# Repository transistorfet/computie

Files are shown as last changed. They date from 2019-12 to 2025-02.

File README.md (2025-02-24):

Computie68k
===========

###### *Started October 03, 2019*

Computie is a series of single board computers using the 68010 and 68030 CPUs, along with a simple unix-like
operating system written in C, with preemptive multitasking via a timer interrupt provided by the 68681
serial port controller that is common to all boards.

k30-SBC is the newest board, using a surface-mount 68030 CPU, 2MB of Static RAM, 512KB of Flash for the boot
software and monitor program, and a CompactFlash slot.

68k-SBC is a single board computer with a 68010 CPU, 1MB SRAM, 1MB Flash, and a 68681 Dual UART controller.

68k-SMT is a mostly identical design using SMT and PLCC components.  A CompactFlash card slot has been added
to this version, but it is also possible to connect a simple breadboarded version to 68k-SBC.

For more details on how I got up and running, check out [Bootstrapping a Homebuilt Computer Using An Arduino](https://transistorfet.github.io/posts/2021-09-bootstrapping_with_arduino.html)

For instructions on getting a board set up and software compiled, check out [INSTALL.md](https://github.com/transistorfet/computie/blob/main/INSTALL.md)

This repository uses git submodules, and can be cloned using:
```
git clone --recurse-submodules git@github.com:transistorfet/computie.git
```

ComputieVME - The Next Generation
---------------------------------

The next iteration of this project is ComputieVME, a VME-based MC68030 CPU card, which is part of
the [Retroverse](https://github.com/transistorfet/retroverse/) project, along with a number of other
VME-based components.  The new system also runs the
[Gloworm](https://github.com/transistorfet/gloworm/) operating system.  Development is ongoing and
details can be found in the github repo or at
[jabberwocky.ca](https://jabberwocky.ca/projects/retroverse/).  I also live streamed some of the
designing and building process, with recordings available at
[youtube.com/@transistorfet](https://www.youtube.com/@transistorfet)

The Operating System (Gloworm)
------------------------------

[Gloworm](https://github.com/transistorfet/gloworm/) (now in a separate repository) is largely based on reading
Operating Systems Design and Implementation 2ed by Andrew S. Tanenbaum, although I've gone with a monolithic design, at
least for the time being, for the simplicity of it.  It can do preemptive multitasking using the 68681 timer.  It also
has an implementation of the minix version 1 filesystem, which uses RAM (through a device driver) to store the data, or
a Compact Flash card connected as an IDE device.  The second serial port can be configured as a SLIP device, with a
basic implementation of UDP and TCP through a BSD sockets-style API, and an NTP command is provided for updating the
system time on boot (when booting from disk).

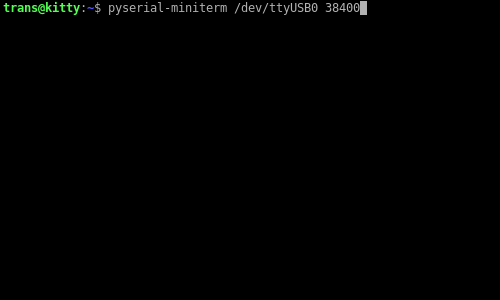
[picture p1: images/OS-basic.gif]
OS


The above video shows connecting over serial from a modern PC and resetting the hardware to run the monitor in ROM
which displays the welcome message.  The kernel is already loaded in RAM, so running the boot command will boot
the kernel which then starts the shell.  From the shell, some basic file operations and the ps command are shown.

The k30 Single Board Computer
-----------------------------

The k30 is the latest version, using a 68030.  It has 2MB SRAM, 512KB Flash, a 68681 Dual UART, and a CompactFlash.
It's as similar to 68k-SMT as possible while still upgrading the CPU.  It doesn't use a programmable logic device for
the glue logic as many similar projects use, instead opting for eleven 74 series logic chips.  It still manages to
use the full 32-bit data bus for RAM, but only one flash chip is used which has an 8-bit data bus in order to reduce
complexity.  Most of the software will be run from RAM, so this shouldn't be a problem.

[k30 Schematics](https://github.com/transistorfet/computie/raw/main/hardware/k30-SBC/k30-SBC.pdf)

DIP switches are used to select the time delay to use for the CompactFlash card (which is interfaced directly to the
CPU), to enable the bus error watchdog timer, and to enable/disable the cache and MMU features.

k30 Revision 2
--------------

This revision fixes the issues of the previous one.  The compact flash card can now be accessed, and the OS is able
to boot entirely from the compact flash card without issue.

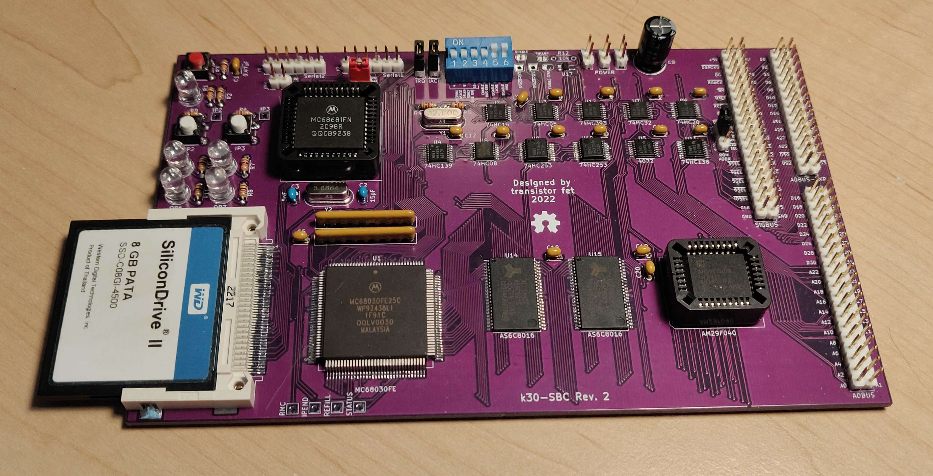
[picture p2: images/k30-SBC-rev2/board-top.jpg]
k30-SBC Rev. 2 Assembled Board


k30 Revision 1
--------------

I made a mistake and used the wrong size footprint for the two 74HC253s, which only come in a 16SSOP package and not
the TSSOP package used by the other logic chips.  The footprint used were 4.9 mm wide but should have been 6.2mm.
Luckily I managed to bend the pins under the body of the chips which was enough to get all the pins touching all the
pads.  It was very tricky to solder, and there was a bridge between DS3 and ground which was very difficult to get
unstuck, but it's working now.

I also made a mistake in the DSACK signals used to terminate a memory cycle, specifically for the compact flash card.
The logic was inverted, so the card was inaccessible, and my attempts at fixing it fried the clock, although it might
have just been the crystal.  I set the project aside for a while and then made a new revision.  For details on the
issues, see the [errata](https://github.com/transistorfet/computie/raw/main/hardware/k30-SBC/revisions/k30-SBC-rev1-errata.txt)

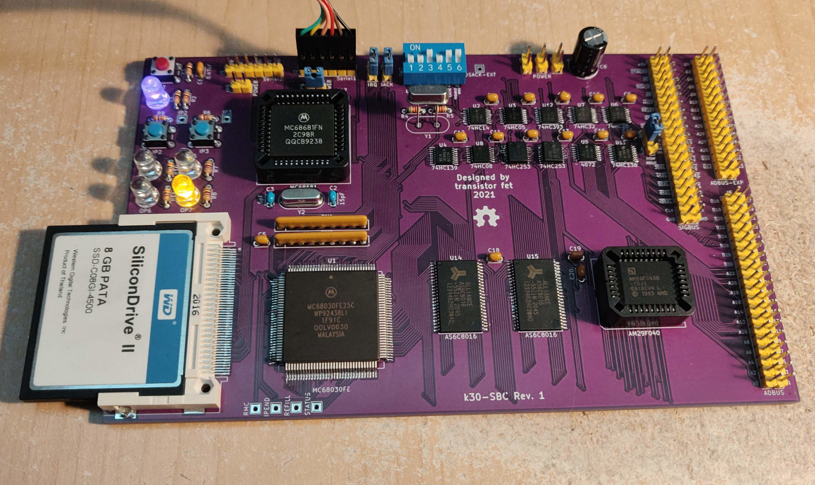
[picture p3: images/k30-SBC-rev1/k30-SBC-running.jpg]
k30-SBC Running

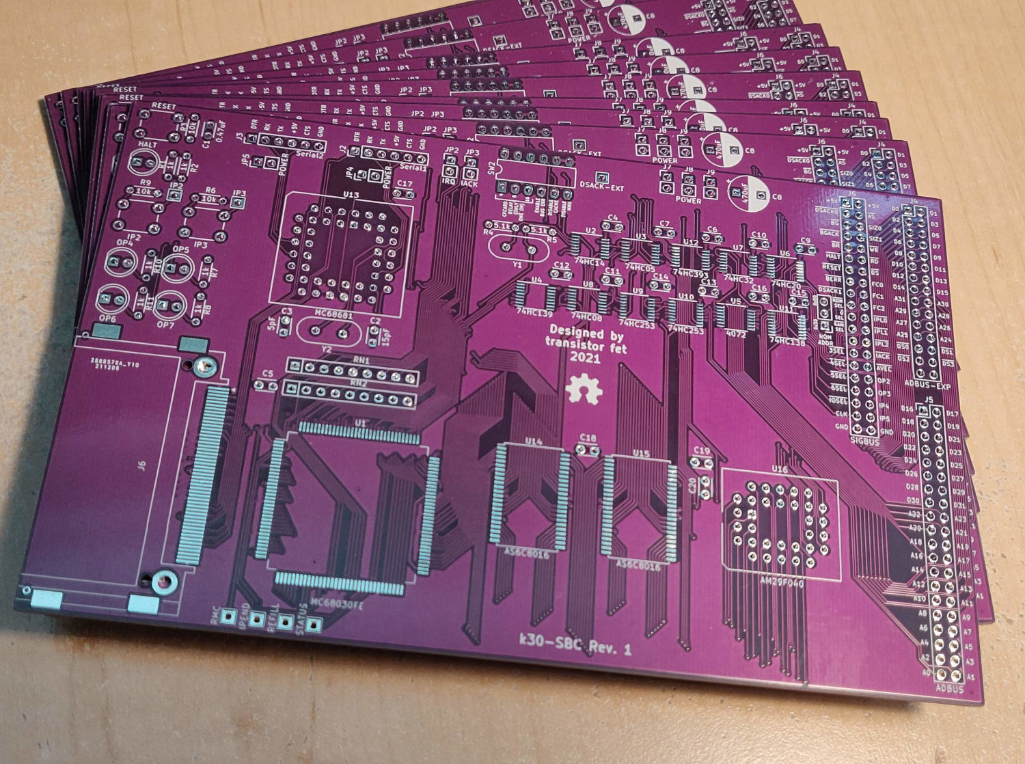
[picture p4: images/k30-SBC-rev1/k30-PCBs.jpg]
k30-SBC Rev. 1 PCB


The 68k Single Board Computer
-----------------------------

A simple single board computer using a Motorola 68010 CPU, which can connect to a host computer via USB/TTL-Serial.
It has a bus for connecting a supervisor arduino or expansion devices, but it can operate standalone using the onboard
UARTs.  It has 1MB of onboard Flash, 1MB of onboard SRAM, and a 68681 Dual UART chip with GPIO.  Some of the GPIO
pins are wired to 4 general purpose LEDs and 2 general purpose buttons.

[68k Board Schematics](https://github.com/transistorfet/computie/raw/main/hardware/68k-SBC/68kBoard.pdf)

The serial ports require external TTL-to-something conversion and are designed to be used with an FTDI USB-to-Serial
cable or adapter.  Two optional jumpers can be used to supply power to the board from one of the USB ports (only one
should be jumped at a time, and only if the onboard power supply is disconnected).  It typically takes about 365mA at
5V to power.

Two jumpers are provided to select what address the ROM will appear in (either 0x0000 or 0x2000), and whether to enable
onboard DTACK generation for address space 0x0000.  By moving the ROM to 0x2000 and disabling DTACK in 0x0000, a
connected arduino can boot the 68000 directly.

I decided to use discrete 74 Series chips for the glue logic to keep it simple and easy for others to build.  I tried
to minimize the amount of logic chips needed, so it doesn't have a watchdog timer to trigger a bus error when an
unmapped address is accessed.

It's currently clocked at 12MHz, although there seems to be an issue with the arduino's DTACK generation at that speed.
It previously was working at 10MHz on the rev0 board.

The SBC version uses all DIP packaged chips and through-hole parts.  The SMT version uses surface mount chips for the
logic and ram, and PLCC packaged chips for the rest.  A CompactFlash socket and a 74HC32 to accommodate it has been
added and the power supply has been removed, but it is otherwise the same design.

SMT Revision 1
--------------

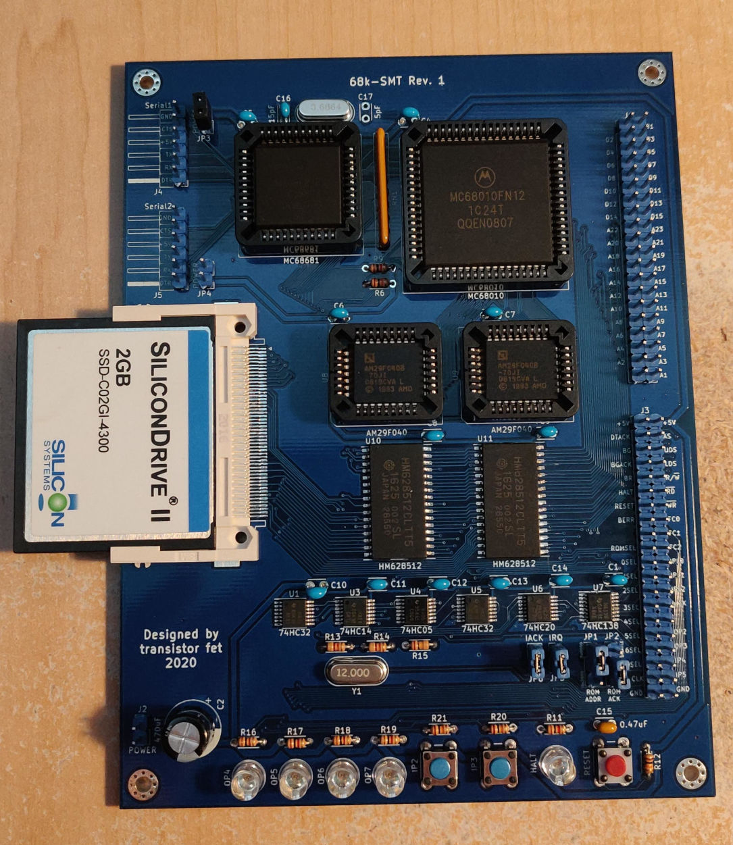
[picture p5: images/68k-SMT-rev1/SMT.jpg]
68k-SMT Rev. 1

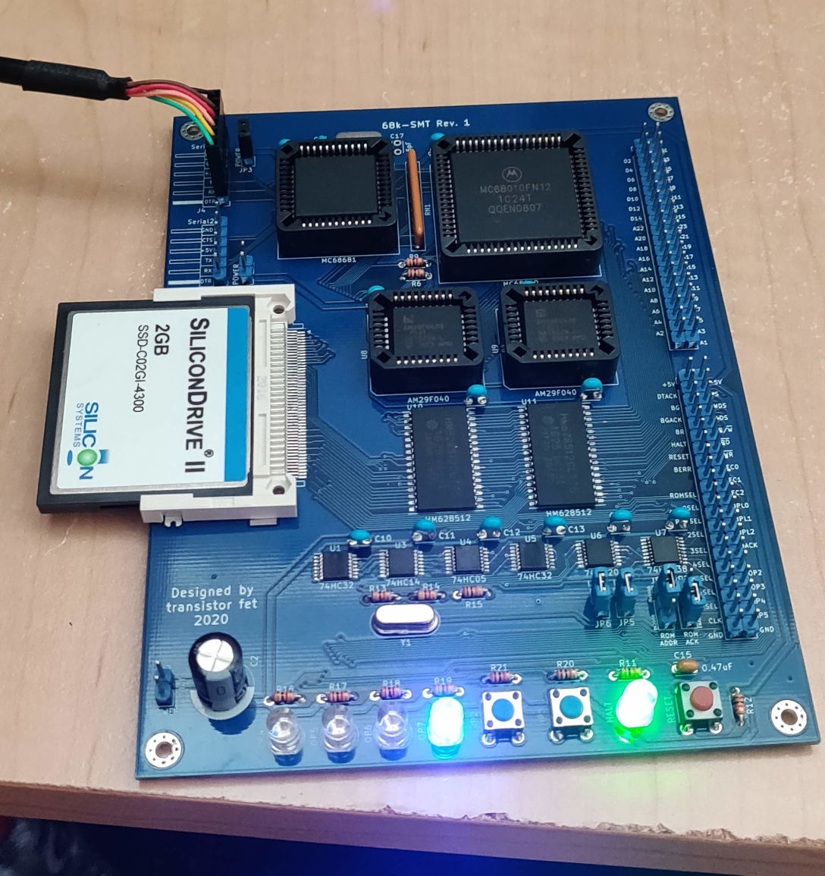
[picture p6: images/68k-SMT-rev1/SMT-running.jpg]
68k-SMT Running


SBC Revision 2
--------------

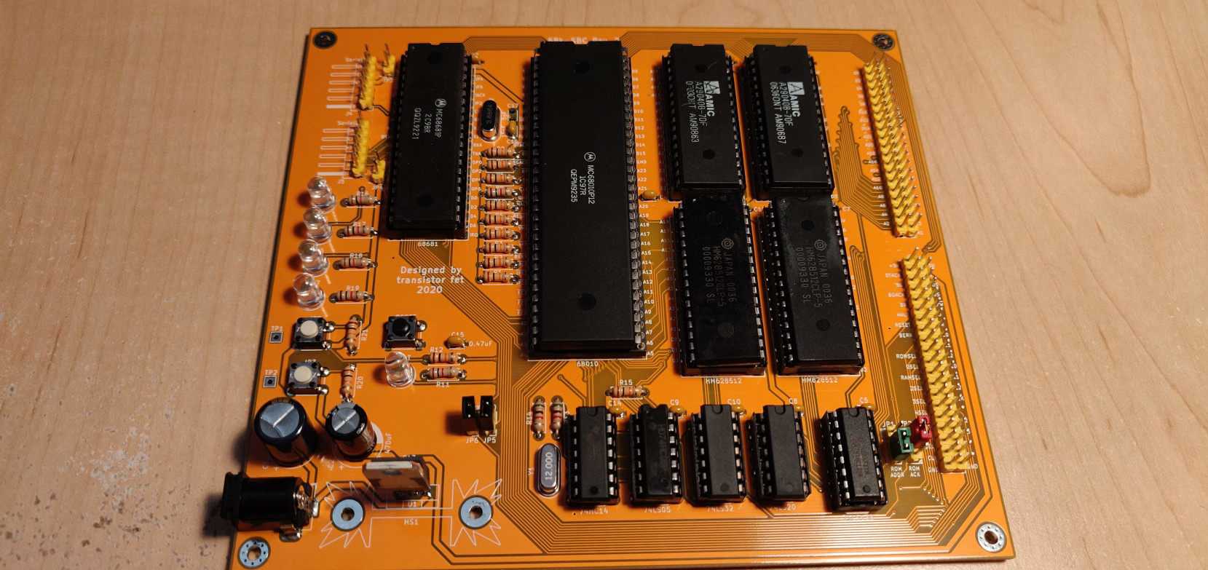
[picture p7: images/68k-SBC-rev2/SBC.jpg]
68k-SBC Rev. 2

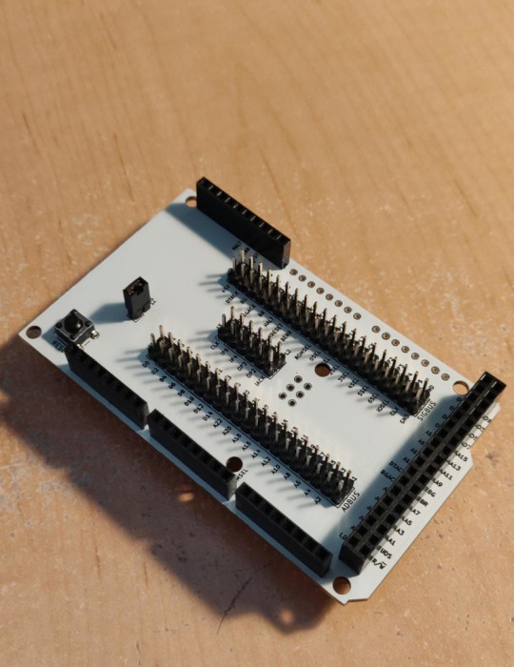
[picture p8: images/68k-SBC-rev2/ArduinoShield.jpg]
Supervisor Arduino Shield

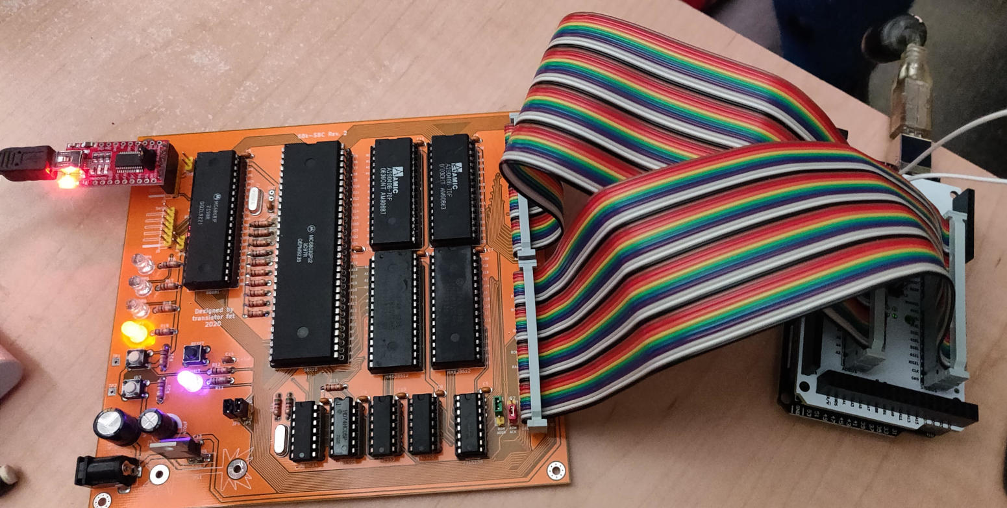
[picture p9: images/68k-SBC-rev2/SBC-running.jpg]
68k-SBC Running

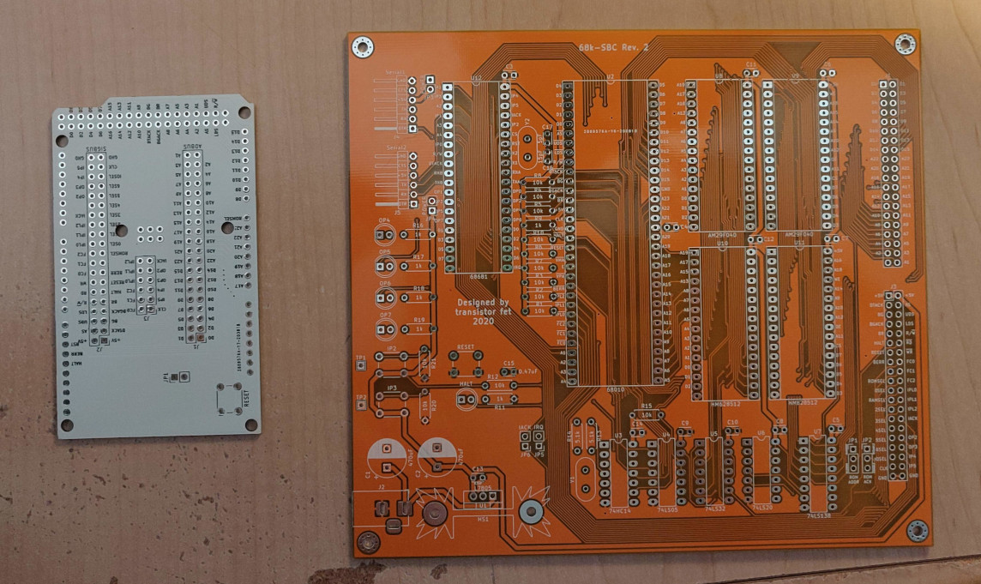
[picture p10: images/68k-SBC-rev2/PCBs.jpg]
68k-SBC PCBs


SBC Revision 0
--------------

This version has 64KB of EEPROM instead of Flash, and doesn't have onboard interrupt circuitry.  It started off with a
68000 CPU, but that was later upgraded to a 68010 to allow for relocatable interrupt tables when using off-board
interrupt circuitry.

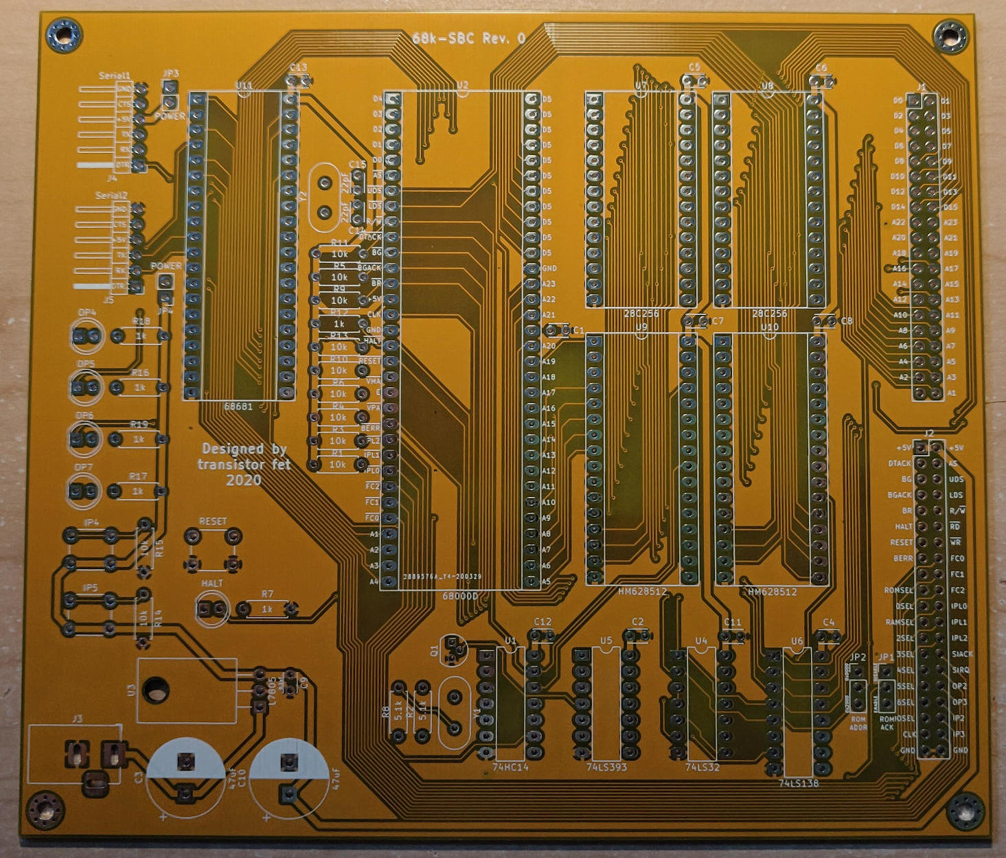
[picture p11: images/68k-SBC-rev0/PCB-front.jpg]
68k-SBC PCB Front

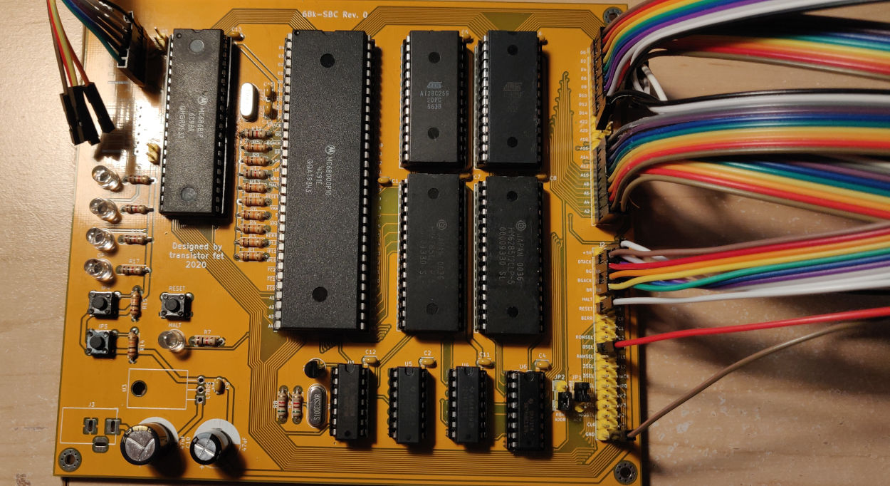
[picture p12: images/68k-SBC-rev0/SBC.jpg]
68k-SBC

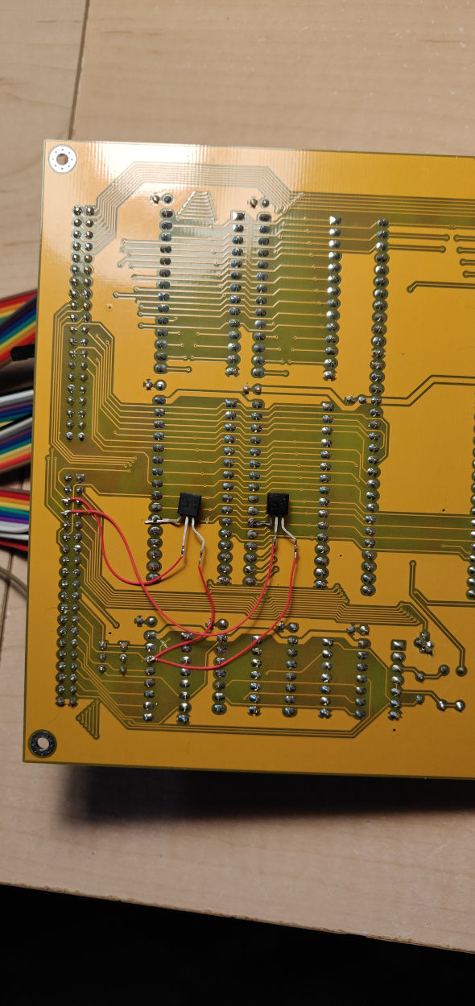
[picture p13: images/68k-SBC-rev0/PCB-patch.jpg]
68k-SBC patch for design mistake


I made a mistake and left out the logic for LDS/UDS in the chip select for the high and low memory chips.  When writing
a single byte to memory, it would also attempt to write to both the high and low chips, instead of only one.  Thanks to
a poster on EEVblog who suggested patching it with a P-channel MOSFET shown soldered to the back of the SRAM chips to
interpose the UDS/LDS signals into the chip selects, with the original traces cut.

Breadboard Version
------------------

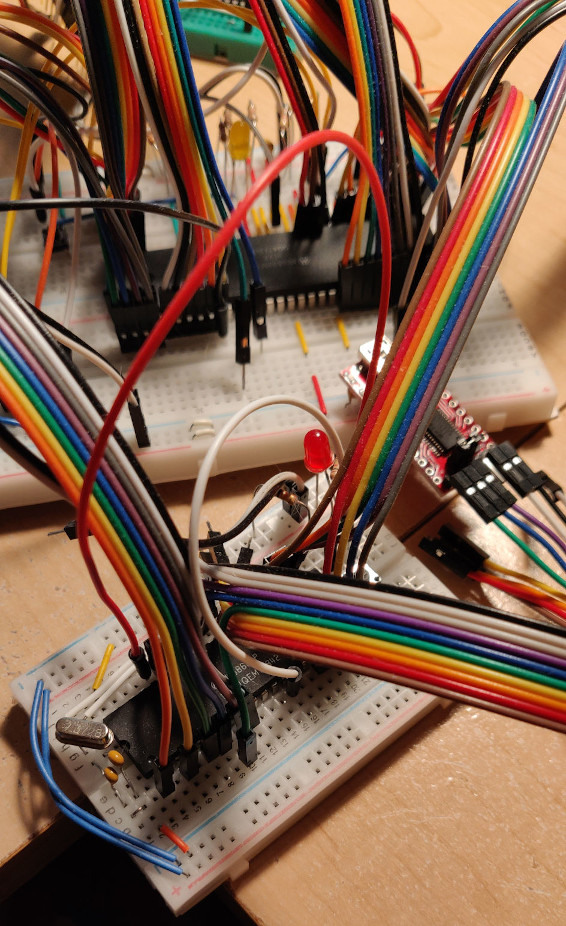
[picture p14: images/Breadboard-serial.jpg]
68k-SBC Breadboard


Operating System Booting From Monitor/Compact Flash on 68k-SMT
--------------------------------------------------------------

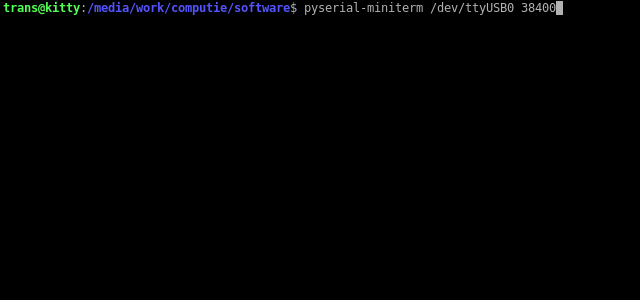
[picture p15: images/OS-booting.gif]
OS Booting


The above video shows connecting over serial from a modern computer after first powering the board on.  The monitor
runs first, giving the ">" prompt.  The bootloader has been burnt into flash at address 0x20000.  From the monitor, the
boot loader is run, which then loads the kernel from the attached compact flash card.  Each period (.) character
printed represents 1 kilobyte of data loaded from disk).  The boot loader then jumps to the loaded kernel, which
displays boot messages before running the init process from disk.  The init process first runs `sh /etc/rc`", which runs
the ntpdate command to update the system time.  It then runs an interactive shell.

Some commands are shown after boot, and then the httpd program is run (which has forking disabled for the time being).
From another computer, the curl command is run to issue a request to the board.  The httpd program responds with the
data "This is a secret message"

References
----------

- [S-100 68000 CPU Board](http://s100computers.com/My%20System%20Pages/68000%20Board/68K%20CPU%20Board.htm)
- [Tiny68K, 68000 SBC](https://www.retrobrewcomputers.org/doku.php?id=boards:sbc:tiny68k)
- [Motorola 68000 computer](https://hackaday.io/project/7242-motorola-68000-computer)
- [68k Single Board Computer](https://www.kswichit.com/68k/68k.html)
- [Kiwi - a 68k Homebrew Computer](https://www.ist-schlau.de/hardware.html)

- [ECB KISS-68030](https://www.retrobrewcomputers.org/doku.php?id=boards:ecb:kiss-68030:start)
- [Gryphon 68030](https://www.retrobrewcomputers.org/doku.php?id=boards:sbc:gryphon_68030:start)
- [T030](https://hackaday.io/project/9439-t030)
- [Building a 68030 computer in 5 stages](https://hackaday.io/project/164041-building-a-68030-computer-in-5-stages)
- [Blitz - 32bit 68030 homebrew with an ISA bus](https://blog.notartyoms-box.net/blitz/)

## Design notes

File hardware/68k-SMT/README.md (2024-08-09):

68k-SMT
=======

Status: Built & Tested

Latest: Rev.1

### About
This is an almost identical version as the 68k-SBC Rev.2 but using either PLCC chips or surface
mount chips, and with the addition of a CompactFlash card slot.  This was the first board I made
with surface mount chips, and I pushed myself a bit with the TSSOP logic chips, which were the
hardest to solder.  The CompactFlash socket was the easiest to solder because it has holes that
aligned the pins with the pad perfectly.  I also had issues with taking too much solder off the
memory chips causing micro-fractures in the solder that resulted in crashing/locking up.

The goal here was to learn surface mount soldering techniques so that I could attempt a 68030 based
design.  I had lots of $10 QFP package 68030s, but the PGA packages were about 4 times the price,
plus about $10 CAD including shipping and duties for a PGA socket (which is this [128-pin 13x13 PGA
socket](https://www.peconnectors.com/sockets-pga-cpu-and-memory/hws4514/)

[Revision 1 Notes & Errata](revisions/68k-SMT-rev1-errata.txt)

[Revision 1 Schematic](revisions/68k-SMT-rev1.pdf)

[Revision 1 Gerbers](revisions/68k-SMT-rev1.zip)


68k-SMT board hooked up to USB via an FTDI integrated cable, which is supplying power to everything, and with the right most of 4 clear LEDs glowing blue, and the power indicating LED on the left glowing green
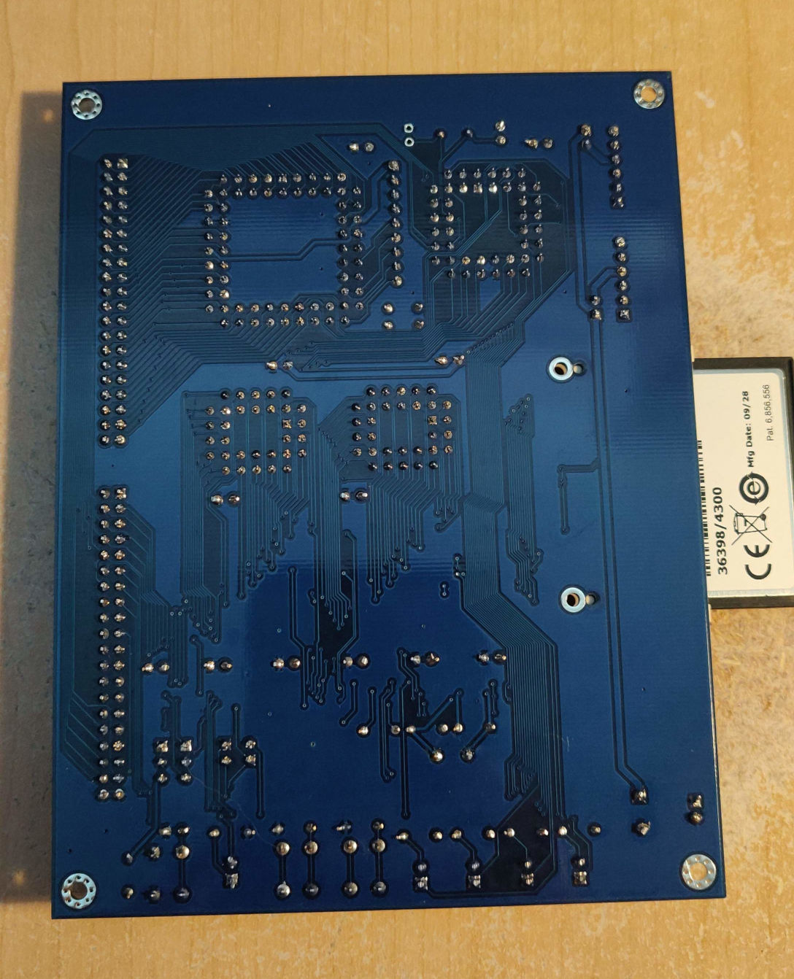
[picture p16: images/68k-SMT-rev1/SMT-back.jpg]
Backside of the 68k-SMT board showing the through-hole solder connections and blue solder mask, but there is no silk screen


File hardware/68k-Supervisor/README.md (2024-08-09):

68k-Supervisor
==============

Status: Built & Tested

Latest: Rev.2

### About
An arduino shield for the Arduino Mega 2560 with two 40-pin connectors that match the two 40-pin
expansion headers of the computie single board computers (68k-SBC, 68k-SMT, and k30-SBC with
rework).

### 68k-SBC and 68k-SMT

Use the [68kSupervisor](../../software/arduino/68kSupervisor) sketch to program the flash
in-circuit, debug the CPU, or host memory and serial I/O access via the memory bus.  Make sure to
set the 68k-* board jumpers correctly for DTACK and the RAM location if debugging or hosting with
the supervisor.

### k30-SBC

This PCB requires some changes before it can be used with the k30-SBC:
    - Address 0 on the ADBUS 40-pin connector (Pin 39) should be wired to Digital Input #9 (D9) of the
      Arudino
    - the WR pin on the SIGBUS 40-pin connector (Pin 14) should be wired to Digital Input #8 of the
      Arudino (D8).  It was a duplicate of R/W on the 68k-* boards, but it's now the DS (data strobe)
      signal from the 68030 on the k30-SBC
The [k30FlashWriter](../../software/arduino/k30FlashWriter) sketch should be used, which will only
allow running or suspending the CPU, and writing to the flash chip in-circuit to bootstrap the
board.  The debugging feature has been removed since it didn't work correctly at the 12MHz speed
that the 68030 is running at.  The k30 board only has one 512kB of flash in a single 8-bit wide
chip, instead of two flash chips in parallel to fit the 16-bit interface of the 68010 that the 68k-*
boards have, which is why this alternate flash writing sketch is needed.  The reworked shield can
still work with the 68kSupervisor sketch to communicate with the 68k-* boards.

[Revision 2 Schematic](revisions/68kBoardSupervisorShield-rev2.pdf)

[Revision 2 Gerbers](revisions/68kBoardSupervisorShield-rev2.zip)

An arduino shield for the Arduino Mega 2560 printed with white solder mask, and with two 40-pin headers down the middle which connect to the expansion interface on the computie single board computers

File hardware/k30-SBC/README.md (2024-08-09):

k30-SBC
=======

Status: Built & Tested

Latest: Rev.2

### About
A single board computer with DIP packaged chips.  The only programmable chip is the flash memory, which can
be written in-circuit using the Ardunio-based supervisor shield.

[Revision 2 Notes & Errata](revisions/k30-SBC-rev2-errata.txt)

[Revision 2 Schematic](revisions/k30-SBC-rev2.pdf)

[Revision 2 Gerbers](revisions/k30-SBC-rev2.zip)

k30-SBC board, which is 160mm x 100mm with a purple coloured solder mask and white pin headers, fully populated with all components, and with a CompactFlash card in the slot on the bottom left with a white and blue label that reads WD SiliconDrive II 8 GB PATA
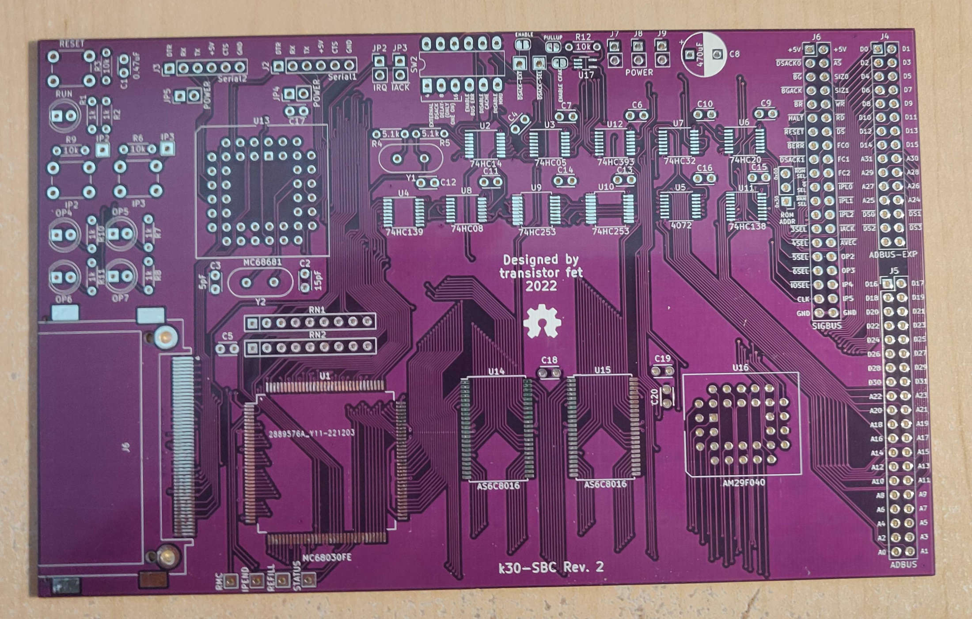
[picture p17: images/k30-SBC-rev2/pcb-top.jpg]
k30-SBC board unpopulated, showing the purple solder mask and white silk screen labels


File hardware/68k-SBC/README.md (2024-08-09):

68k-SBC
=======

Status: Built & Tested

Latest: Rev.2

### About
A single board computer with DIP packaged chips.  The only programmable chip is the flash memory, which can
be written in-circuit using the Ardunio-based supervisor shield.

[Revision 2 Notes & Errata](revisions/68kBoard-rev2-errata.txt)

[Revision 2 Schematic](revisions/68kBoard-rev2.pdf)

[Revision 2 Gerbers](revisions/68kBoard-rev2.zip)

68k-SBC board, with an orangey-yellow coloured solder mask, fully populated with all components
68k-SBC board hooked up to USB via an FTDI serial converter and with the Ardunio supervisor shield connected via two rainbow-coloured 40-pin ribbon cables connected to the PCB, and the Ardunio connected by a USB cable to a computer, which is supplying power to everything

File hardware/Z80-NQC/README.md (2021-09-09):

The Z80 Not Quite Computer
==========================

A simple platform for experimenting with Z80 CPUs.  The Z80Proto board has a Z80 CPU, with a 32KB SRAM chip and a 32KB EEPROM
chip, along with a bus of pins for connecting to other things.  It also has a simple clock circuit that can optionally be used.
It does not have any onboard I/O, or an onboard power supply (hence why it's not quite a computer).  The intention is to connect
the bus pins to an Arduino Mega, which acts as a supervisor, controlling the CPU through the BUSREQ and RESET lines, and
emulating I/O devices.  It was made partly to try out some 3rd party PCB manufacturers and partly because of signal issues when
breadboarding circuits with so many wires, which was causing memory read errors.

Z80Supervisor is an arduino program which can run or stop the CPU, and read and write to memory directly (when the CPU is
suspended).  It is also able to respond to memory bus requests from the CPU, as long as the CPU is running with a slow clock.
It can both act as a ROM, serving up a Z80 program, and act as an I/O device by forwarding bytes on to the arduino's serial
port.

Z80Monitor contains programs that run on the Z80, which can either be loaded into the EEPROM, or served by the supervisor.

Schematic
---------

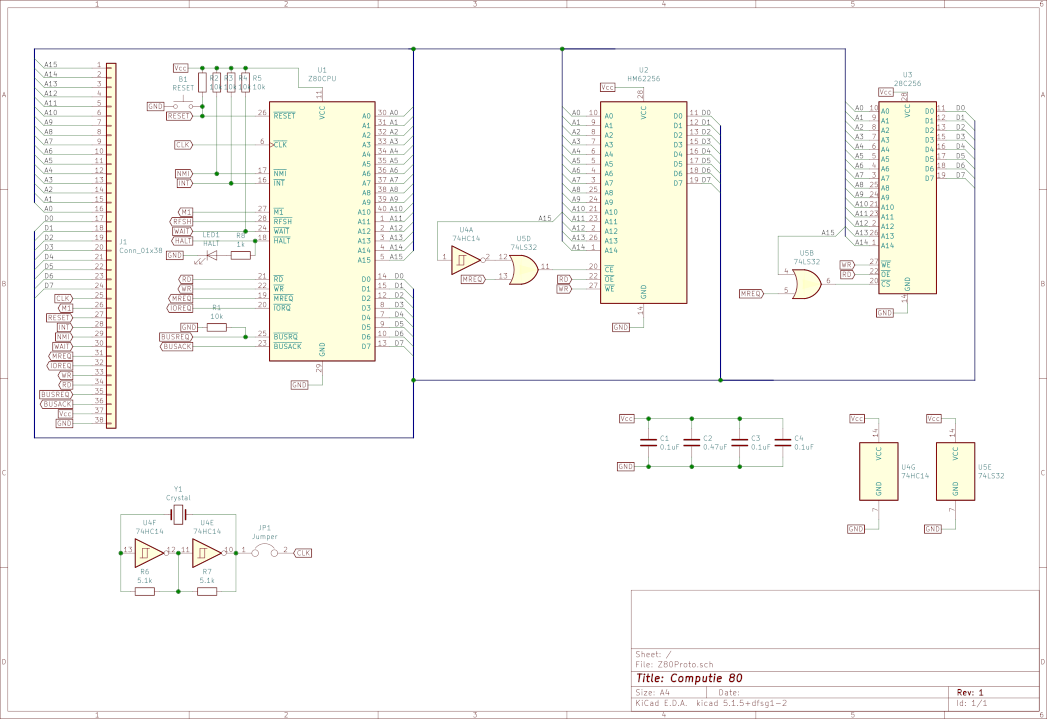
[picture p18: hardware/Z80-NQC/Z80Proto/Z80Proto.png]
Z80 NQC Proto Board


Board
-----

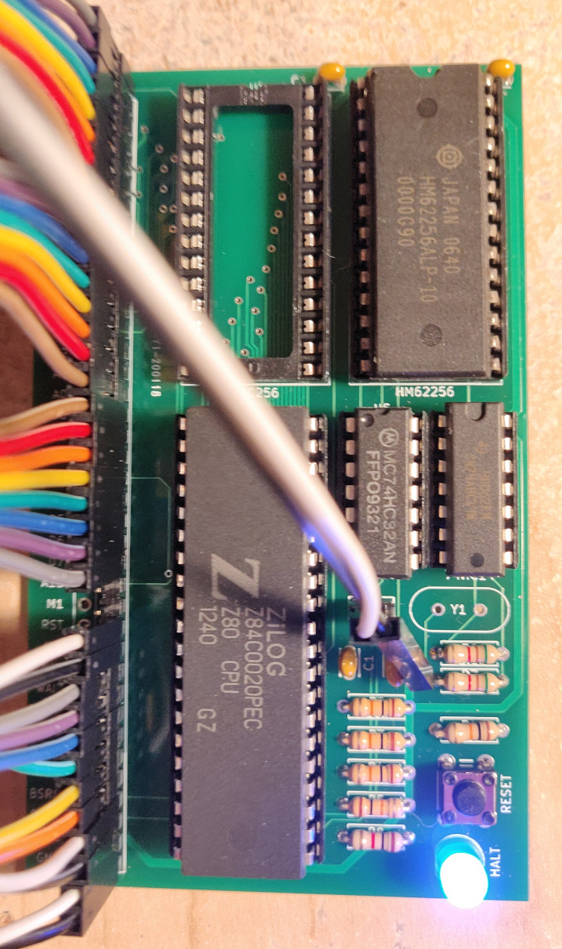
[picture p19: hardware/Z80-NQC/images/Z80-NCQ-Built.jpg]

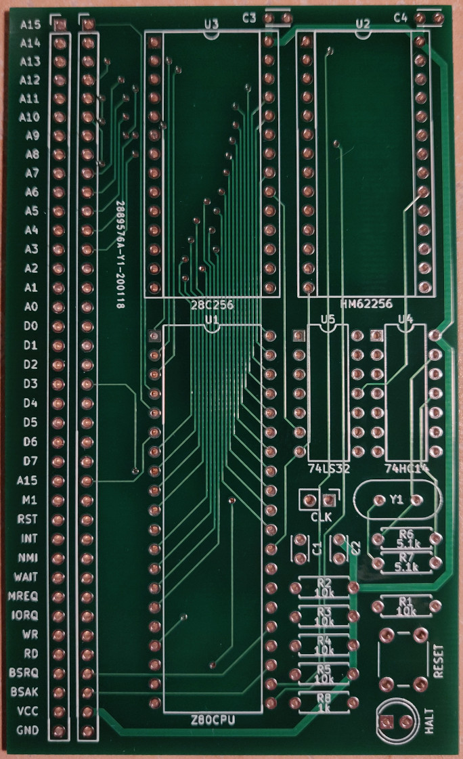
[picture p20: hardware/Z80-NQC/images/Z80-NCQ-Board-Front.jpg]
Z80 NQC Proto Board

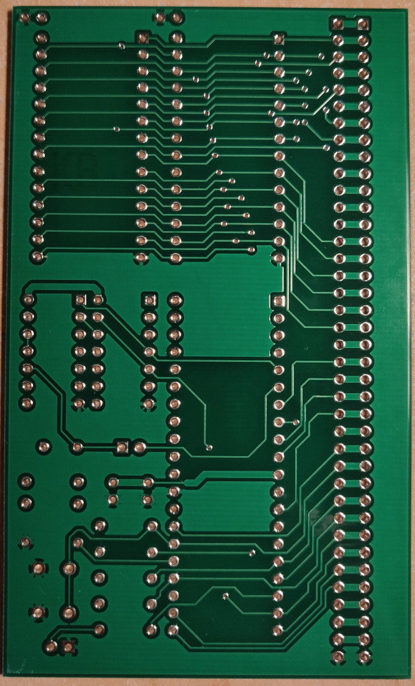
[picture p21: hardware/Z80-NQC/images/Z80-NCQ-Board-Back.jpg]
Z80 NQC Proto Board


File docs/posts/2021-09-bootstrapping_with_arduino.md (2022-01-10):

Bootstrapping a Homebuilt Computer Using An Arduino
===================================================

*Also available on [dev.to](https://dev.to/transistorfet/bootstrapping-a-homebuilt-computer-using-an-arduino-4hpf)*

###### *Written September 2021 by transistor_fet*

Over the last couple of years I've been working on a series of projects to build my own computer
from scratch.  It had been a dream of mine when I first started learning about computers and
electronics to build my own computer, and I tried designing some on paper with what I knew, but such
a complex project was out of reach at the time.  I've learned so much in the many years since then
and after seeing the awesome project [PDP-11/Hack](https://www.5volts.ch/pages/pdp11hack/), I
thought you know, why not try fiddling with CPUs again and see how far I get, just for the fun of
it.

As I thought about how to approach the problem of getting a program into a minimal system built on a
breadboard, I thought perhaps I could use an Arduino Mega, with it's multitude of I/O pins.
Initially I thought I could use it to program a Flash or EEPROM chip separately, but after thinking
about it a bit, I realized I could program a RAM chip in the same circuit as the CPU.  What follows
is my journey towards building my first single board computer through incremental experimentation.

The Chips
---------

PDP-11/Hack is based around an old PDP-11 processor module that was bought online on Ebay.  I hadn't
thought about buying used parts online before since I didn't expect them to work, but that got me
searching around for what was available.  While Ebay had many used chips, especially the less common
ones, AliExpress had the best deals, with lots of old 8-bit CPUs, memory chips, and peripheral
controllers, sometimes for less than a dollar a chip.  I figured I'd order some and see if I could
get them working.  To my surprise, a fair number of the chips I received worked as expected, even
the ones that were clearly relabelled.  For more information on relabelled and counterfeit chips,
check out this great video about ["Fake Chips"](https://www.youtube.com/watch?v=k72SFBOZ_lw) by
David Viens, discussing this problem with popular audio synth chips.  In my various purchases of
used chips, the audio chips were most likely to be counterfeit due to the large demand for them and
the higher prices they fetch.  Some of the CPU and memory chips that I received were also
counterfeit but they tended to still be functional.  The date codes would often be changed, with
each chip in the lot having the same date code, and in the case of the memory chips, sometimes a
compatible memory chip of the same size would be relabelled as a more popular part number, such as
the popular HM628512 static RAM chip.

I ordered some Z80s, 6502s, 65816s, 68000s, 68010s, 8088s, and 8086s, as well as some peripheral
chips for each CPU, some memory chips, and various speeds of crystals.

The First Fiddlings
-------------------

While waiting for my first orders of chips to arrive, I searched though the various old chips that I
had scavenged from disassembled equipment over the years.  I happened to have a [Mitsubishi
M5M5118P](https://datasheet.octopart.com/M5M5118P-Mitsubishi-datasheet-154393393.pdf) Static RAM
chip on-hand, which is organized as 2 kilobytes of 8-bits.  I wired each address and data pin, as
well as the W (write) and S1 (chip select 1) pins, to pins on the Arduino Mega.  For the S2 (chip
select 2) pin, I wired it to ground so that only S1 needed to be brought low to start a transfer.
For the address and data pins, I made sure to use the [arduino
pins](https://www.arduino.cc/en/Hacking/PinMapping2560) that correspond to specific hardware port
registers so that I could write directly to the ATMega's PORTx registers to set all 8 bits at once.

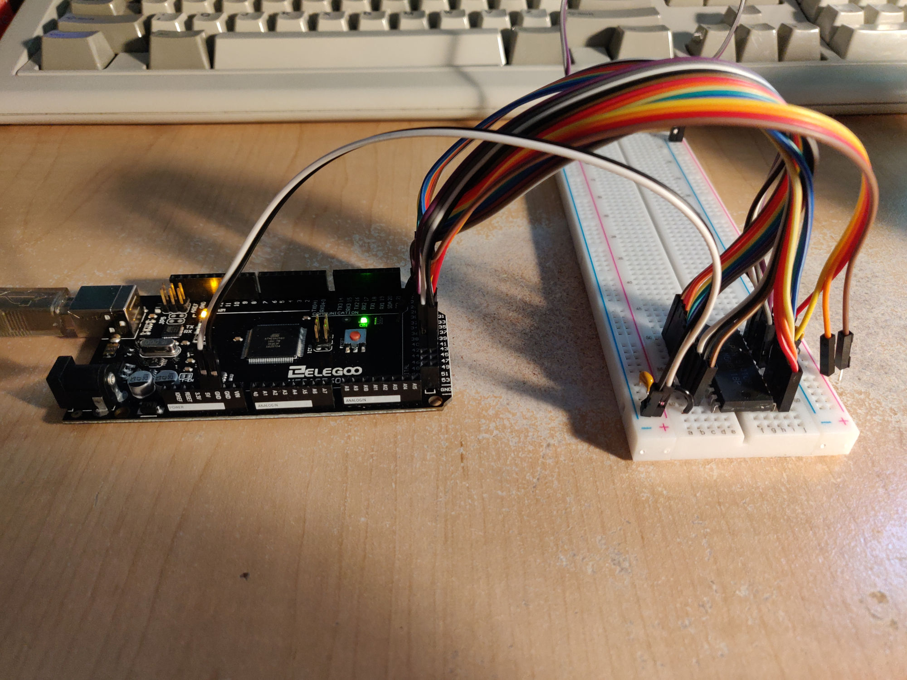
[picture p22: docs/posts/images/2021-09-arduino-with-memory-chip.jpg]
Arduino With RAM


The code first initializes the I/O pins.  Port A has the 8 data pins connected to it, with Port L
and C used for the upper and lower address pins respectively.  The chip select and write pins use
arduino `digitalWrite()` functions since we only need to set 2 bits per request, and it's a bit
easier to understand and edit than bit operations on the PORTG register.  (The `MEM_RD` pin is left
disconnected for the M5M5118P, but it is used by some chips, so I've left it in the code).
```cpp
#define MEM_CS      39      // PG2
#define MEM_RD      40      // PG1
#define MEM_WR      41      // PG0

// Address Bus
PORTL = 0x00;               // A8 - A15
DDRL = 0xFF;                // Configure as outputs
PORTC = 0x00;               // A0 - A7
DDRC = 0xFF;                // Configure as outputs

// Data Bus
PORTA = 0x00;               // D0 - D7
DDRA = 0x00;                // Configure the data bus as inputs by default

// Controls
pinMode(MEM_CS, OUTPUT);
pinMode(MEM_RD, OUTPUT);
pinMode(MEM_WR, OUTPUT);
digitalWrite(MEM_CS, 1);    // Each control signal is normally-high,
digitalWrite(MEM_RD, 1);    // active-low, so set them all to "high"
digitalWrite(MEM_WR, 1);    // to disable the chip
```

The data written to each memory address during the write test will be the lower byte of the address,
so the data returned should be a sequence of numbers from 0x00 to 0xFF
```cpp
PORTA = 0x00;
DDRA = 0xFF;                    // Set the PORTA pins to "output" mode
for (int i = 0; i < 2048; i++) {
    PORTL = (i >> 8);           // Set the upper address bits
    PORTC = 0x00FF & i;         // Set the lower address bits
    PORTA = (i & 0x00FF);       // Set the output data byte
    digitalWrite(MEM_WR, 0);    // Set the WR and CS pins to low to start a memory write
    digitalWrite(MEM_CS, 0);
    //delayMicroseconds(1);     // Optional delay for slower chips
    digitalWrite(MEM_WR, 1);    // Set the WR and CS pins high to end the memory write
    digitalWrite(MEM_CS, 1);
}
```

The data is then read back and printed to the arduino serial monitor.  When a byte is read that
doesn't match the lower byte of that address, it's recorded as an error and displayed at the end.
This will give us an indication if there was a glitch during reading or writing, or if the cell is
not working properly, although it's not a conclusive test because only one value is tested per cell.
```cpp
byte value;
int errors = 0;

PORTA = 0x00;
DDRA = 0x00;                    // Set the PORTA pins to "input" mode
for (int i = 0; i < 2048; i++) {
    PORTL = (i >> 8);           // Set the upper address bits
    PORTC = 0x00FF & i;         // Set the lower address bits
    digitalWrite(MEM_RD, 0);    // Start a memory read by setting CS and RD low
    digitalWrite(MEM_CS, 0);
    //delayMicroseconds(1);     // Optional delay for slower chips
    value = PINA;               // Read in the data and store in temporarily
    digitalWrite(MEM_RD, 1);    // Stop the memory read by setting CS and RD high
    digitalWrite(MEM_CS, 1);
    
    if (value != (i & 0x00FF))  // If the value isn't the expected value, record as an error
        errors += 1;
    Serial.print(value, HEX);   // Print the value read in hexadecimal
    Serial.print(" ");
    if (i % 64 == 63)           // Wrap the output line every 64 bytes for readability
        Serial.print("\n");
}

Serial.print("\n");
Serial.print("Errors: ");
Serial.print(errors, DEC);
Serial.print("\n");
```

The complete [MemTest](https://github.com/transistorfet/computie/blob/main/software/arduino/MemTest/MemTest.ino) code

I tried running this code on a few different memory chips and most chips had no errors.  When a chip
was broken, it would often contain either entirely random or all zero data and no cells would write.
After a while I started noticing glitches where a couple of cells would produce errors, but it would
often be different cells or different numbers of errors every time I tried to read.  After much
fiddling I found these were caused by poor electrical connections in the breadboard wiring.  This
was a frequent issue throughout this project, but it tended to be intermittent.  I would sometimes
go weeks without a problem, and then have constant glitches for days until I remembered to try
jiggling or rearranging the wires.

I had also gotten some EEPROM chips from AliExpress, which I ran the MemTest code on as well.  They
were quite cheap, so I figured it was worth a try, even though I expected the memory cells to be
worn out.  I was initially surprised that the EEPROMs did often save the data written to them, with
no or almost no errors when read back, with the exception of one batch of chips that were clearly
counterfeit and non-functional.  Sadly though, I found out with 68k-SBC Rev.0, which used the
EEPROMs, that the data would often disappear after a few hours or days.  Luckily I didn't need them
while testing Rev.0, so I didn't bother buying new EEPROMs from digikey, and I switched to Flash
chips for the next revision.

On To Z80s
----------

The Z80 CPUs I had ordered arrived first, so I started with them.  The Z80 has separate pins for the
address and data lines, which simplifies the wiring, and it also has a static core, so running it at
a very low frequency is possible.  I whipped up a simple oscillator using a 555 timer set to
somewhere around 80 Hz (yes singular Hz).

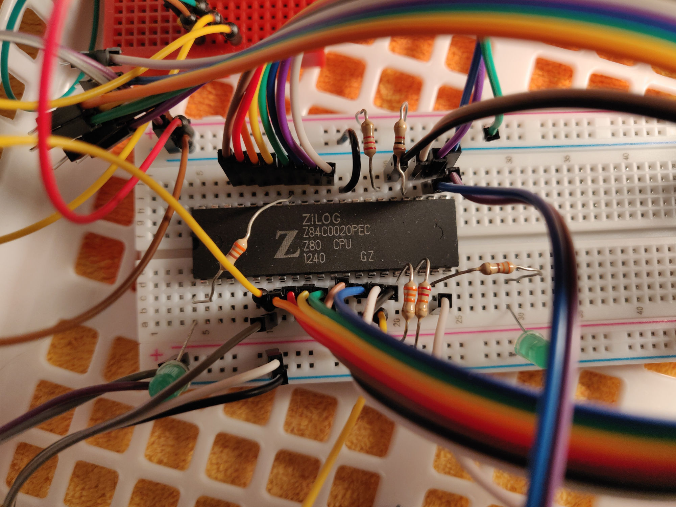
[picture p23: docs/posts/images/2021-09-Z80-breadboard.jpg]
Z80 Breadboard

(This chip turned out to be relabelled.  The black paint on top comes off with acetone or alcohol,
the ejection holes show that it was sanded down, and the date codes of all 10 chips were identical,
despite being desoldered.  They are labelled as being 20MHz, but I never ran them above 1MHz.  They
are definitely a Z80 of some kind, and they worked alright for my experiments, but if you're looking
for a reliable part, beware what you buy)

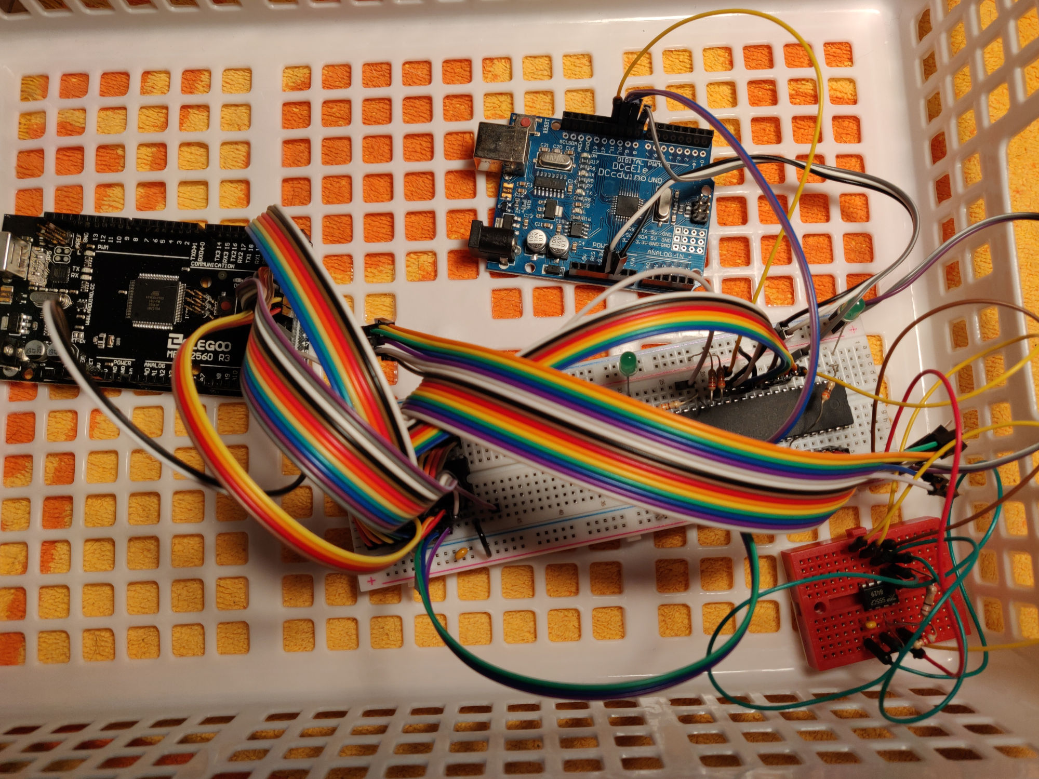
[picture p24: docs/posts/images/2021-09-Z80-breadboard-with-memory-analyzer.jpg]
Z80 Breadboard

The red breadboard has the 555 oscillator on it, and the the other chip with lots of wires going to
it is a memory chip.  The Arduino Uno clone in the picture is being used as a logic analyzer, while
I was waiting for the generic analyzer I had ordered to arrive.

I had originally thought I would program the RAM chips in-circuit with the CPU.  I could use the
CPU's bus arbitration signals to disconnect it from the shared bus while the arduino was writing to
the RAM, and then configure the arduino pins as inputs to effectively disconnect them from the bus
while CPU had control.  While that did work, I realized that perhaps I could directly intercept the
bus requests if the CPU was slow enough, and directly feed bytes of data to the CPU without the
extra step of writing the data to RAM first.  The arduino could assert the WAIT signal to the CPU to
delay the request until it was ready to complete, thus taking as long as it needed to process the
request.  I wouldn't necessarily need a RAM chip at all, and it would make it faster to test an
updated Z80 program.

In order to intercept the transfer, I set up a pin change interrupt in the arduino for the MREQ
input from the CPU, which goes low whenever a byte is read or written by the CPU.  The interrupt
handler would then assert the WAIT signal and check the MREQ, RD and WR signals to figure out what
to do.  In the arduino, there was a large array used as the "virtual" memory.  It could be
pre-initialized with a Z80 program, and any read or write requests would read or write the
corresponding location in the array.  Since the WAIT signal was asserted throughout this, the
arduino could take as much time as it liked, so it was possible to print out debug information to
the arduino's serial monitor.  It would print the address being accessed and the data value either
fetched or written by the bus request.  From this I could see that the CPU was actually executing
the program step by step, and trace which program address was fetched next to confirm the jump and
call instructions were executing as expected.

```cpp
#define Z80_HADDR_PORT  PORTC
#define Z80_HADDR_PIN   PINC
#define Z80_HADDR_DDR   DDRC

#define Z80_LADDR_PORT  PORTL
#define Z80_LADDR_PIN   PINL
#define Z80_LADDR_DDR   DDRL

#define Z80_LDATA_PORT  PORTA
#define Z80_LDATA_PIN   PINA
#define Z80_LDATA_DDR   DDRA

#define Z80_IS_MREQ()   (!(PINB & 0x01))
#define Z80_IS_RD()     (!(PINB & 0x02))
#define Z80_IS_WR()     (!(PINB & 0x04))

#define Z80_SET_WAIT()  ((PINB | 0x08))
#define Z80_CLR_WAIT()  ((PINB & 0xF7))

word mem_size = 4096;
byte mem[4096] = {
// The Makefile that compiles the Z80 program will format the binary as
// C-compatible text which is #included here, so that whenever this arduino
// code is uploaded, it will have the latest Z80 binary image
#include "../Z80Monitor/output.txt"
};

// This interrupt will only be enabled when the CPU is running
// and the arduino is listening for requests ("device" mode)
ISR (PCINT0_vect)
{
    PCICR = 0x00;       // Disable pin change interrupts

    if (Z80_IS_MREQ() && Z80_HADDR_PIN < 0x20) {
        Z80_CLR_WAIT();                     // Assert the wait signal

        // CPU Read Operation
        if (Z80_IS_RD()) {
            register word addr = (Z80_HADDR_PIN << 8) | Z80_LADDR_PIN;
            Z80_LDATA_DDR = 0xFF;           // Configure data bus pins as output

            #if BUS_DEBUG                   // Print debug information
            Serial.write('R');
            Serial.print(addr, HEX);
            if (addr < mem_size) {
                Serial.write('|');
                Serial.print(mem[addr], HEX);
            }
            Serial.write('\n');
            #endif

            if (addr < mem_size)
                Z80_LDATA_PORT = mem[addr]; // Output the requested byte
            else
                Z80_LDATA_PORT = 0x00;      // Output 0 for all other addresses

            Z80_SET_WAIT();                 // Clear the wait signal
            while (Z80_IS_MREQ()) { }       // Wait until the CPU ends the MREQ
            Z80_LDATA_PORT = 0x00;
            Z80_LDATA_DDR = 0x00;           // Configure data bus pins as inputs
        }
        // CPU Write Operation
        else if (Z80_IS_WR()) {
            register word addr = (Z80_HADDR_PIN << 8) | Z80_LADDR_PIN;

            #if BUS_DEBUG                   // Print debug information
            Serial.write('W');
            Serial.print(addr, HEX);
            Serial.write('|');
            Serial.print(Z80_LDATA_PIN, HEX);
            Serial.write('\n');
            #endif

            if (addr < mem_size)
                mem[addr] = Z80_LDATA_PIN;  // Save the byte from the data bus

            Z80_SET_WAIT();                 // Clear the wait signal
            while (Z80_IS_MREQ()) { }       // Wait until the CPU ends the MREQ
        }
    }

    PCIFR = 0x00;       // Clear pin change interrupt flag
    PCICR = 0x01;       // Enable pin change interrupts
}
```

Check out the
[Z80 Supervisor](https://github.com/transistorfet/computie/blob/main/hardware/Z80-NQC/Z80Supervisor/Z80Supervisor.ino)
code for more details

Next I added a check for the IOREQ signal, which would respond to specific IO port addresses.  When
writing to IO port 0xFF, it would either set or reset the arduino LED based on whether 0x00 was
written or not.  To test it, I made a simple Z80 program that used the `out` instruction to output 1
to the LED port, which confirmed that the IOREQ code was working and the Z80 was running.  Then I
added a check for port 0xF1, which would send the byte written by the CPU to the arduino's serial
monitor.  The following Z80 program could then be run to print a message to the serial monitor!

The first Z80 program, welcome.asm, which was compiled using SDCC's assembler
```nasm
    org 0000h         ; After a reset, the Z80 starts executing at 0x0000
    jp  start

start:
    ld   sp, 0200h    ; Set the stack pointer to an area above the program
    call _main
    halt

_main:
    ld  a, 01h
    out (00FFh), a    ; Output 1 to our arduino LED control port to turn it on

    ld  de, msg       ; Load the address of the message to print

loop:
    ld  a, (de)       ; Load the byte at message address
    cp  0             ; If it's a null character, jump to loop_end
    jp  Z, loop_end
    out (00F1h), a    ; Output the character to arduino serial
    inc de
    jp  loop

loop_end:

    ret               ; End of _main

msg:    defm    "Welcome To Bread80!\n\n\0"
```

[Z80 Monitor](https://github.com/transistorfet/computie/blob/main/hardware/Z80-NQC/Z80Monitor/)
for more Z80 code and build files

I was able to get some C code compiled and running using SDCC, but I was starting to get more
glitches, and timing issues.  The low speed of the CPU was also becoming a hindrance, but the
arduino was not able to assert the wait signal in time at higher CPU speeds.  The arduino is not
that much faster than the CPU, and the interrupt contains a lot of overhead before the wait signal
is asserted.  I considered using a flip flop to lock in the wait signal whenever a memory request
was initiated, which would be reset by the arduino when it had completed its checks, but that would
involve a bunch more wiring, which was already a bit flakey, and I was aiming for minimal external
hardware.

There were a lot of wires at this point and poor connections were becoming a problem again.  I tried
using a section of the breadboard as a patch panel to distribute the data and address signals, but
some of the breadboard pins got damaged after I inserted some of the wires at the wrong angle.  I
lost a lot of time trying to figure out why the program was not executing as expected, before I
realized it was caused by the damage to the breadboard.  The fact that all the wires were still
joined together in bundles of 8 or 12 also caused issues since they couldn't move relative to each
other, and the tension caused by this would pull out some of the wires, causing poor connections.

Add Simplicity
--------------

With the concept of intercepting the bus request proven, I set about making a much simpler
breadboard setup without memory chips.  By this point, I had homed in on the 68000 as the CPU to
push forward with.  It would have more processing power and addressable memory than most of the
8-bit CPUs, which would come in handy when I eventually tried writing an OS, and it required
significantly less external circuitry than the 8086/8088, since the address and data buses are not
multiplexed like they are on the 8086/8088.  The 68000 also has an asynchronous bus, which uses the
DTACK signal to indicate the end of the request, rather than a WAIT signal to delay the end of the
request.  This means I could avoid the need for a flip flop to lock in the wait state.

I started by wiring up a 68000 directly to the arduino pins, along with the necessary pull-up
resistors for the control signals.  A simple 74HC14-based crystal oscillator provides the clock
signal (on the mini green breadboard).  The 68000 needs a clock that is at least 4 MHz, or else the
dynamic registers used in the CPU will lose their values and cause the CPU to misbehave, but running
at such a fast speed wont be a problem here, because of the asynchronous bus.  I ended up running it
at 8 MHz without issue.  The actual execution speed was limited by the arduino's response time,
which was often more than 1 microsecond per instruction.  No other memory or interfacing chips are
needed for a minimal system, besides the arduino.

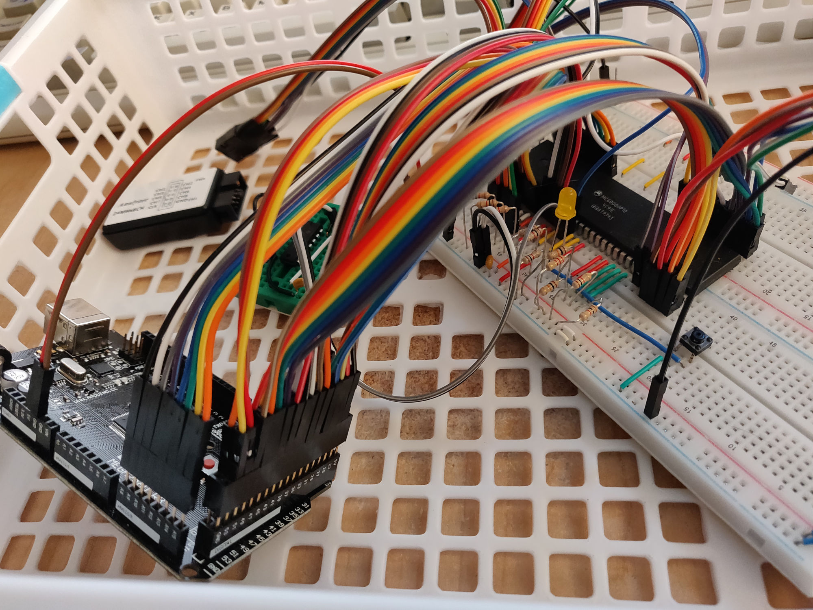
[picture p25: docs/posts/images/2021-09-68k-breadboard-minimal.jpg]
MC68000 Breadboard

Note the extra wire bundles and the generic logic analyzer in the upper left corner.  This turned
out to be very handy indeed.  I used Logic 1.2.18 from Saleae to capture various control and data
pins to debug various issues I came across.  I also purchased a new oscilloscope, which helped a
lot for a few tricky problems, especially with the later PCBs.

The 68000 starts a bit differently than the Z80.  I didn't realize this at first and had some
trouble trying to get it to run as expected until I read the manual closer.  At the start of memory
is an interrupt vector table from 0x000000 to 0x000400, with 256 entries of 4 bytes each.  Each 4
bytes specifies a 32-bit address which should be loaded into the program counter when the
corresponding interrupt occurs.  The exception to this is the first entry in the table which is the
address to be loaded into the stack register upon reset.  The second entry contains the program
counter on reset.  The 6 entries after contain the location of the error handlers for common program
errors such as "Illegal Instruction" and "Bus Error".  While testing on the breadboard and arduino
(with its limited memory), I only reserved space for the first 8 entries in the vector table, and
put the program in the remaining space, since those other interrupts would not occur during a simple
program.  This worked fine for testing.

This interrupt vector table is always located at address 0x000000 on the 68000, but on the 68010, it
can be changed after reset using the special `IVR` register.  I later switched to the 68010 when
developing the OS in order to use this feature.  

The first 68k program, welcome.s, compiled with GCC 9/10 for m68k.  Note the assembly syntax here is
quite different.  Register names are preceded with a `%` character and data is moved from the
left-hand location to the right-hand location, so `move.b #0x01, %d1` loads the D1 register with the
value 0x01.  The comments should also start with `|` but I changed them to `;` for the code
formatter here.
```asm
    .org    0x0000          ; After reset, the 68k expects the interrupt vector table here

    .word   0x0000          ; stack pointer value loaded on reset
    .word   0x1000
    .word   0x0000          ; PC value loaded on reset
    .word   0x0020

    .org    0x0020          ; Reserve space for the first 8 interrupt vectors
_start:

    move.b  #0x01, %d1
    lea     0x20ff, %a1     ; Load the address of the LED register
    move.b  %d1, (%a1)      ; Write 0x01 to turn the LED on

    lea     message, %a1    ; Load the message address
    lea     0x20f1, %a2     ; Load the address of serial output register

loop:
    move.b  (%a1)+, %d2     ; Load the next character and increment the pointer
    move.b  %d2, (%a2)      ; Write the character to serial

    cmpi.b  #0x00, %d2      ; Loop until the null character is found
    bne     loop

    stop    #0x2700         ; Halt the CPU

message: .ascii "Welcome to Bread68k!\n\n\0"
```
The 68000 uses memory-mapped IO so the arduino program recognizes the addresses 0x2000 - 0x20FF as
IO registers.  The 0x20FF register is used for the LED, and the 0x20F1 register for serial bytes.

[68k Supervisor](https://github.com/transistorfet/computie/blob/main/software/arduino/68kSupervisor/68kSupervisor.ino)
is the arduino code.  It's a bit messy since it has involved a lot of trial and error while
debugging problems, and changes as I've experimented with different chips.  The code is now only
really used to load an initial program into the onboard Flash chips of the newer 68k-SBC and 68k-SMT
boards.

When the Supervisor first runs, it will start in "device" mode (as if it were a device connected to
the CPU's bus), and allow the CPU to run freely.  While the CPU is running, any input to the serial
monitor will be made available if the CPU reads the memory-mapped IO address for serial bytes.  To
escape out of the input-capture mode, a single backtick "&#x60;" character followed by enter can be
typed, which will cause the arduino to request the CPU bus through the bus arbitration signals, and
enter "controller" mode.  In controller mode, the CPU will be suspended, and in the serial monitor a
prompt will be displayed which responds to some simple commands, such as `run` to start the cpu and
`reset` to reset it.  The memory chip tests can be run from the command prompt as well.  I've mostly
hand-changed the address and size values used by the memory tests as needed rather than allowing
them to be specified in the command.

Adding Serial via MC68681
-------------------------

The ultimate goal was a standalone computer on a custom PCB, so I needed an IO device that wasn't
the arduino.  The obvious choice was the MC68681 chip, which is designed to interface easily to the
68000, and which is still widely available.  It has 2 serial ports, 6 general purpose input pins,
and 8 general purpose output pins.  Some of these GPIO pins are needed for the serial port CTS and
DTR flow control signals (which turned out to be crucially important for sending large amounts of
data over the serial ports), but some could be used for debugging as well.  Before getting a circuit
board printed, I wanted to make sure all the parts of the complete design would work as expected.  

I assembled a circuit on a separate breadboard, and wired it to the data and address buses.  I also
added an inverter to address line A14 which would go low whenever an address in the 0x4000 range was
accessed, which I could use as the chip select signal for the MC68681.  The serial port pins were
wired to an FTDI module (the small red circuit board in the images) with ground pin connected to the
system ground, and the power pin unconnected.  The CPU and MC68681 were powered by the Arduino Mega,
which was powered through its USB port.

<div align="center">
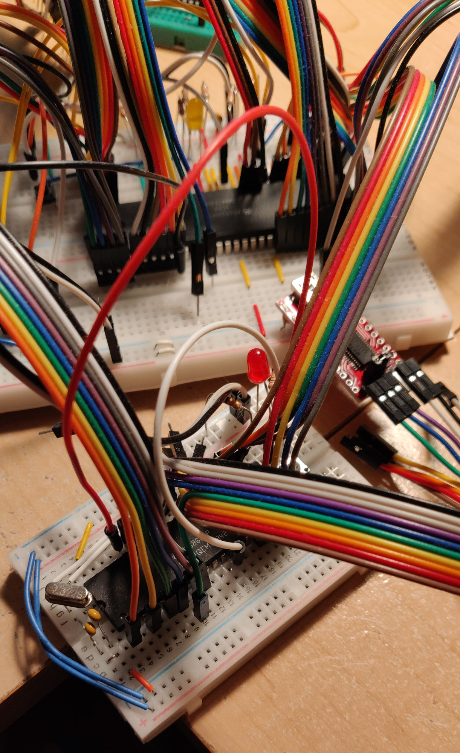
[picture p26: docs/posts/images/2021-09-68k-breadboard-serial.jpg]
MC68681 Serial

</div>
The MC68681 on a half-sized breadboard, with an FTDI Serial-to-USB adapter (the red circuit board)
wired to the serial pins.  The red LED and a push button are wired to GPIO pins for debugging.

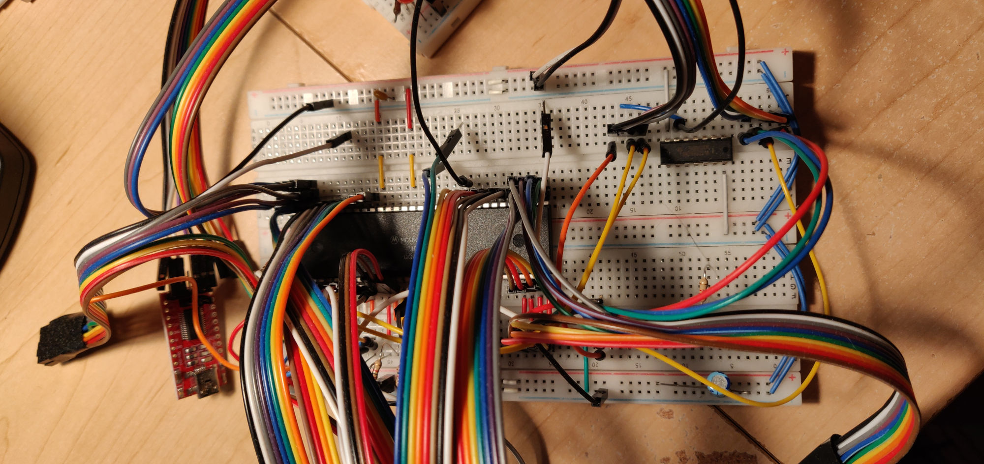
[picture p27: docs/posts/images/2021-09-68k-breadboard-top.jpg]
MC68000 with Serial

The main breadboard at this point, with the serial board just out of frame.  The logic chip on the
right is a 74HC14 hex inverter used for decoding the address for the MC68681.

By this point, I had a simple C program that would run on the breadboarded 68k, and use the MC68681
to output text via the FTDI module to a serial terminal program, which was running on my desktop.
The code for the monitor at this point in time can be seen
[here](https://github.com/transistorfet/computie/tree/37a3d22eb2dc59042ab9b4293cf30fd41935a81a/68k-SBC/68kMonitor/src).
I was already starting to implementing some of the standard C library functions for formatting
numbers and strings, so that I could easily print out debug information to the serial terminal

The First PCB
-------------

While experimenting with the 68k on a breadboard, I started working on the PCB design in KiCad for a
system that could run without the arduino, 68k-SBC Rev.0.  (Note: I started with revision numbers
from 0 but later decided I should start from 1 instead, so I skipped Rev.1, and the second version
after this board is named Rev.2).  The board has the MC68681 with headers for FTDI modules, since I
didn't plan on using actual RS-232 connectors with it.  It has 2 x 512KB static RAM chips for the
upper and lower byte, mapped to address 0x100000, as well as 2 x 32KB EEPROMs, mapped to address
0x000000.  There are also 2 x 40 pin headers for all the address, data, and control signals, so that
I could hook up the arduino to it.  To make this easier with so many wires, I also designed an
arduino shield with matching 2 x 40 pin headers wired to the appropriate arduino pins so that I
could use ribbon cables to connect them instead of individual wires.  That said, I didn't actually
use the ribbon cables until Rev.2 so that I could access the unwired control pins for further
testing and expansion.

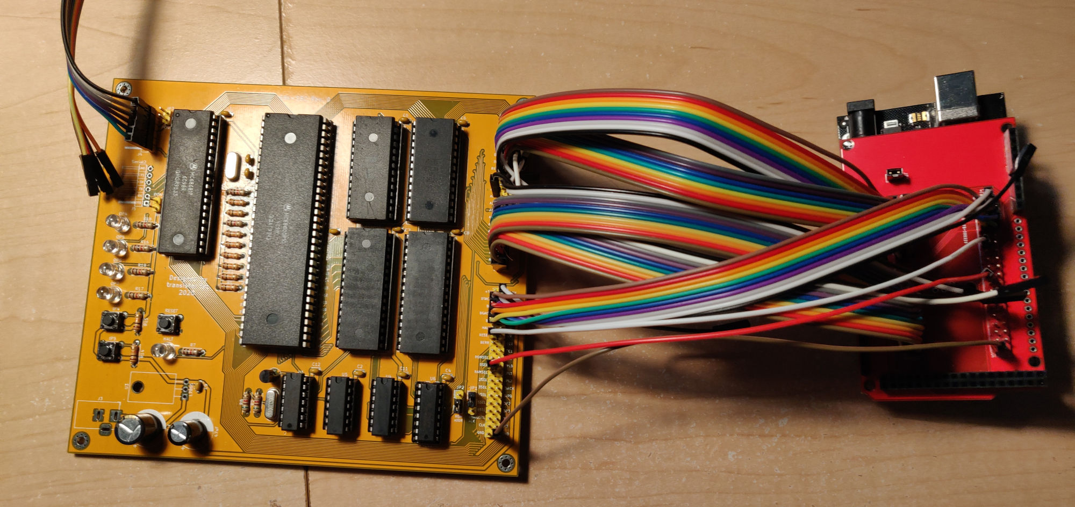
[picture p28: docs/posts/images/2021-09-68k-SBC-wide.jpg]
68k-SBC Board


This board also has two jumpers in the lower right corner.  One will enable or disable the onboard
DTACK generation.  With it disabled, the ardunio can provide the DTACK instead, giving it a chance
to print each memory request, even if the CPU is reading data from a memory chip.  The other jumper
will move the address of the EEPROM from 0x000000 to 0x200000.  This allows the arudino to respond
to addresses in the 0x000000 range, which is where the boot vector table is, allowing it to boot the
CPU without the EEPROMs.  The EEPROMs can also be programmed while in the 0x200000 address range.

There were various issues with this board and it wasn't long before I moved on to the next revision,
but I'll save that for another post.

End of the Beginning
--------------------

It's been such a fun and rewarding experience playing around with old CPUs again.  Using an arduino
to bootstrap the process made it a lot easier to experiment and test things out quickly.  From the
time I started playing around with memory chips in October of 2019, and working a full time job, I
had a working single board standalone computer by the end of March 2020.  From there, I started
writing a proper operating system and made a few upgraded versions of the same system.  While I've
been spending time on other projects lately, I plan to eventually push further with MC68030s and
perhaps more.  I hope this inspires others to give it a try and get started in their own experiments
with these wonderful classic CPUs.

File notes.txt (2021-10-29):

Compiling:

make clean && make all && make commands

Open a terminal:

pyserial-miniterm /dev/ttyUSB0 38400

Load the kernel across serial:

python3 tools/load.py kernel.load

Send a command:

python3 tools/load.py -l src/commands/daemontest.send
(the -l optionally limits the speed, but flow control works, so it shouldn't be necessary anymore)

Enable SLIP on linux:

sudo slattach -s 38400 -p slip /dev/ttyUSB1
sudo ifconfig sl0 192.168.1.2 pointopoint 192.168.1.200 up
// (this is automatically added on my machine) >> sudo route add -host 192.168.1.200 sl0
sudo arp -Ds 192.168.1.200 enp3s0 pub
sudo iptables -A FORWARD -i sl0 -j ACCEPT
sudo iptables -A FORWARD -o sl0 -j ACCEPT
sudo sh -c "echo 1 > /proc/sys/net/ipv4/ip_forward"

From the Monitor:

To Boot from flash/ata0:
boot 20000

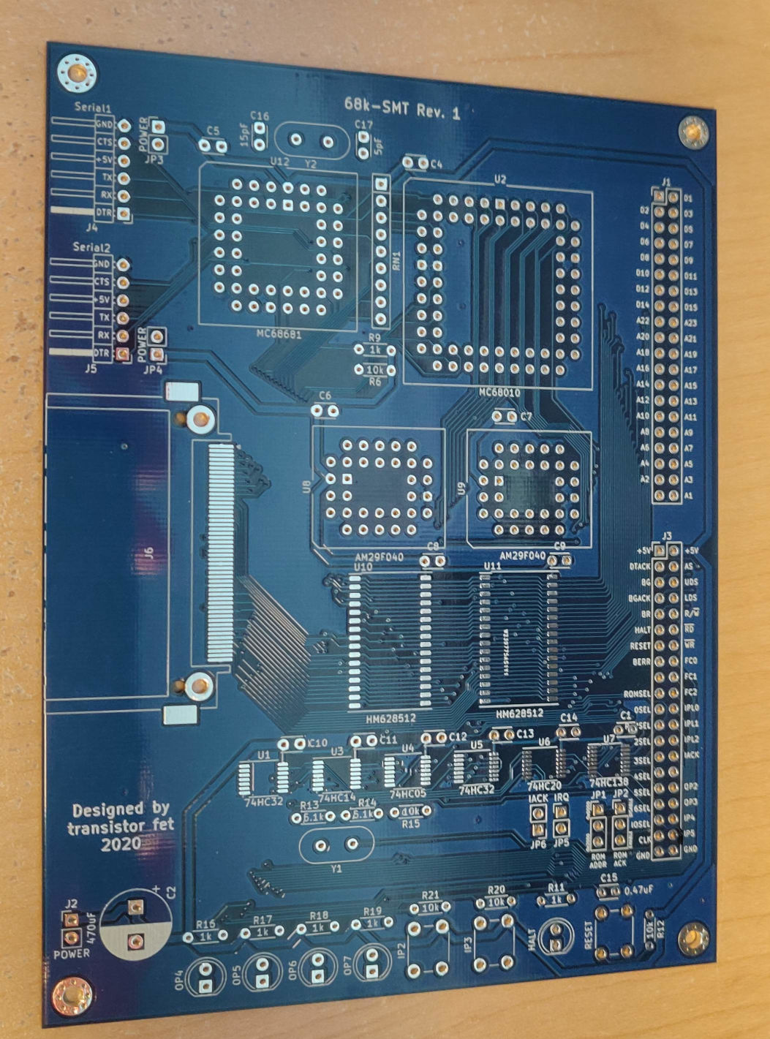
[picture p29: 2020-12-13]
images/68k-SMT-rev1/PCB-top.jpg

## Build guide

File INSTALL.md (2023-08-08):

Building and Bootstrapping A Computie Board
===========================================

If you ever build one of these boards, please drop me a line and maybe send me some pictures (links
on [jabberwocky.ca](https://jabberwocky.ca/).  I'd love to hear about how it goes, or what you've
manage to do with it.

Building the Boards
-------------------

The gerber files for each revision are in the hardware directory for each board under `revisions/`,
along with an Errata file that might be useful to read.  Only 68k-SBC Rev.2, 68k-SMT Rev.1, and
k30-SBC Rev.2 should be built.  The earlier revisions have known issues that make the boards
unusable.

Initializing A 68k-* Board
--------------------------

For the boards with removable flash chips, they can be programmed externally using a generic chip
programmer, but I usually use an Arduino Mega with the 68k Supervisor shield, and ribbon cables to
connect it to the board.  Using the 68k Supervisor sketch in `software/arduino/68kSupervisor`, and
compiling the monitor.bin target, the monitor can be written to the flash chips in-circuit.

It's also possible to use the supervisor to host the monitor directly, with the arduino intercepting
bus cycles, but that requires the clock speed to be 10MHz or lower, or else it won't have time to
stop the cycle and booting will fail.  The jumpers on the board also need to be set, so that the
flash memory is mapped into the region at `0x200000` instead of `0x000000`, and the DTACK needs to
be disabled so that the arduino can provided in when it eventually catches up.  Using the arduino
hosting is much slower than the flash, but can help diagnose problems.

To compile the monitor:
```sh
cd software/
make monitor.bin
```

This will create both a monitor.bin, and output.txt, which is a C-compatible copy of the binary that
is included by the Supervisor sketch.  Whatever code is in output.txt will be hosted at address 0,
or will be written to flash.

From the arduino serial monitor, to erase the flash, write the monitor image, and verify the
resulting memory, run the following commands:
```sh
erase
send
verify
```

Initializing A k30-SBC
----------------------

The k30 requires a modified Arduino shield with the A0, DS, and DSACK1 signals added to additional
Arduino I/O pins.  Only the lower 8-bits of the data bus are used, so the extended header on the
board can be left unconnected.  I will eventually make a new version of the shield PCB.  It also
requires the k30FlashWriter sketch instead, which can write the flash chip in memory, but does not
have the ability to debug or host anymore.  That feature doesn't work at 12MHz and the 68030
technically should have a >12.5MHz clock, according to the specs, so I removed it.

The process is otherwise the same as for the 68k-* boards

Connecting to the Monitor
-------------------------

To connect to the monitor, attach a TTL-level serial converter to the first serial port header and
connect with any serial terminal program.  I use a 5V FTDI-in-cable serial-to-USB adapter, which is
similar to [this one](https://www.sparkfun.com/products/9718), and I use `miniterm` on my desktop,
which is provided by the `python3-serial` package.

```sh
pyserial-miniterm /dev/ttyUSB0 38400
```

If it works, you should see it print the welcome message, and the prompt, after pressing the reset
button.  The prompt will appear every time you press enter in the terminal.
```
Welcome to the 68k Monitor!

>
```

Loading Over Serial
-------------------

Once the board has been initialized and can boot the monitor from flash, it's possible to send
programs over the serial port.  The binaries can be compiled using the `.load` extension as the
target, which will generate a text file that contains the load command, the length of data, and the
data encoded as hexadecimal in ASCII.  It can be sent over serial with the python script in
`tools/`, while the terminal is open.  This allows you to see the command start.  The data itself
will not be echoed back to the terminal so it will appear to hang until the file has been
transferred.

On the desktop:
```sh
make monitor.load
python3 tools/load.py monitor.load
```

There is an option to `load.py` to limit the speed of transfer using `-l`, which is necessary if the
CTS/DTR signals are not working properly.

Once the file is complete, the load script will usually include a boot command that will
automatically jump to the location where the file was loaded.  You can check if the monitor is
running in RAM at `0x100000` (the default load location) or Flash memory at `0x000000` by using the
`info` command to see where the PC is pointing to.

Updating the Monitor
--------------------

It's possible to update the monitor in memory, by loading a new copy of the monitor over serial into
RAM and running it.  If the monitor is running in RAM, it's (semi)-safe to erase the flash, and
write the copy of the monitor in RAM into Flash.  This can render the board unbootable, but the
Supervisor or external flash writer can be used to fix that.

To erase the monitor in Flash and write a new copy, in the monitor running in RAM run the following:
```sh
eraserom
writerom
verifyrom
```

Running the Kernel
------------------

To compile the kernel, run:
```sh
make kernel.load
```

It can be sent over serial like the monitor.  You might want to modify the kernel configuration in
`gloworm/src/kernel/main.c` if you're using a board without the CompactFlash card, or you don't want
to use networking.

Building A FlashCard Root Image
-------------------------------

The image can be built using a loopback device and following make commands:
```sh
make create-image
make mount-image
make build-system
make umount-image
```
Which will produce a 20MB disk image in `minix-build.img` using the `build/` directory as the
mountpoint, and the minix1 filesystem.  It does not include a partition table, so that needs to be
created on the flash drive by other means.  It can be written to the partition-specific block device
file using `dd` on a unix-like desktop.

In order to boot off the CompactFlash directly, the `boot.load` script can be loaded over serial and
written to an alternate location such as `0x020000`.  It must be a location that is outside of the
Flash chip's sector in which monitor is written, or else the system will be unbootable.  The
boot.bin image doesn't contain a vector table like the monitor.bin image does.

After sending the `boot.load` file over serial, without running it, in the monitor, run the
following:
```sh
eraserom 20000
writerom 20000
verifyrom 20000
```

You can then boot from the monitor at any time by running:
```sh
boot 20000
```

The bootloader will print a period character for every 1K of the kernel image loaded from the disk
into RAM, and then it will run the kernel after.  If it works, you should see the heartbeat LED
flashing to indicate the kernel is running and multiprocessing is enabled and switching.

Configuring Networking
----------------------

If the second serial port is connected to a desktop, it will act like a SLIP connection, which can
be bridged to the desktop's network, where `/dev/ttyUSB1` is the serial device connected to the
second serial port of the board, and `192.168.1.x` is the local network, and enp3s0 is the
internet-connected network interface on the linux desktop:

```sh
sudo slattach -s 38400 -p slip /dev/ttyUSB1
sudo ifconfig sl0 192.168.1.2 pointopoint 192.168.1.200 up
# (this is automatically added on my machine, but might be required) sudo route add -host 192.168.1.200 sl0
sudo arp -Ds 192.168.1.200 enp3s0 pub
sudo iptables -A FORWARD -i sl0 -j ACCEPT
sudo iptables -A FORWARD -o sl0 -j ACCEPT
sudo sh -c "echo 1 > /proc/sys/net/ipv4/ip_forward"
```

The device will have IP `192.168.1.200` which also needs to be configured in the kernel's
`gloworm/src/kernel/main.c` function at the bottom.

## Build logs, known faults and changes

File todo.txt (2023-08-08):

Post:
	* I need to elaborate on how I did things, what broke, how I fixed it...  It's a bit too much a list of what I did rather than something helpful

Monitor:

	* failure vectors don't point to the correct addresses, from the looks of it

	* can you have an debugger in the monitor software?  There are trap and breakpoint instructions in the processor for debugging, so if you define an interrupt handler
	  for those, you could have it enter a debugger, that possibly allows single stepping?  I'm not sure how to implement that

k30-SBC:
	* you could use the extra 2-4 decoder for onboard I/O within IOSEL (ie. MC68681 would remain the same, ATA I/O would be moved to 0x700100, and two more devices could be added
	* is 16 clocks enough for the BERR?  It should be 480us which should be enough
	* look into the CIIN signals and stuff

68k Single Board Computer:

	* can you add a video/lcd expansion via the expansion connector?  Maybe you could get ends to directly connect it?  Would it be via parallel interface?
	  would you need a PIT 68230 to interface?  How complex are the interfaces of those graphic ones?
	* can you connect an esp01 as a wifi device?  I suppose you could connect it to the other serial port, even though it would be slow

68k Arduino Shield:
	(nothing atm)

68k SMT:
	(nothing atm)

* should you move the Z80 project into it's own repo?

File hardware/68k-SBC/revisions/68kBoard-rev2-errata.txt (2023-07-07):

Revision 2 Errata and Notes
===========================

- it would have been handy if there were some power pins to hook the oscilloscope to

- there is some kind of issue with booting, where it requests addresses, 0, 4, 0, and 4, rather than 0, 2, 4, 6.  After
  investigating, it appears to be an issue with the arduino only.  Once the flash memory was programmed and booted, it
  worked perfectly.  As for the arduino, it appears to be an issue with dtack (which I recall being the reason I previously
  saw these symptoms, but it was a different cause).  It seemed to be the inserted NOPs between the dtack assertion and
  unassertion were causing it to be too slow, but removing them, while resulting in a proper initial startup, still doesn't
  boot correctly.  For the moment, I suspect it's the increased speed from 10MHz to 12MHz of the CPU which is making it too
  fast for the arduino. 

- 2023-07: This applies to most versions of Computie: If a ribbon cable is attached to the control
  signals header, it will cause the CPU to not work correctly due to issues with DSACK0/1.  A
  larger pull up resistor on those signals should fix the problem (1K was tested)

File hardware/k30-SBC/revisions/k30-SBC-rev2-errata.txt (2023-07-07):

Revision 2 Errata and Notes
===========================

- I forgot to add the part name silkscreen for the 74LVC1G32 that was added to rev. 2

- 2023-07: This applies to most versions of Computie: If a ribbon cable is attached to the control
  signals header, it will cause the CPU to not work correctly due to issues with DSACK0/1.  A
  larger pull up resistor on those signals should fix the problem (1K was tested)

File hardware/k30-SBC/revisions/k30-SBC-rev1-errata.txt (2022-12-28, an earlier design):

Revision 1 Errata and Notes
===========================

- the footprint for the 74HC253s is too small.  I used the 16SSOP - 4.9mm wide, but the chips are
  actually 6.2mm wide.  I've tried to bend the pins under to solder them instead

- the HALT light should really be labelled RUN, since it's really ~HALT (ie. running)

- the ATA DSACK output needs to be inverted.  The input into the NAND gate should be active-low,
  but the output from the counter is going straight into the NAND input.  I'm going to try
  patching it

- (I think) the reset pin of the CompactFlash socket should be connected to the reset button, to
  ensure the card is reset.  Soft resetting seems unreliable

- there was an issues with the 74HC08 chip's AND gate that combines the address decode lines to
  produce the RAMSEL signal, and the fact that those two traces go underneath the chip is causing
  a lot of problems for debugging.  Never route traces to pins underneath a surface mount chip!
  It turned out the traces were broken just before they entered the pads from underneath the chip.
  I was not able to patch it and instead bypassed the AND gate with a bodge wire from the trace
  from HC138 pin 14 (SEL1) to RAMSEL, which means only 1MB of RAM is accessible

- the extra DTACK input into the NAND gate should be pulled high to disable it, or else it could
  trigger DTACK erroneously

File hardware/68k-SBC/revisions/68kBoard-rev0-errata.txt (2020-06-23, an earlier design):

Revision 0 Errata and Notes
===========================

- the silk screen for the MOSFET is backwards (likely the symbol on the schematic has the wrong pinout)
 
- The pullup resistor for DTACK (R11) at 10k Ohms was too high, resulting in an idle voltage on DTACK that is too low.  This caused the
  CPU to read from incorrect addresses and stop after 6 cycles.  The breadboard version had a 1k Ohm pullup, but the design called for
  10k for all pullups.  It seems like ~5k is recommended for TTL circuits, but to play it safer, I installed a 2.2k, which worked, but
  later switched to a 1k.  I tried a 4.7k resistor after debugging an issue with the serial chip, and that didn't work so well, as it
  turned out.  Perhaps a better MOSFET would interfer less.

- I should have labeled all chips with their pinouts to aid in debugging.  I also should have added labels to the arduino shield

- the UDS and LDS lines were not included in the memory logic, which is fine for reads, but causes problems when writing one
  byte at a time (causing the other byte in the memory word to be replaced).  This is a very critical problem.  Fixing it would
  require another 4 OR gates to compare the LDS/UDS lines with the chip selects or write lines for each of the 4 memory chips.
  After posting in EEVBlog forums, a temporary fix would be to use a P-channel mosfet for each memory chip, or a 74LVC1G32 or
  74LVC2G32 to fix the issue.  These could be permanent solutions as well, which would require less reworking of the PCB design
  but at the expense of requiring more parts to build

- it would have been better if the arduino could address all memory, so that it could directly write to rom and ram while the
  cpu is suspended

- if using shrouded headers for the expansions, then the silk screen would be covered by the shroud.  There's not much space where the
  jumpers are though, to move them over.  This problem of not enough space also applies to the cpu itself

- the arduino shield needs access to the expansion pins not wired to arduino ports, so that they can be debugged or wired up through
  jumpers.  It would also be handy to have a way of connecting and disconnecting the 0SEL pin to the arduino to test the rom, which
  I've been doing manually with individual wires on the signals header

- the power capacitor spacing is a lot more than needed, especially for the 5V side cap

- It might be convenient to have a write protect jumper for the eeprom to disable the write pin, because I think the program sometimes
  writes to the arduino memory and corrupts it which requires a reset of the arduino (needs more investigation)

- the address silk screen labels for the CPU are wrong.  They all say D5

Observations:

- with external interrupt logic, it doesn't seem to really need to the "NOT AS (ADDRESS SELECT)" signal to be included with the
  three FCx signals to produce an acknowledge signal.  Adding it in will shorten the pulse by a bit, but the timing diagram for the
  duart chip shows the irq and irqack signals going low almost at the same time, so it probably shouldn't make a difference

- when running off the memory (no arduino), it's possible to remove the counter chip and wire power directly to the mosfet that pulls
  dtack low, and have it run correctly.  This seems weird in that the serial chip is also working with an always low dtack, but it might
  be that the duart chip has a response time lower than the cpu, same as the memory.  The arduino definitely can't work in these
  conditions but it should be possible to rework the logic a bit to use the same address conditions to activate the mosfet, so that dtack
  is only pulled low when the memory is addressed.  This would allow us to get rid of yet another chip.

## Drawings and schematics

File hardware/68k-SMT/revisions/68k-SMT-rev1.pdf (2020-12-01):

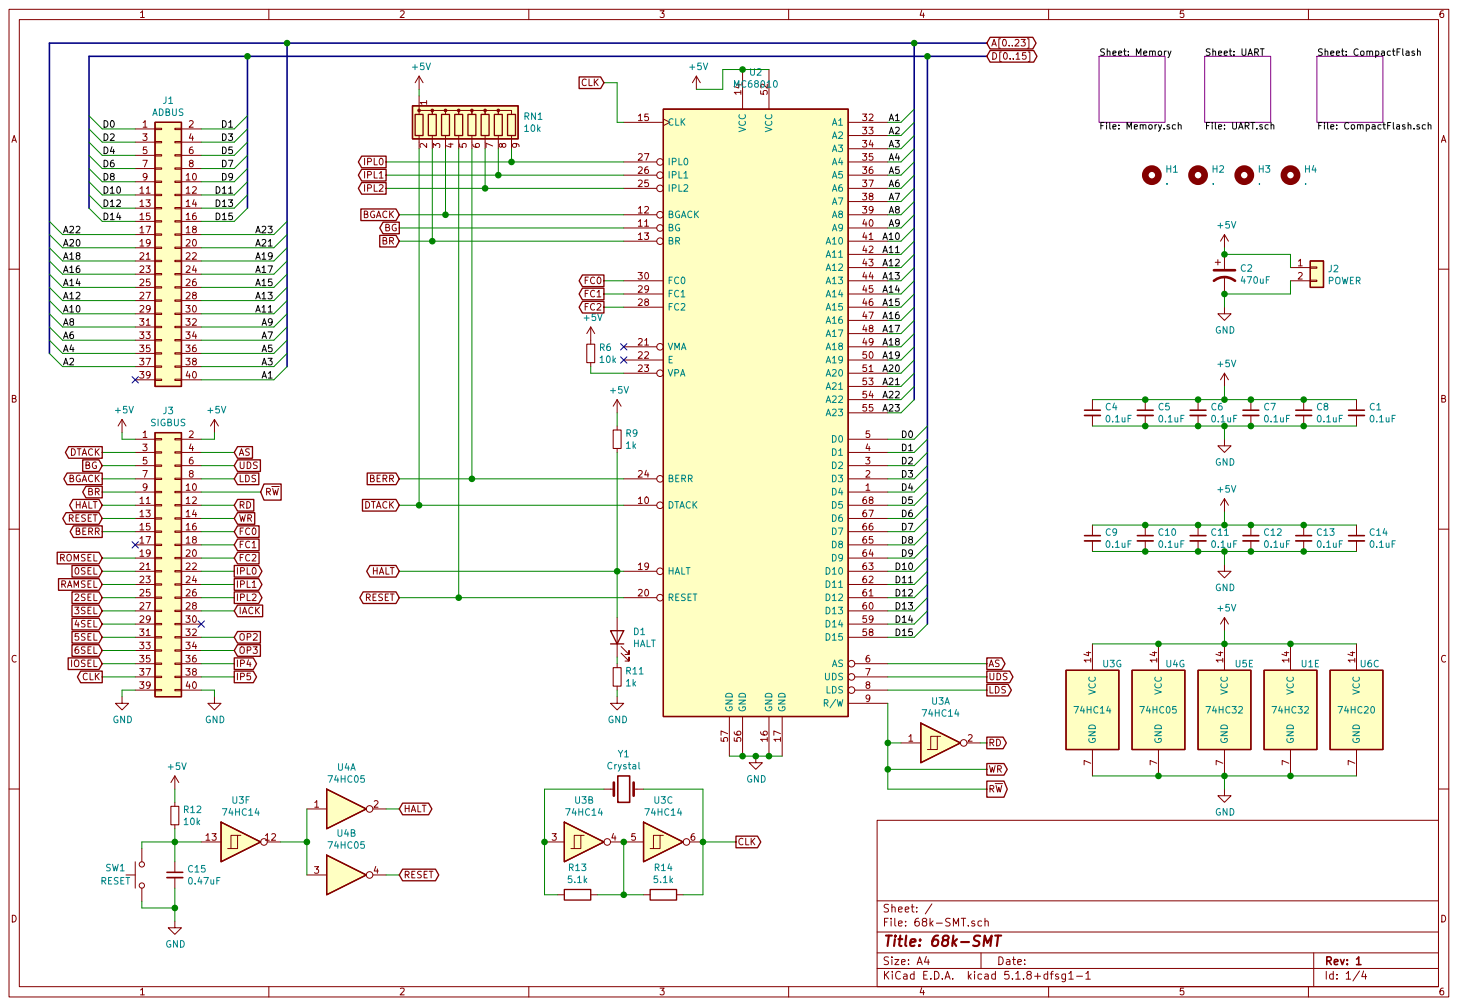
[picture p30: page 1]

File: UART.sch Sheet: Memory

File: CompactFlash.sch Sheet: UART

File: 68k-SMT.sch Sheet: /
Id: 1/4 Title: 68k-SMT

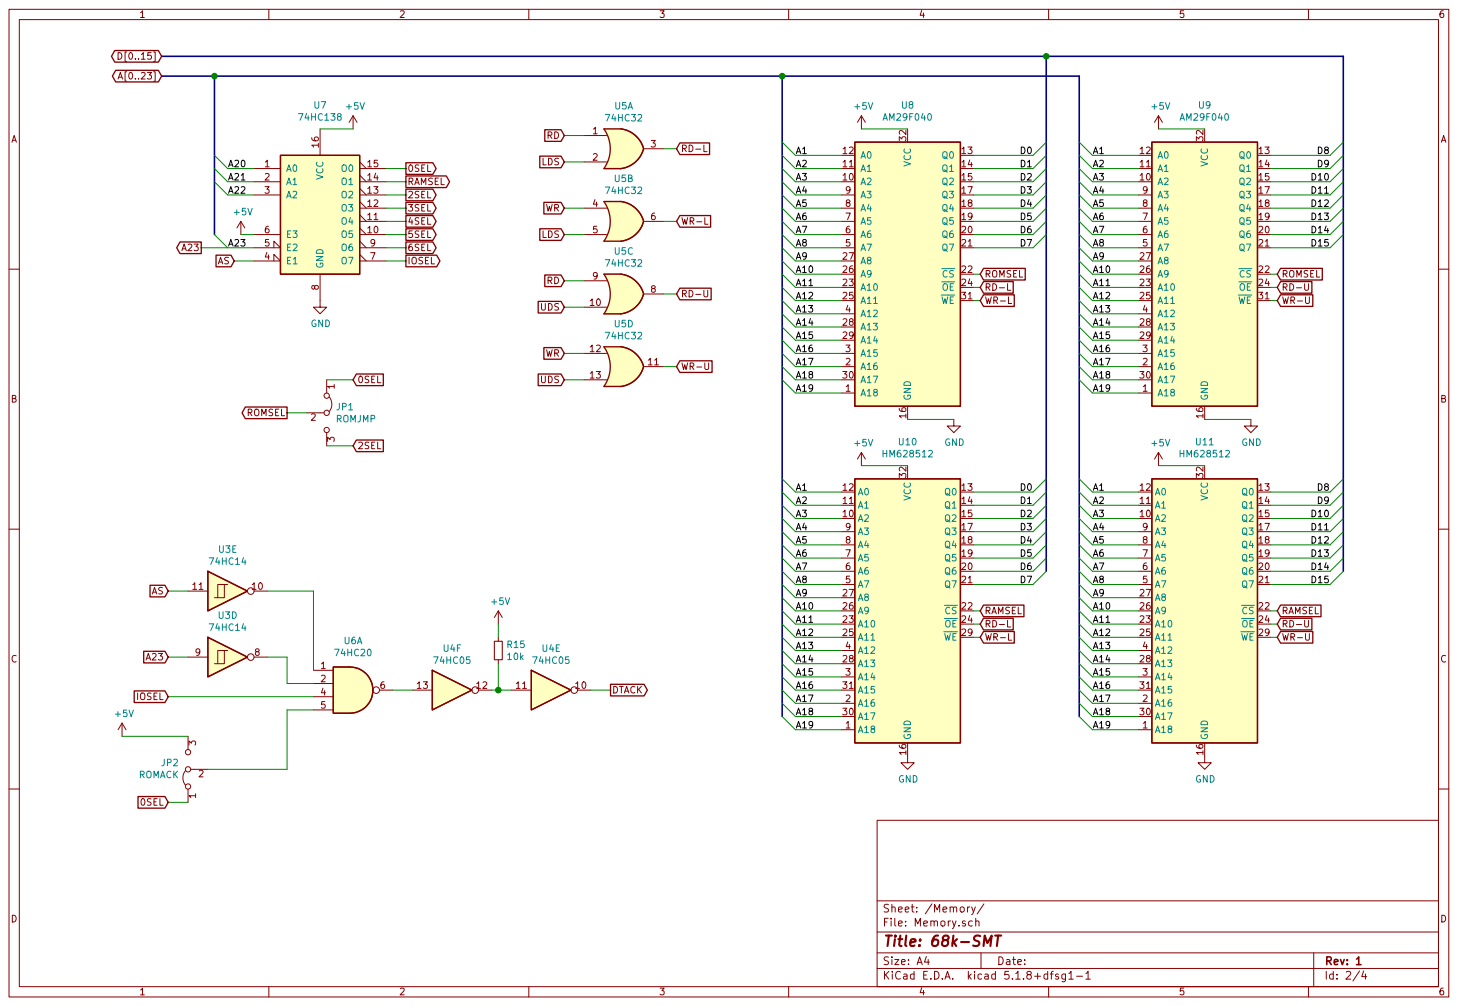
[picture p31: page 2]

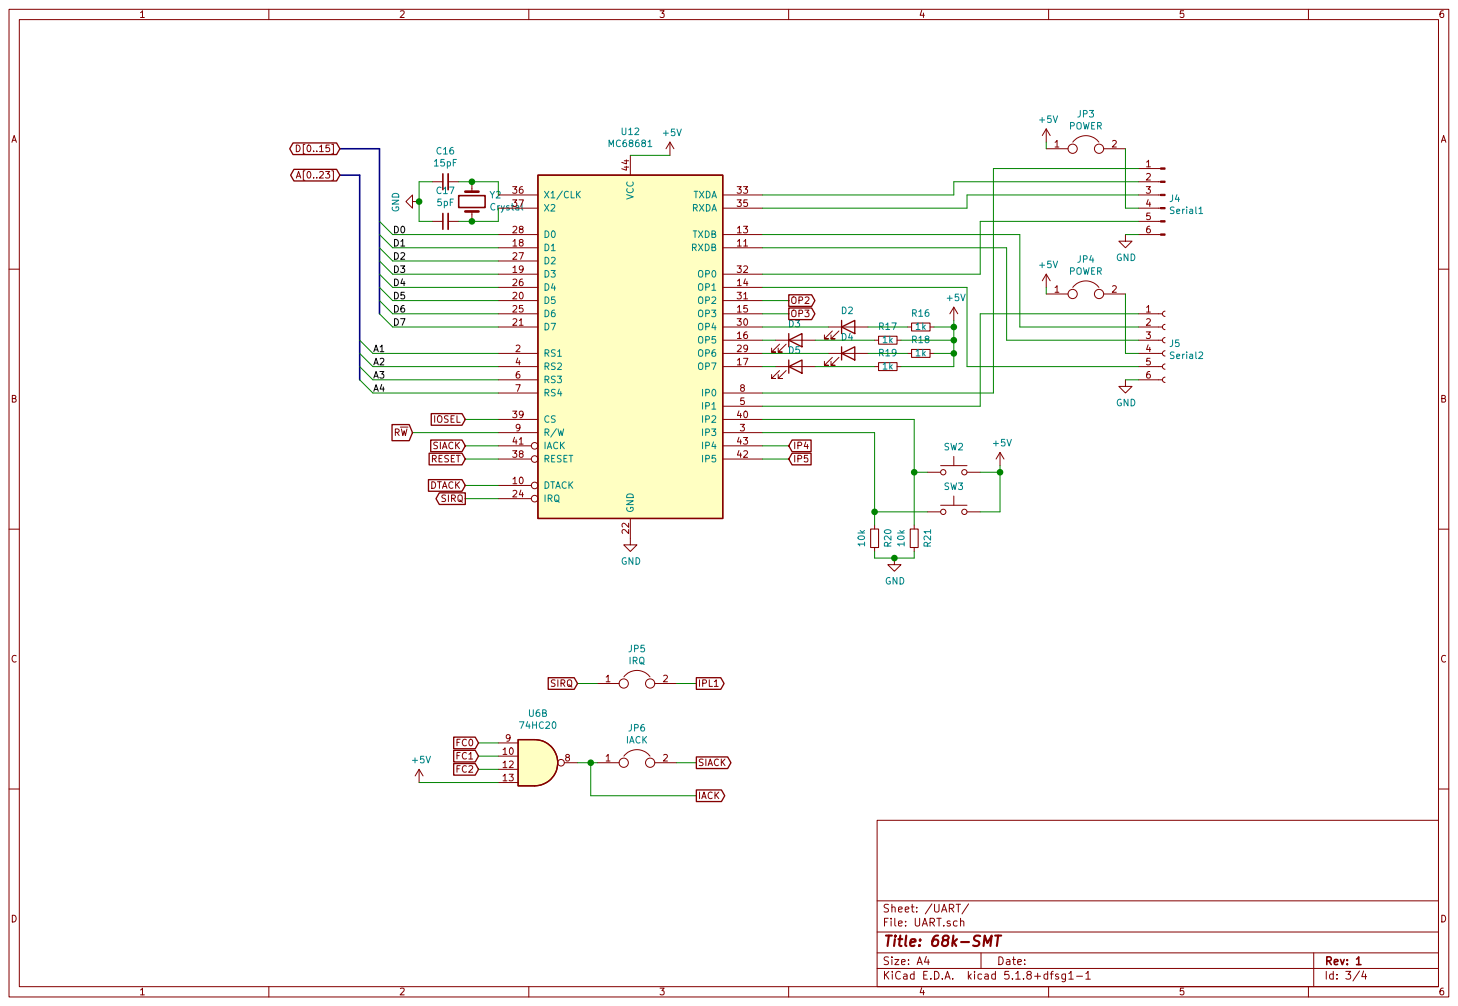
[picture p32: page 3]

File: UART.sch Sheet: /UART/
Id: 3/4 Title: 68k-SMT

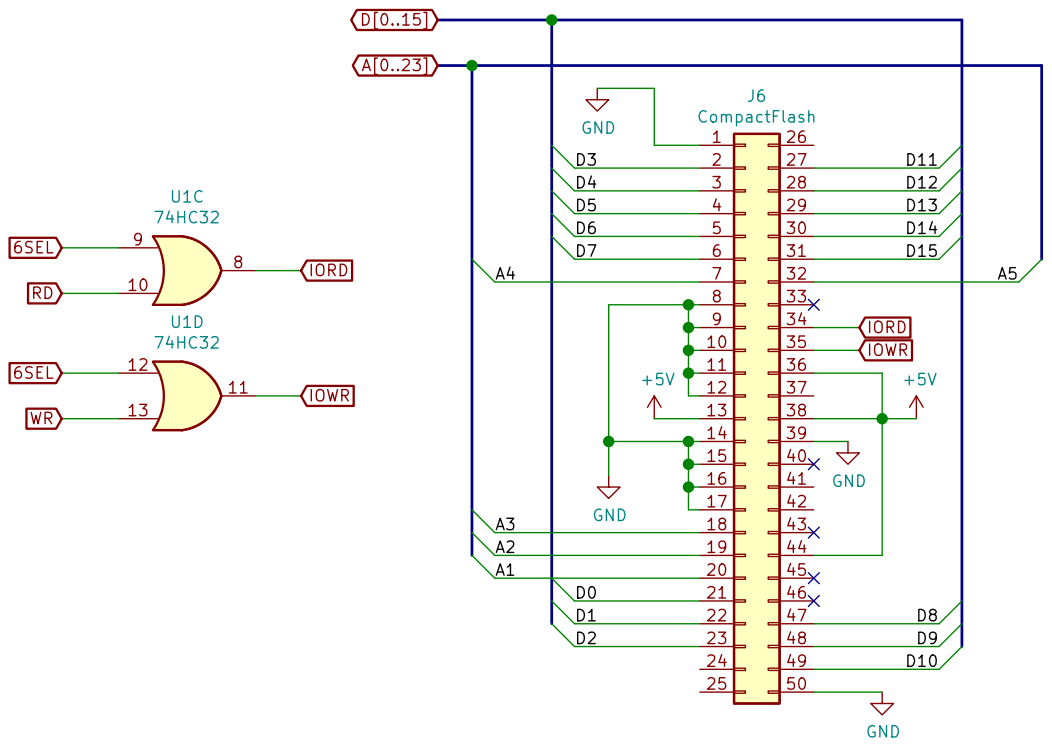
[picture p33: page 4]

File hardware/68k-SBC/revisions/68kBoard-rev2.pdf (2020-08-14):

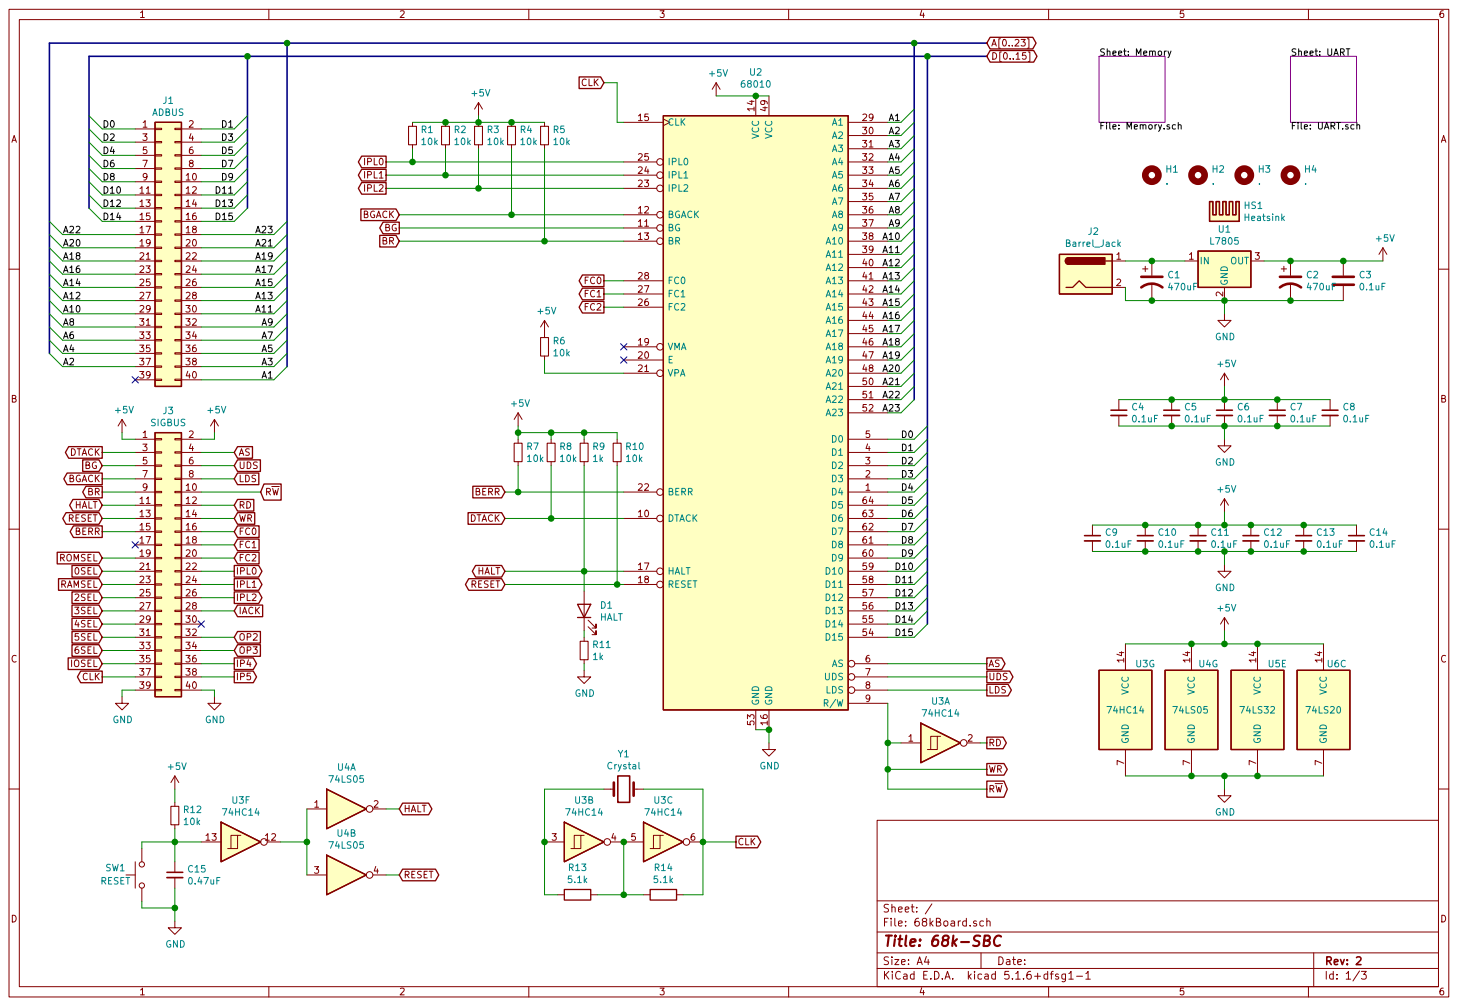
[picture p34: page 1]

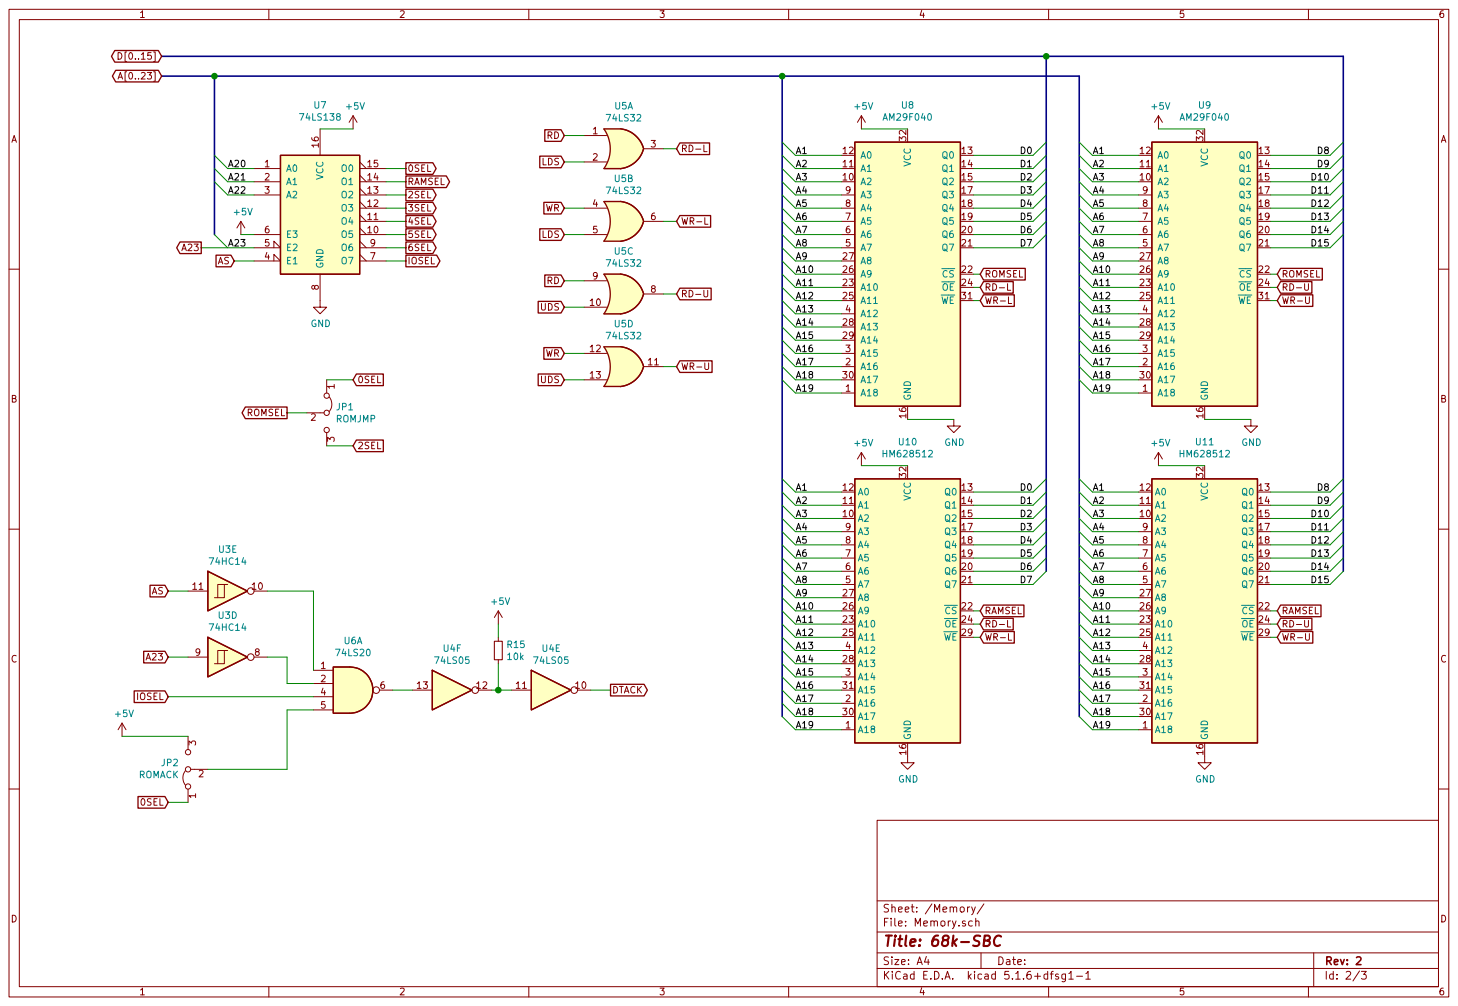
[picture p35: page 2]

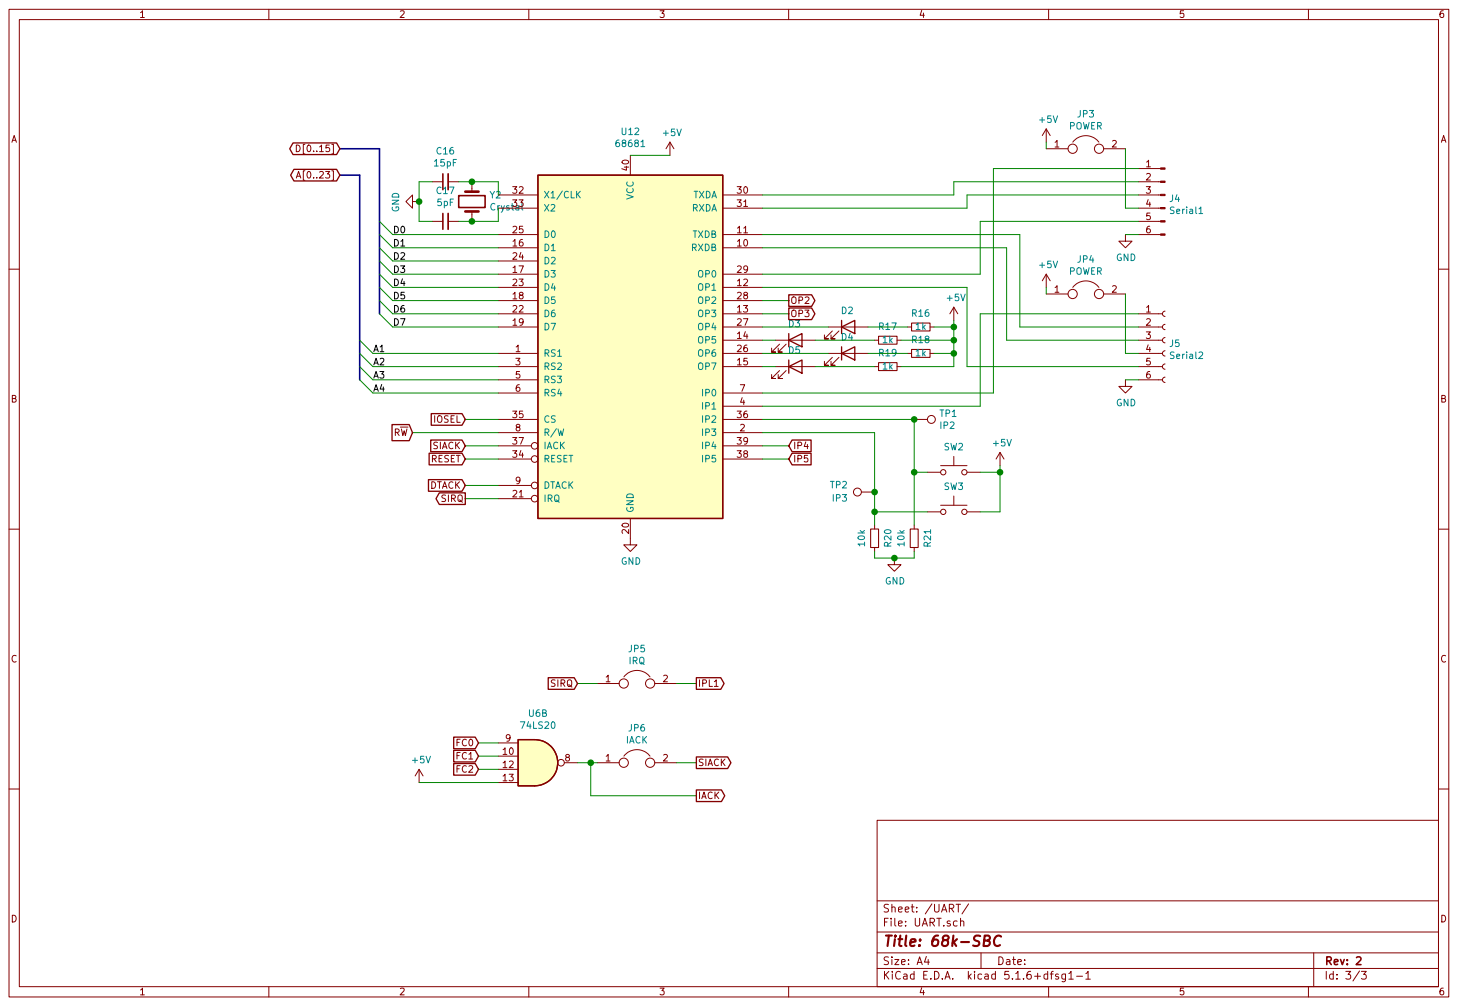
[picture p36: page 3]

File: UART.sch Sheet: /UART/
Id: 3/3 Title: 68k-SBC

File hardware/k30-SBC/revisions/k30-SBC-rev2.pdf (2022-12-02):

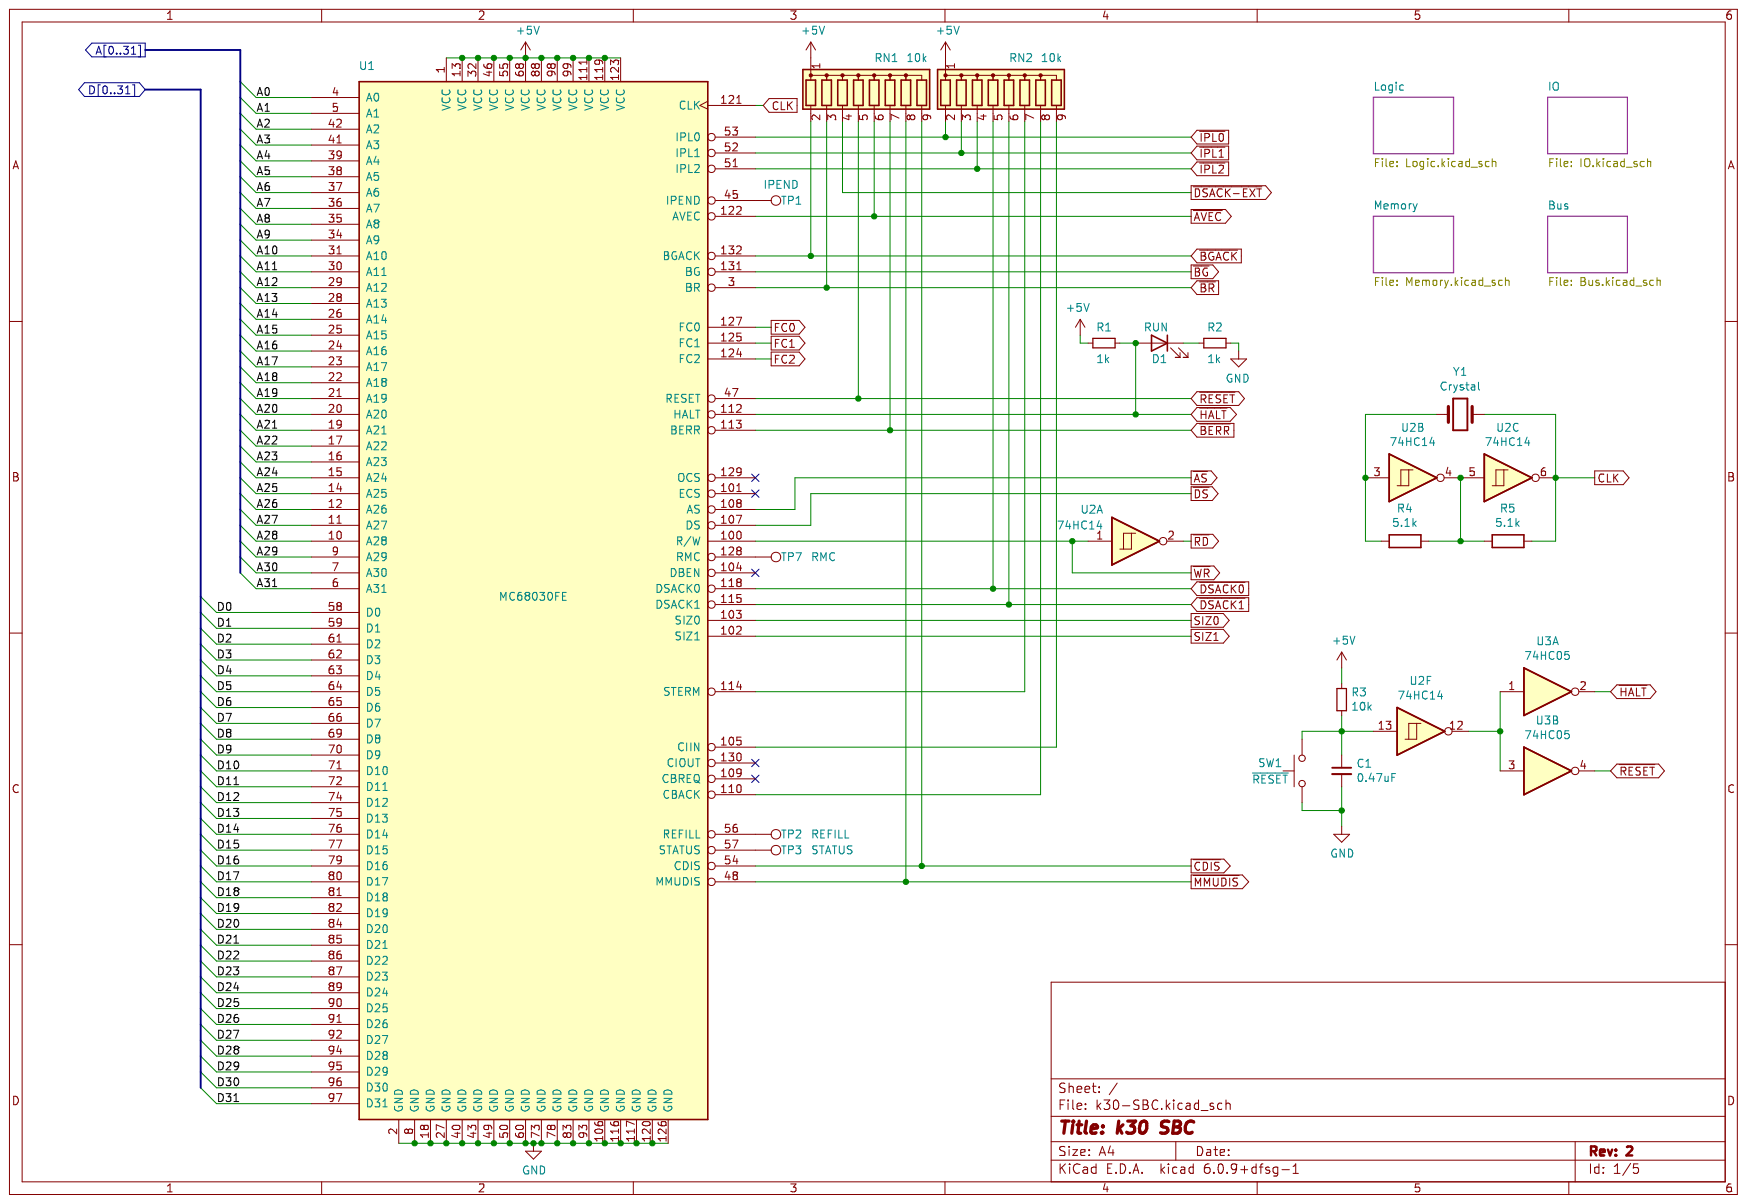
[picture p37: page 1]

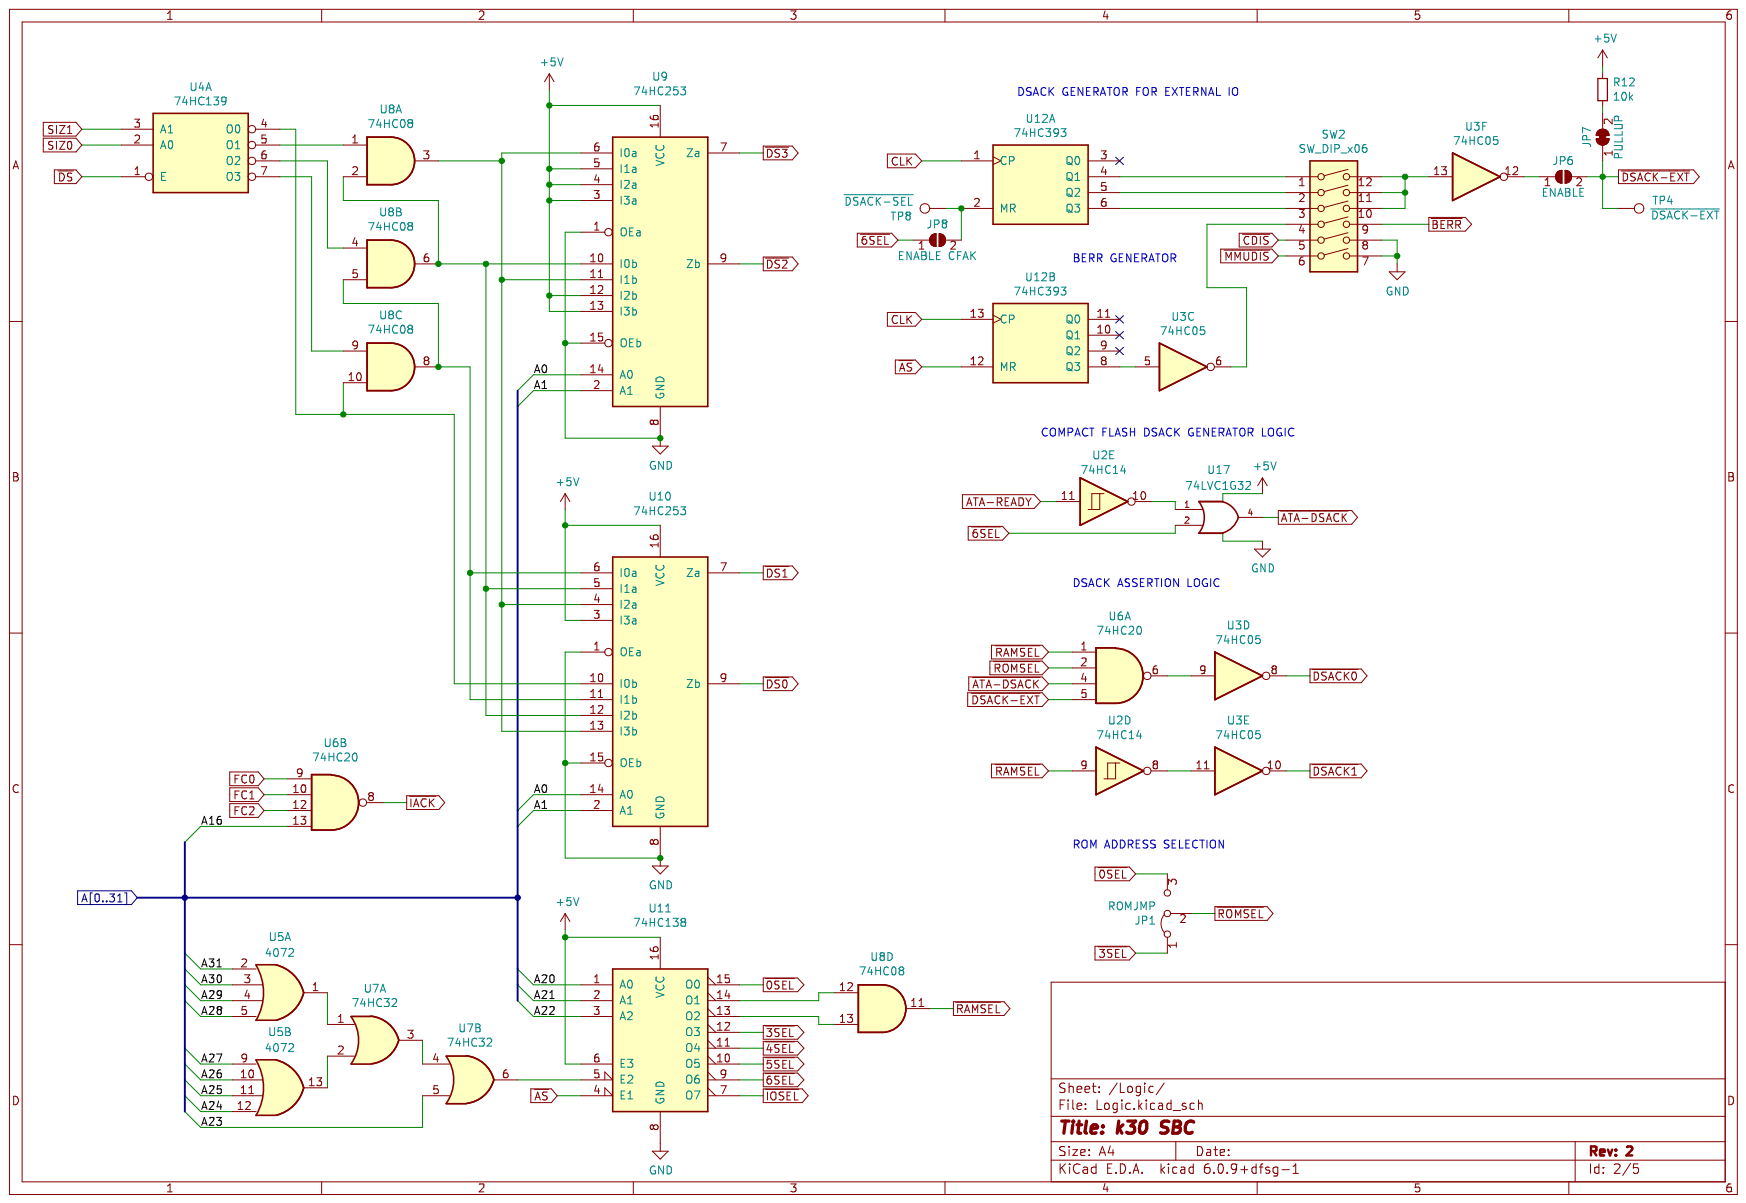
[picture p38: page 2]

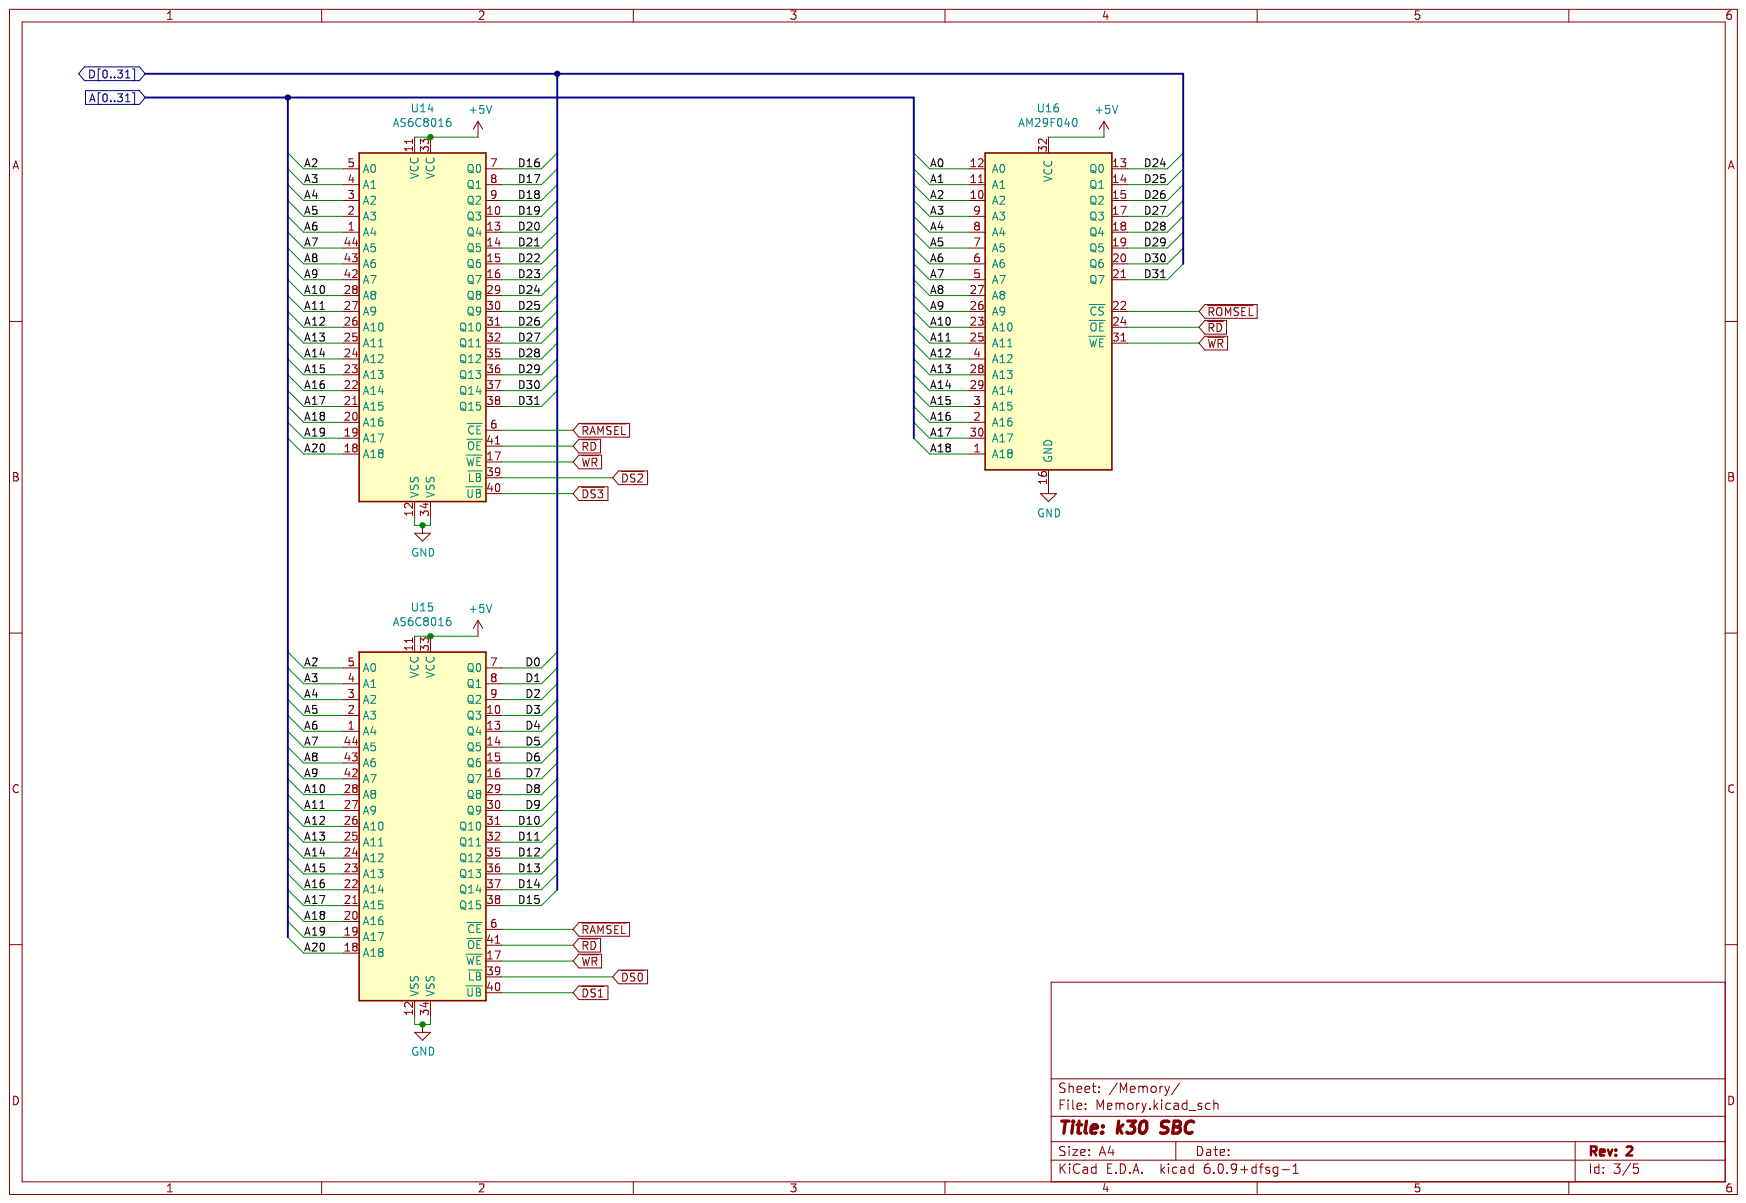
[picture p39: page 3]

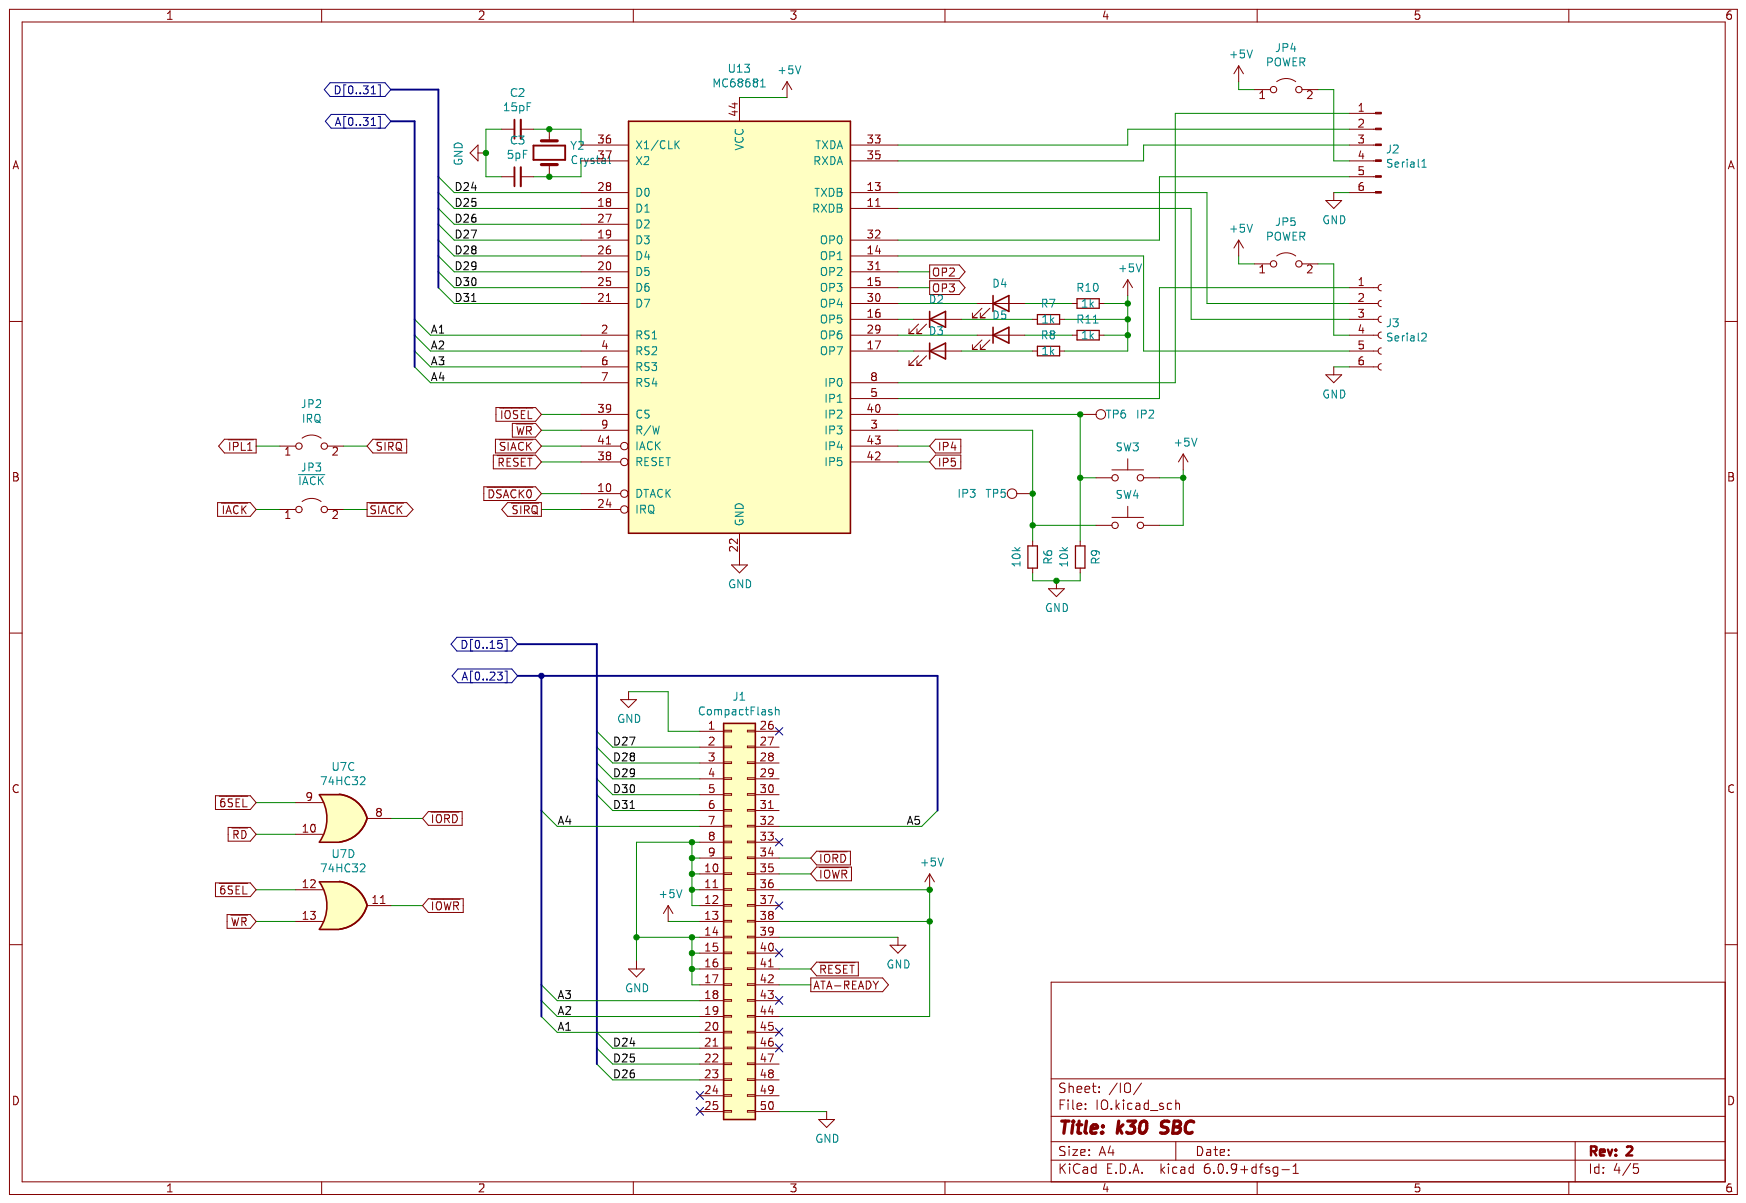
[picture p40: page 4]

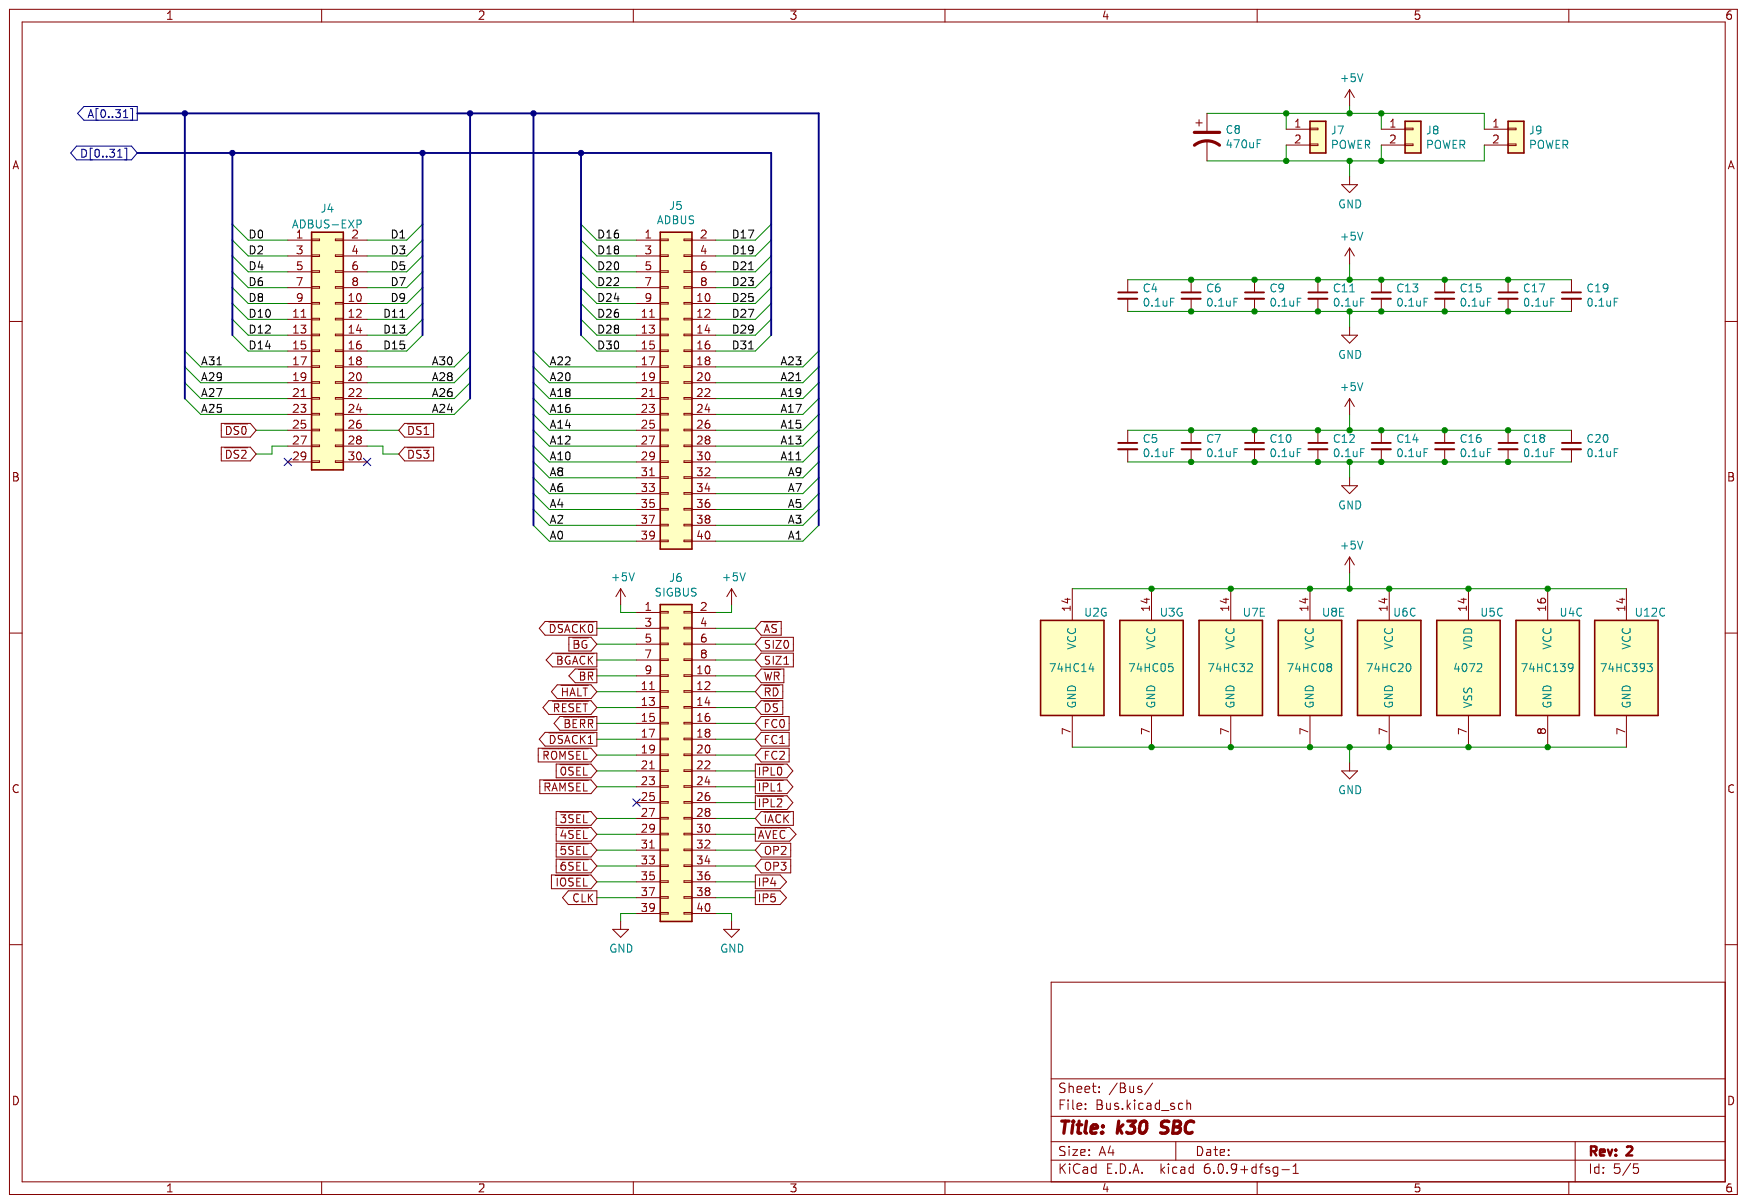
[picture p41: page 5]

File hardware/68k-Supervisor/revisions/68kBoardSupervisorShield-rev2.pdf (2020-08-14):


Id: 1/1 Title: 68k-SBC Supervisor Shield

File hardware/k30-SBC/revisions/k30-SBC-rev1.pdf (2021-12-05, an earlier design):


File: IO.sch Sheet: Memory

File: k30-SBC.sch Sheet: /
Id: 1/5 Title: k30 SBC


DSACK GENERATOR FOR COMPACT FLASH

I1a 5
I2a 4

I1b 11
I2b 12


File: IO.sch Sheet: /IO/
Id: 3/5 Title: k30 SBC



0.1uF VCC 14 GND
File: Bus.sch Sheet: /Bus/ VCC 14 GND

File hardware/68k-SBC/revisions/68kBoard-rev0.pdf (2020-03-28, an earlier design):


Id: 1/3 Title: File: 68kBoard.sch Sheet: /



Id: 3/3 Title: File: UART.sch Sheet: /UART/

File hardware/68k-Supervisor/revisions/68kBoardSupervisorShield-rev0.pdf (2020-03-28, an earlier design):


File: 68kBoardSupervisorShield.sch Sheet: / GND

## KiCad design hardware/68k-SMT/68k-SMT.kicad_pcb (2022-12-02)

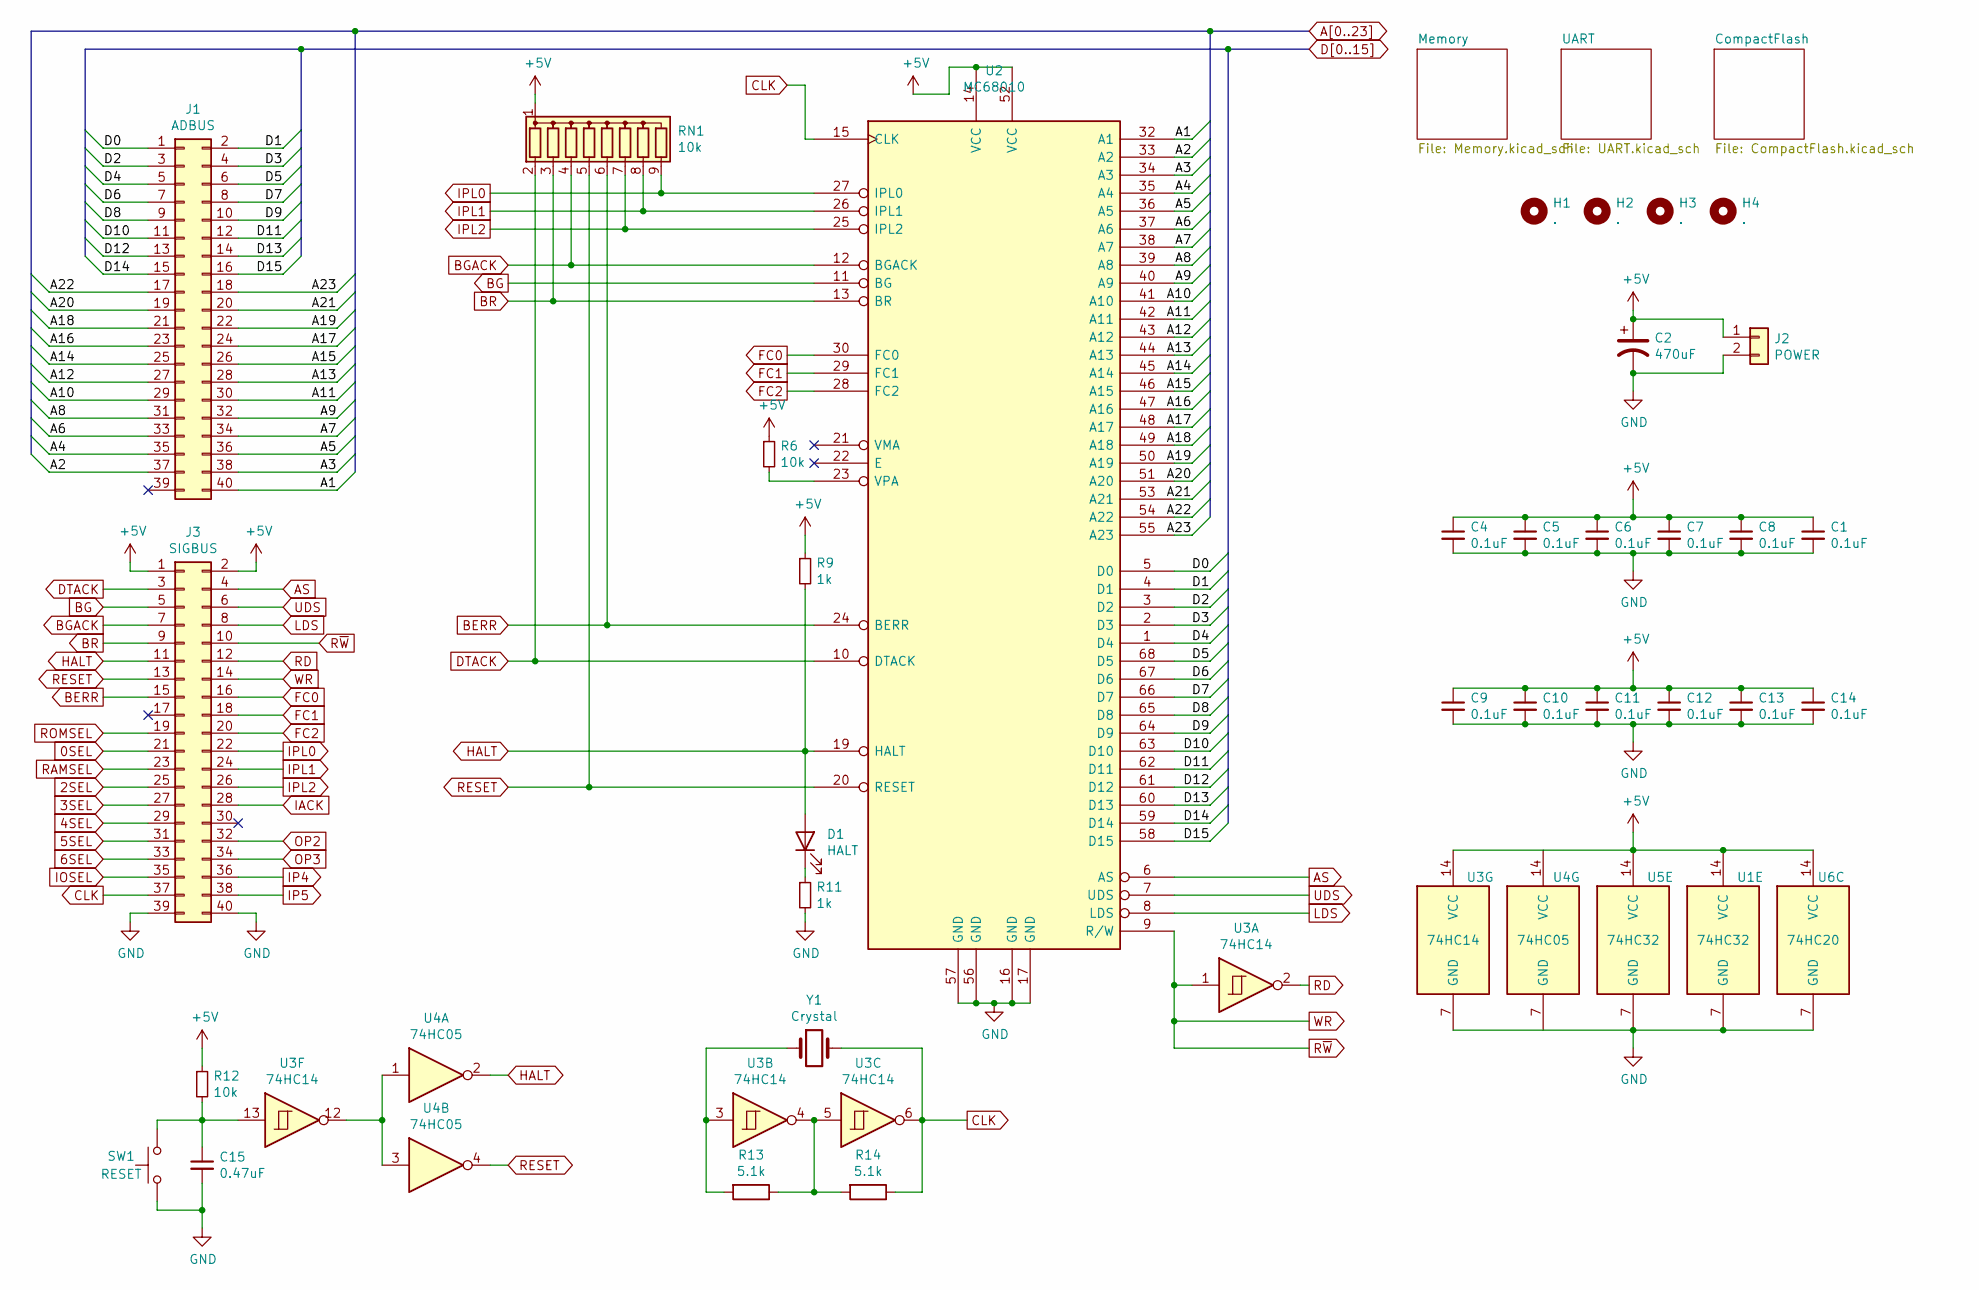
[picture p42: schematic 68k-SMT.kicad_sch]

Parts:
C1, C4, C5, C6, C7, C8, C9, C10, C11, C12, C13, C14: 0.1uF; C_Disc_D3.0mm_W2.0mm_P2.50mm
C2: 470uF; CP_Radial_D10.0mm_P5.00mm
C15: 0.47uF; C_Disc_D3.0mm_W2.0mm_P2.50mm
D1: HALT; LED_D5.0mm
H1, H2, H3, H4: .; MountingHole_2.7mm_Pad_Via
J1: ADBUS; PinHeader_2x20_P2.54mm_Vertical
J2: POWER; PinHeader_1x02_P2.54mm_Vertical
J3: SIGBUS; PinHeader_2x20_P2.54mm_Vertical
R6, R12: 10k; R_Axial_DIN0204_L3.6mm_D1.6mm_P5.08mm_Horizontal
R9, R11: 1k; R_Axial_DIN0204_L3.6mm_D1.6mm_P5.08mm_Horizontal
R13, R14: 5.1k; R_Axial_DIN0204_L3.6mm_D1.6mm_P5.08mm_Horizontal
RN1: 10k; R_Array_SIP9
SW1: RESET; SW_PUSH_6mm
U1, U5: 74HC32; TSSOP-14_4.4x5mm_P0.65mm
U2: MC68010; PLCC-68_THT-Socket
U3: 74HC14; TSSOP-14_4.4x5mm_P0.65mm
U4: 74HC05; TSSOP-14_4.4x5mm_P0.65mm
U6: 74HC20; TSSOP-14_4.4x5mm_P0.65mm
Y1: Crystal; Crystal_HC49-4H_Vertical

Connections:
0SEL: J3.21; also elsewhere on the board
2SEL: J3.25; also elsewhere on the board
3SEL: J3.27; also elsewhere on the board
4SEL: J3.29; also elsewhere on the board
5SEL: J3.31; also elsewhere on the board
6SEL: J3.33; also elsewhere on the board
+5V: C1.1, C2.1, C4.1, C5.1, C6.1, C7.1, C8.1, C9.1, C10.1, C11.1, C12.1, C13.1, C14.1, J2.1, J3.1, J3.2, R6.1, R9.1, R12.1, RN1.1 (common), U1.14 (VCC), U2.14 (VCC), U2.52 (VCC), U3.14 (VCC), U4.14 (VCC), U5.14 (VCC), U6.14 (VCC); also elsewhere on the board
A1: J1.40, U2.32 (A1); also elsewhere on the board
A2: J1.37, U2.33 (A2); also elsewhere on the board
A3: J1.38, U2.34 (A3); also elsewhere on the board
A4: J1.35, U2.35 (A4); also elsewhere on the board
A5: J1.36, U2.36 (A5); also elsewhere on the board
A6: J1.33, U2.37 (A6); also elsewhere on the board
A7: J1.34, U2.38 (A7); also elsewhere on the board
A8: J1.31, U2.39 (A8); also elsewhere on the board
A9: J1.32, U2.40 (A9); also elsewhere on the board
A10: J1.29, U2.41 (A10); also elsewhere on the board
A11: J1.30, U2.42 (A11); also elsewhere on the board
A12: J1.27, U2.43 (A12); also elsewhere on the board
A13: J1.28, U2.44 (A13); also elsewhere on the board
A14: J1.25, U2.45 (A14); also elsewhere on the board
A15: J1.26, U2.46 (A15); also elsewhere on the board
A16: J1.23, U2.47 (A16); also elsewhere on the board
A17: J1.24, U2.48 (A17); also elsewhere on the board
A18: J1.21, U2.49 (A18); also elsewhere on the board
A19: J1.22, U2.50 (A19); also elsewhere on the board
A20: J1.19, U2.51 (A20); also elsewhere on the board
A21: J1.20, U2.53 (A21); also elsewhere on the board
A22: J1.17, U2.54 (A22); also elsewhere on the board
A23: J1.18, U2.55 (A23); also elsewhere on the board
AS: J3.4, U2.6 (AS); also elsewhere on the board
BERR: J3.15, RN1.6 (R5), U2.24 (BERR)
BG: J3.5, U2.11 (BG)
BGACK: J3.7, RN1.4 (R3), U2.12 (BGACK)
BR: J3.9, RN1.3 (R2), U2.13 (BR)
CLK: J3.37, R14.1, U2.15 (CLK), U3.6, Y1.2
D0: J1.1, U2.5 (D0); also elsewhere on the board
D1: J1.2, U2.4 (D1); also elsewhere on the board
D2: J1.3, U2.3 (D2); also elsewhere on the board
D3: J1.4, U2.2 (D3); also elsewhere on the board
D4: J1.5, U2.1 (D4); also elsewhere on the board
D5: J1.6, U2.68 (D5); also elsewhere on the board
D6: J1.7, U2.67 (D6); also elsewhere on the board
D7: J1.8, U2.66 (D7); also elsewhere on the board
D8: J1.9, U2.65 (D8); also elsewhere on the board
D9: J1.10, U2.64 (D9); also elsewhere on the board
D10: J1.11, U2.63 (D10); also elsewhere on the board
D11: J1.12, U2.62 (D11); also elsewhere on the board
D12: J1.13, U2.61 (D12); also elsewhere on the board
D13: J1.14, U2.60 (D13); also elsewhere on the board
D14: J1.15, U2.59 (D14); also elsewhere on the board
D15: J1.16, U2.58 (D15); also elsewhere on the board
DTACK: J3.3, RN1.2 (R1), U2.10 (DTACK); also elsewhere on the board
FC0: J3.16, U2.30 (FC0); also elsewhere on the board
FC1: J3.18, U2.29 (FC1); also elsewhere on the board
FC2: J3.20, U2.28 (FC2); also elsewhere on the board
GND: C1.2, C2.2, C4.2, C5.2, C6.2, C7.2, C8.2, C9.2, C10.2, C11.2, C12.2, C13.2, C14.2, C15.2, J2.2, J3.39, J3.40, R11.2, SW1.1, U1.7 (GND), U2.16 (GND), U2.17 (GND), U2.56 (GND), U2.57 (GND), U3.7 (GND), U4.7 (GND), U5.7 (GND), U6.7 (GND); also elsewhere on the board
HALT: D1.2 (A), J3.11, R9.2, U2.19 (HALT), U4.2
IACK: J3.28; also elsewhere on the board
IOSEL: J3.35; also elsewhere on the board
IP4: J3.36; also elsewhere on the board
IP5: J3.38; also elsewhere on the board
IPL0: J3.22, RN1.9 (R8), U2.27 (IPL0)
IPL1: J3.24, RN1.8 (R7), U2.26 (IPL1); also elsewhere on the board
IPL2: J3.26, RN1.7 (R6), U2.25 (IPL2)
LDS: J3.8, U2.8 (LDS); also elsewhere on the board
unnamed: C15.1, R12.2, SW1.2, U3.13
unnamed: D1.1 (K), R11.1
unnamed: R6.2, U2.23 (VPA)
unnamed: R13.1, R14.2, U3.4, U3.5
unnamed: R13.2, U3.3, Y1.1
unnamed: U3.12, U4.1, U4.3
OP2: J3.32; also elsewhere on the board
OP3: J3.34; also elsewhere on the board
RAMSEL: J3.23; also elsewhere on the board
RD: J3.12, U3.2; also elsewhere on the board
RESET: J3.13, RN1.5 (R4), U2.20 (RESET), U4.4; also elsewhere on the board
ROMSEL: J3.19; also elsewhere on the board
R~W: J3.10, J3.14, U2.9 (R/W), U3.1; also elsewhere on the board
UDS: J3.6, U2.7 (UDS); also elsewhere on the board

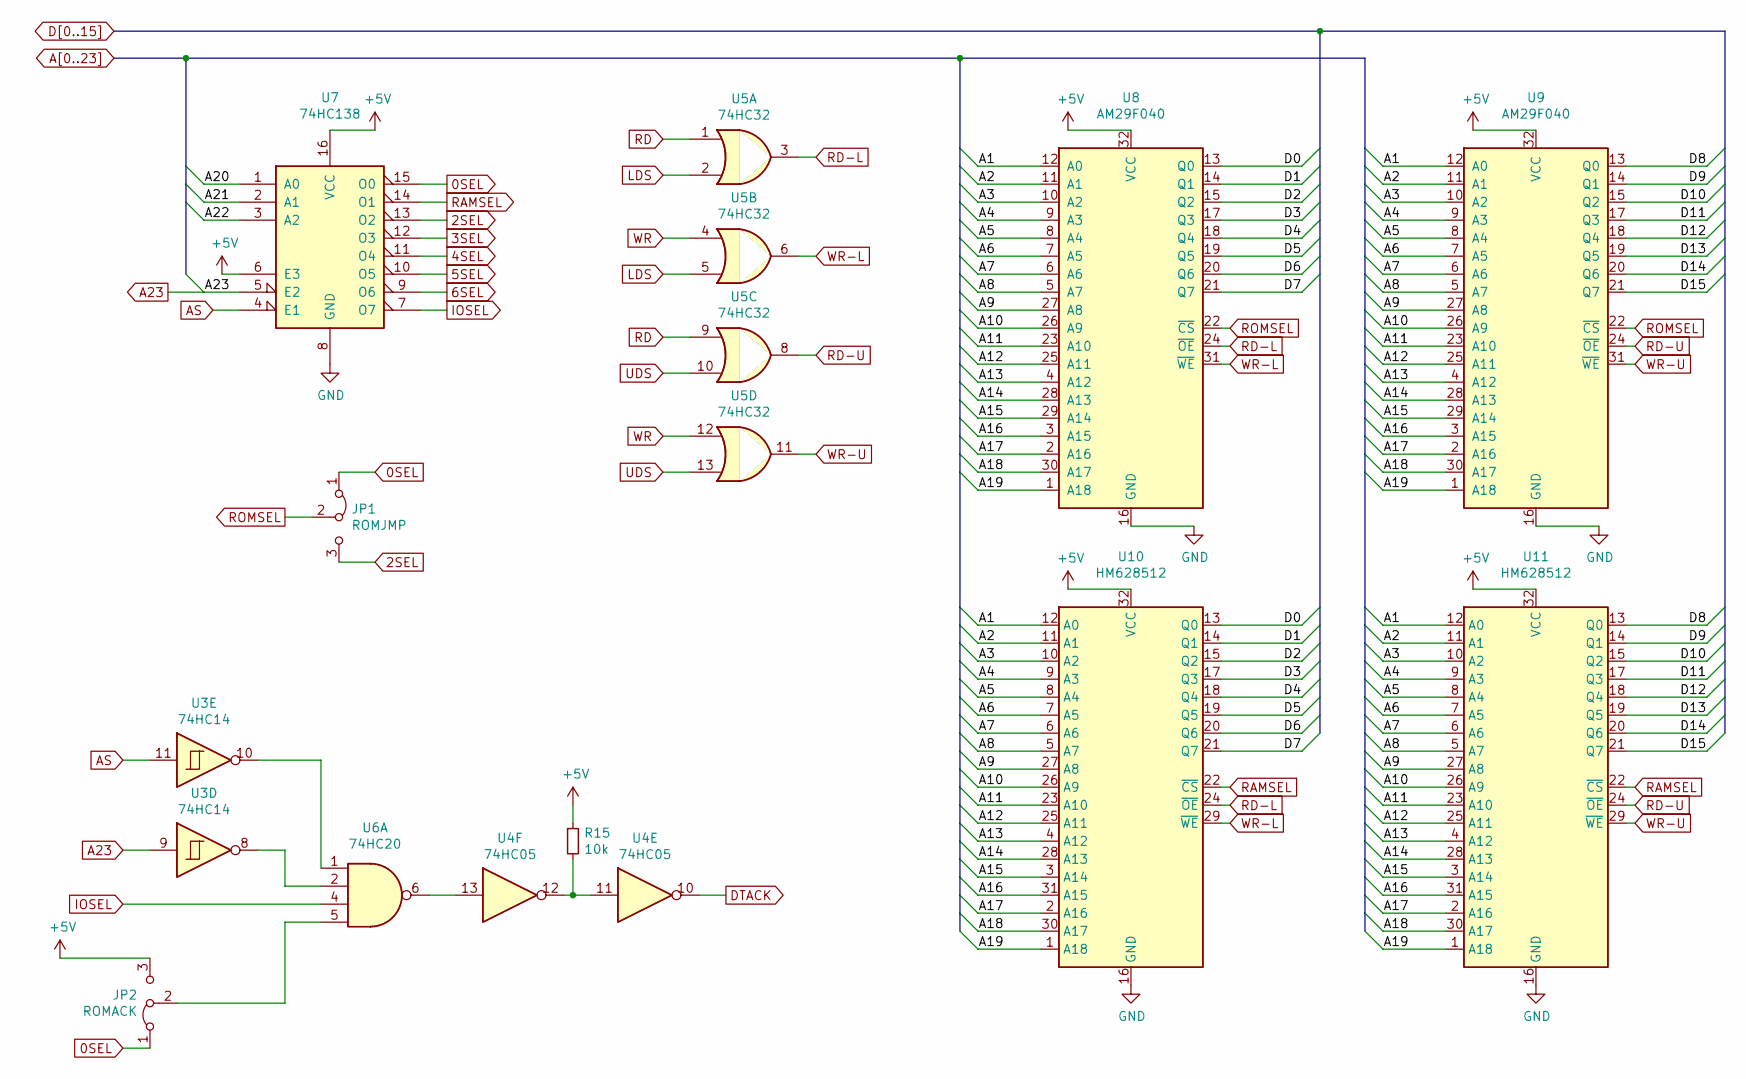
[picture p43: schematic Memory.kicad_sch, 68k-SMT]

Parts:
JP1: ROMJMP; PinHeader_1x03_P2.54mm_Vertical
JP2: ROMACK; PinHeader_1x03_P2.54mm_Vertical
R15: 10k; R_Axial_DIN0204_L3.6mm_D1.6mm_P5.08mm_Horizontal
U3: 74HC14; TSSOP-14_4.4x5mm_P0.65mm
U4: 74HC05; TSSOP-14_4.4x5mm_P0.65mm
U5: 74HC32; TSSOP-14_4.4x5mm_P0.65mm
U6: 74HC20; TSSOP-14_4.4x5mm_P0.65mm
U7: 74HC138; TSSOP-16_4.4x5mm_P0.65mm
U8, U9: AM29F040; PLCC-32_THT-Socket
U10, U11: HM628512; TSOP-II-32_21.0x10.2mm_P1.27mm

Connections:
0SEL: JP1.1 (A), JP2.1 (A), U7.15 (O0); also elsewhere on the board
2SEL: JP1.3 (B), U7.13 (O2); also elsewhere on the board
3SEL: U7.12 (O3); also elsewhere on the board
4SEL: U7.11 (O4); also elsewhere on the board
5SEL: U7.10 (O5); also elsewhere on the board
6SEL: U7.9 (O6); also elsewhere on the board
+5V: JP2.3 (B), R15.1, U7.6 (E3), U7.16 (VCC), U8.32 (VCC), U9.32 (VCC), U10.32 (VCC), U11.32 (VCC); also elsewhere on the board
A1: U8.12 (A0), U9.12 (A0), U10.12 (A0), U11.12 (A0); also elsewhere on the board
A2: U8.11 (A1), U9.11 (A1), U10.11 (A1), U11.11 (A1); also elsewhere on the board
A3: U8.10 (A2), U9.10 (A2), U10.10 (A2), U11.10 (A2); also elsewhere on the board
A4: U8.9 (A3), U9.9 (A3), U10.9 (A3), U11.9 (A3); also elsewhere on the board
A5: U8.8 (A4), U9.8 (A4), U10.8 (A4), U11.8 (A4); also elsewhere on the board
A6: U8.7 (A5), U9.7 (A5), U10.7 (A5), U11.7 (A5); also elsewhere on the board
A7: U8.6 (A6), U9.6 (A6), U10.6 (A6), U11.6 (A6); also elsewhere on the board
A8: U8.5 (A7), U9.5 (A7), U10.5 (A7), U11.5 (A7); also elsewhere on the board
A9: U8.27 (A8), U9.27 (A8), U10.27 (A8), U11.27 (A8); also elsewhere on the board
A10: U8.26 (A9), U9.26 (A9), U10.26 (A9), U11.26 (A9); also elsewhere on the board
A11: U8.23 (A10), U9.23 (A10), U10.23 (A10), U11.23 (A10); also elsewhere on the board
A12: U8.25 (A11), U9.25 (A11), U10.25 (A11), U11.25 (A11); also elsewhere on the board
A13: U8.4 (A12), U9.4 (A12), U10.4 (A12), U11.4 (A12); also elsewhere on the board
A14: U8.28 (A13), U9.28 (A13), U10.28 (A13), U11.28 (A13); also elsewhere on the board
A15: U8.29 (A14), U9.29 (A14), U10.3 (A14), U11.3 (A14); also elsewhere on the board
A16: U8.3 (A15), U9.3 (A15), U10.31 (A15), U11.31 (A15); also elsewhere on the board
A17: U8.2 (A16), U9.2 (A16), U10.2 (A16), U11.2 (A16); also elsewhere on the board
A18: U8.30 (A17), U9.30 (A17), U10.30 (A17), U11.30 (A17); also elsewhere on the board
A19: U8.1 (A18), U9.1 (A18), U10.1 (A18), U11.1 (A18); also elsewhere on the board
A20: U7.1 (A0); also elsewhere on the board
A21: U7.2 (A1); also elsewhere on the board
A22: U7.3 (A2); also elsewhere on the board
A23: U3.9, U7.5 (E2); also elsewhere on the board
AS: U3.11, U7.4 (E1); also elsewhere on the board
D0: U8.13 (Q0), U10.13 (Q0); also elsewhere on the board
D1: U8.14 (Q1), U10.14 (Q1); also elsewhere on the board
D2: U8.15 (Q2), U10.15 (Q2); also elsewhere on the board
D3: U8.17 (Q3), U10.17 (Q3); also elsewhere on the board
D4: U8.18 (Q4), U10.18 (Q4); also elsewhere on the board
D5: U8.19 (Q5), U10.19 (Q5); also elsewhere on the board
D6: U8.20 (Q6), U10.20 (Q6); also elsewhere on the board
D7: U8.21 (Q7), U10.21 (Q7); also elsewhere on the board
D8: U9.13 (Q0), U11.13 (Q0); also elsewhere on the board
D9: U9.14 (Q1), U11.14 (Q1); also elsewhere on the board
D10: U9.15 (Q2), U11.15 (Q2); also elsewhere on the board
D11: U9.17 (Q3), U11.17 (Q3); also elsewhere on the board
D12: U9.18 (Q4), U11.18 (Q4); also elsewhere on the board
D13: U9.19 (Q5), U11.19 (Q5); also elsewhere on the board
D14: U9.20 (Q6), U11.20 (Q6); also elsewhere on the board
D15: U9.21 (Q7), U11.21 (Q7); also elsewhere on the board
DTACK: U4.10; also elsewhere on the board
GND: U7.8 (GND), U8.16 (GND), U9.16 (GND), U10.16 (GND), U11.16 (GND); also elsewhere on the board
IOSEL: U6.4, U7.7 (O7); also elsewhere on the board
LDS: U5.2, U5.5; also elsewhere on the board
unnamed: JP2.2 (C), U6.5
unnamed: R15.2, U4.11, U4.12
unnamed: U3.8, U6.2
unnamed: U3.10, U6.1
unnamed: U4.13, U6.6
RAMSEL: U7.14 (O1), U10.22 (~CS), U11.22 (~CS); also elsewhere on the board
RD: U5.1, U5.9; also elsewhere on the board
RD-L: U5.3, U8.24 (~OE), U10.24 (~OE)
RD-U: U5.8, U9.24 (~OE), U11.24 (~OE)
ROMSEL: JP1.2 (C), U8.22 (~CS), U9.22 (~CS); also elsewhere on the board
R~W: U5.4, U5.12; also elsewhere on the board
UDS: U5.10, U5.13; also elsewhere on the board
WR-L: U5.6, U8.31 (~WE), U10.29 (~WE)
WR-U: U5.11, U9.31 (~WE), U11.29 (~WE)

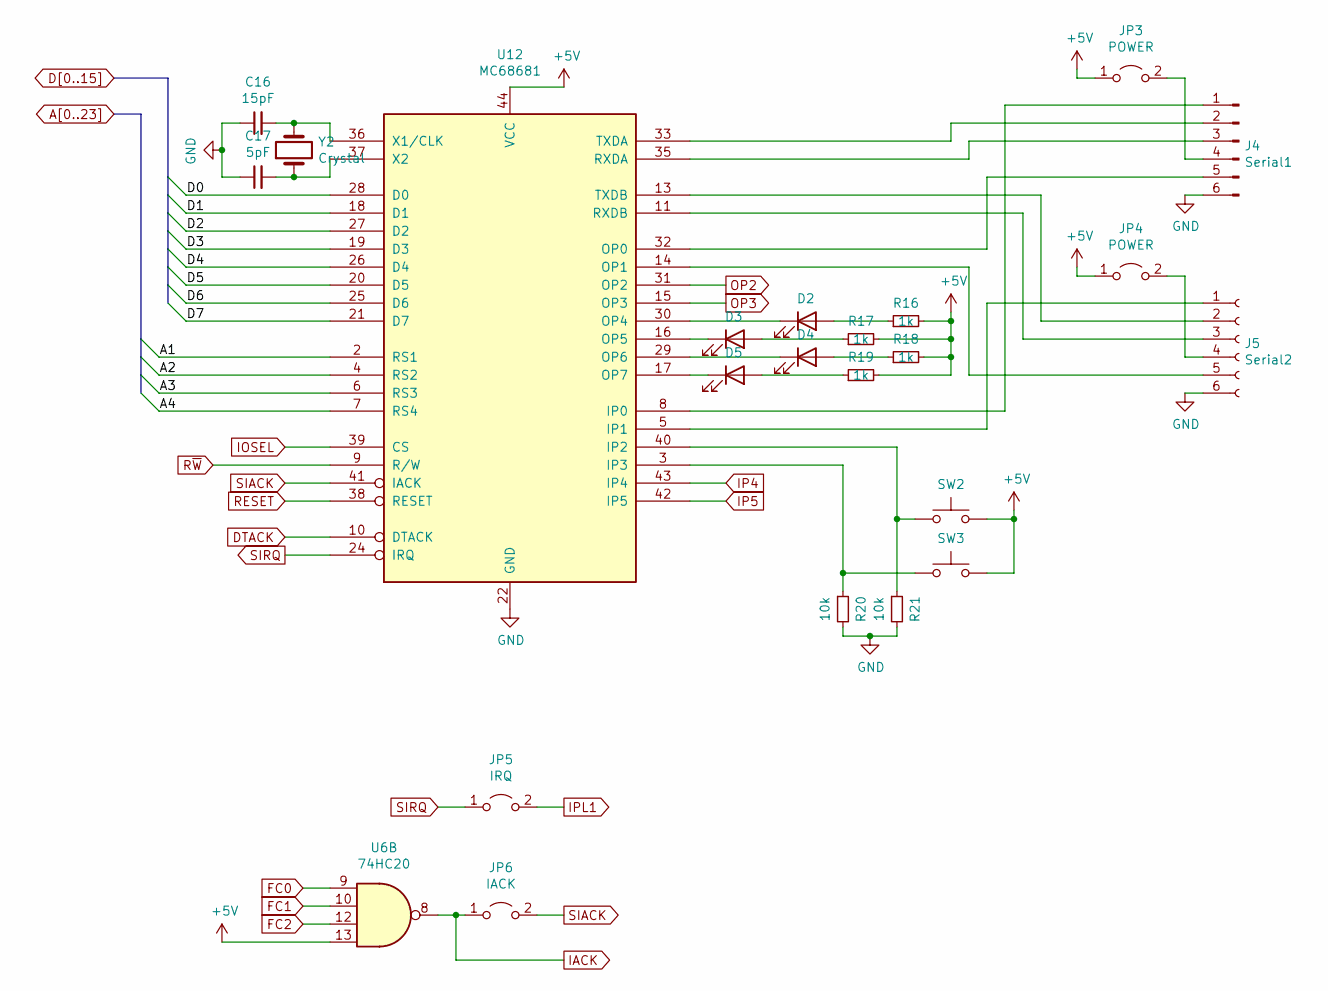
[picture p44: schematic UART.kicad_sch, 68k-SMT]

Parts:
C16: 15pF; C_Disc_D3.0mm_W2.0mm_P2.50mm
C17: 5pF; C_Disc_D3.0mm_W2.0mm_P2.50mm
D2: OP4; LED_D5.0mm
D3: OP5; LED_D5.0mm
D4: OP6; LED_D5.0mm
D5: OP7; LED_D5.0mm
J4: Serial1; PinHeader_1x06_P2.54mm_Horizontal
J5: Serial2; PinHeader_1x06_P2.54mm_Horizontal
JP3, JP4: POWER; PinHeader_1x02_P2.54mm_Vertical
JP5: IRQ; PinHeader_1x02_P2.54mm_Vertical
JP6: IACK; PinHeader_1x02_P2.54mm_Vertical
R16, R17, R18, R19: 1k; R_Axial_DIN0204_L3.6mm_D1.6mm_P5.08mm_Horizontal
R20, R21: 10k; R_Axial_DIN0204_L3.6mm_D1.6mm_P5.08mm_Horizontal
SW2: IP2; SW_PUSH_6mm
SW3: IP3; SW_PUSH_6mm
U6: 74HC20; TSSOP-14_4.4x5mm_P0.65mm
U12: MC68681; PLCC-68_THT-Socket
Y2: Crystal; Crystal_HC49-4H_Vertical

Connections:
+5V: JP3.1 (A), JP4.1 (A), R16.2, R17.2, R18.2, R19.2, SW2.2, SW3.2, U6.13, U12.44 (VCC); also elsewhere on the board
A1: U12.2 (RS1); also elsewhere on the board
A2: U12.4 (RS2); also elsewhere on the board
A3: U12.6 (RS3); also elsewhere on the board
A4: U12.7 (RS4); also elsewhere on the board
D0: U12.28 (D0); also elsewhere on the board
D1: U12.18 (D1); also elsewhere on the board
D2: U12.27 (D2); also elsewhere on the board
D3: U12.19 (D3); also elsewhere on the board
D4: U12.26 (D4); also elsewhere on the board
D5: U12.20 (D5); also elsewhere on the board
D6: U12.25 (D6); also elsewhere on the board
D7: U12.21 (D7); also elsewhere on the board
DTACK: U12.10 (DTACK); also elsewhere on the board
FC0: U6.9; also elsewhere on the board
FC1: U6.10; also elsewhere on the board
FC2: U6.12; also elsewhere on the board
GND: C16.1, C17.1, J4.6, J5.6, R20.2, R21.2, U12.22 (GND); also elsewhere on the board
IACK: JP6.1 (A), U6.8; also elsewhere on the board
IOSEL: U12.39 (CS); also elsewhere on the board
IP4: U12.43 (IP4); also elsewhere on the board
IP5: U12.42 (IP5); also elsewhere on the board
IPL1: JP5.2 (B); also elsewhere on the board
unnamed: C16.2, U12.36 (X1/CLK), Y2.2
unnamed: C17.2, U12.37 (X2), Y2.1
unnamed: D2.1 (K), U12.30 (OP4)
unnamed: D2.2 (A), R16.1
unnamed: D3.1 (K), U12.16 (OP5)
unnamed: D3.2 (A), R17.1
unnamed: D4.1 (K), U12.29 (OP6)
unnamed: D4.2 (A), R18.1
unnamed: D5.1 (K), U12.17 (OP7)
unnamed: D5.2 (A), R19.1
unnamed: J4.1, U12.8 (IP0)
unnamed: J4.2, U12.33 (TXDA)
unnamed: J4.3, U12.35 (RXDA)
unnamed: J4.4, JP3.2 (B)
unnamed: J4.5, U12.32 (OP0)
unnamed: J5.1, U12.5 (IP1)
unnamed: J5.2, U12.13 (TXDB)
unnamed: J5.3, U12.11 (RXDB)
unnamed: J5.4, JP4.2 (B)
unnamed: J5.5, U12.14 (OP1)
unnamed: R20.1, SW3.1, U12.3 (IP3)
unnamed: R21.1, SW2.1, U12.40 (IP2)
OP2: U12.31 (OP2); also elsewhere on the board
OP3: U12.15 (OP3); also elsewhere on the board
RESET: U12.38 (RESET); also elsewhere on the board
R~W: U12.9 (R/W); also elsewhere on the board
SIACK: JP6.2 (B), U12.41 (IACK)
SIRQ: JP5.1 (A), U12.24 (IRQ)

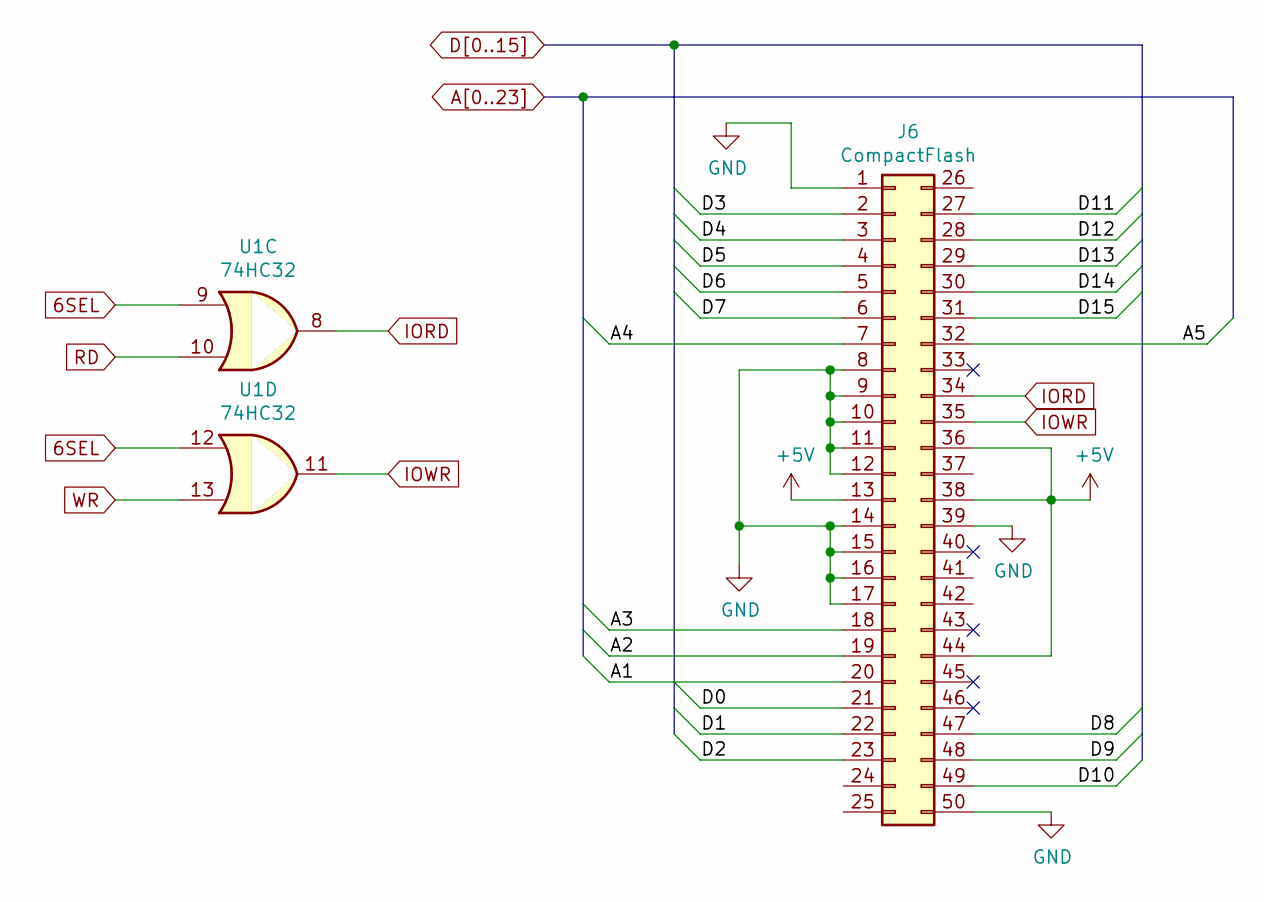
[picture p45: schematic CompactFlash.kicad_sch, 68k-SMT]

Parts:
J6: CompactFlash; CF-Card_3M_N7E50-Q516RB-40
U1: 74HC32; TSSOP-14_4.4x5mm_P0.65mm

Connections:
6SEL: U1.9, U1.12; also elsewhere on the board
+5V: J6.13, J6.36, J6.38, J6.44; also elsewhere on the board
A1: J6.20; also elsewhere on the board
A2: J6.19; also elsewhere on the board
A3: J6.18; also elsewhere on the board
A4: J6.7; also elsewhere on the board
A5: J6.32; also elsewhere on the board
D0: J6.21; also elsewhere on the board
D1: J6.22; also elsewhere on the board
D2: J6.23; also elsewhere on the board
D3: J6.2; also elsewhere on the board
D4: J6.3; also elsewhere on the board
D5: J6.4; also elsewhere on the board
D6: J6.5; also elsewhere on the board
D7: J6.6; also elsewhere on the board
D8: J6.47; also elsewhere on the board
D9: J6.48; also elsewhere on the board
D10: J6.49; also elsewhere on the board
D11: J6.27; also elsewhere on the board
D12: J6.28; also elsewhere on the board
D13: J6.29; also elsewhere on the board
D14: J6.30; also elsewhere on the board
D15: J6.31; also elsewhere on the board
GND: J6.1, J6.8, J6.9, J6.10, J6.11, J6.12, J6.14, J6.15, J6.16, J6.17, J6.39, J6.50; also elsewhere on the board
IORD: J6.34, U1.8
IOWR: J6.35, U1.11
RD: U1.10; also elsewhere on the board
R~W: U1.13; also elsewhere on the board

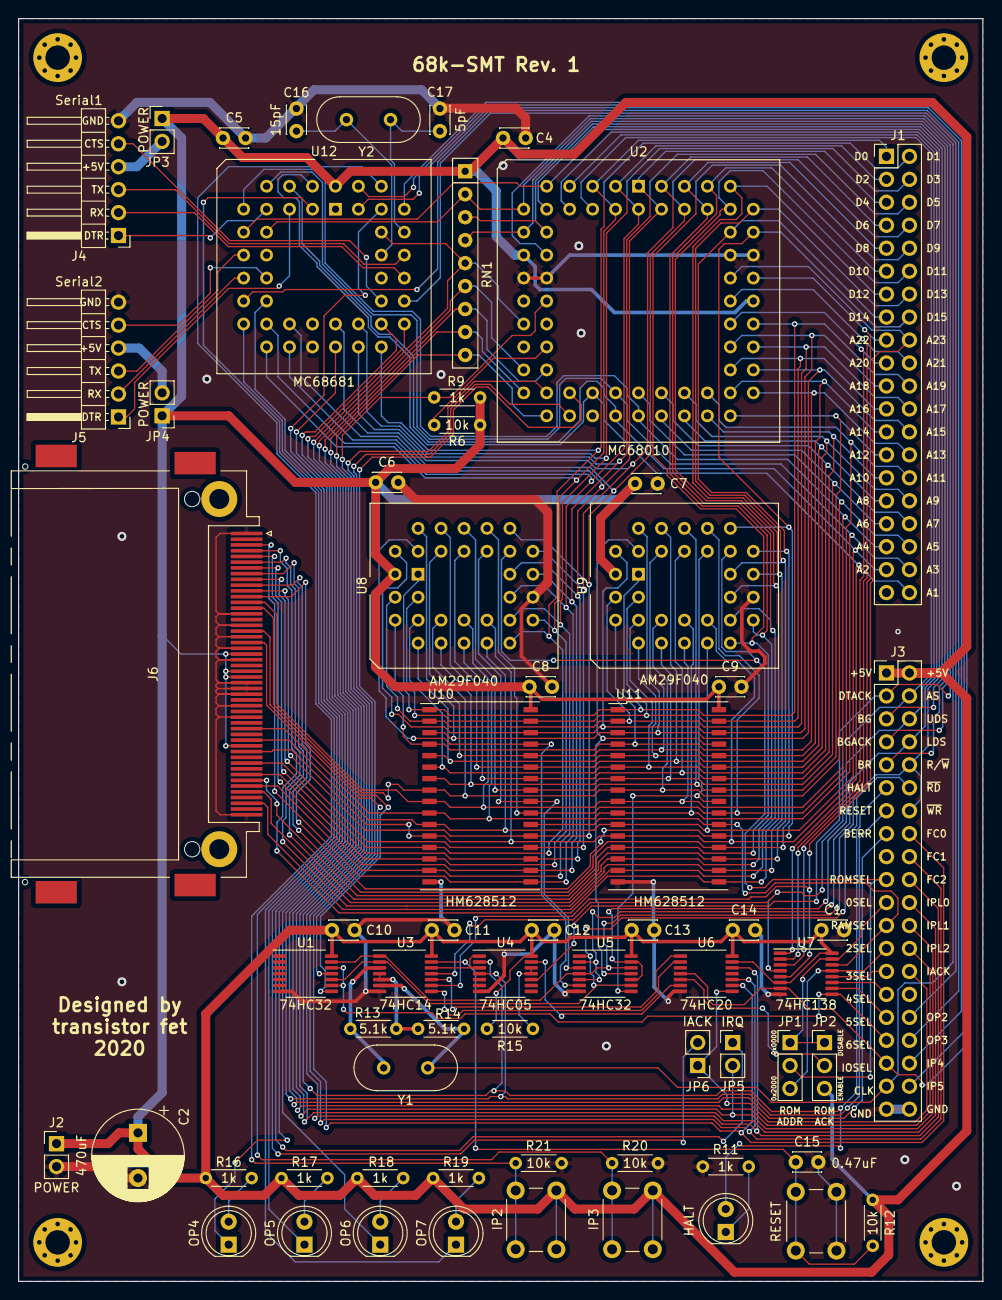
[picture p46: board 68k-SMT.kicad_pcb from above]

Board: 2 copper layers, 106.7 x 139.7 mm, 68 parts (0 on the bottom side), 115 nets.

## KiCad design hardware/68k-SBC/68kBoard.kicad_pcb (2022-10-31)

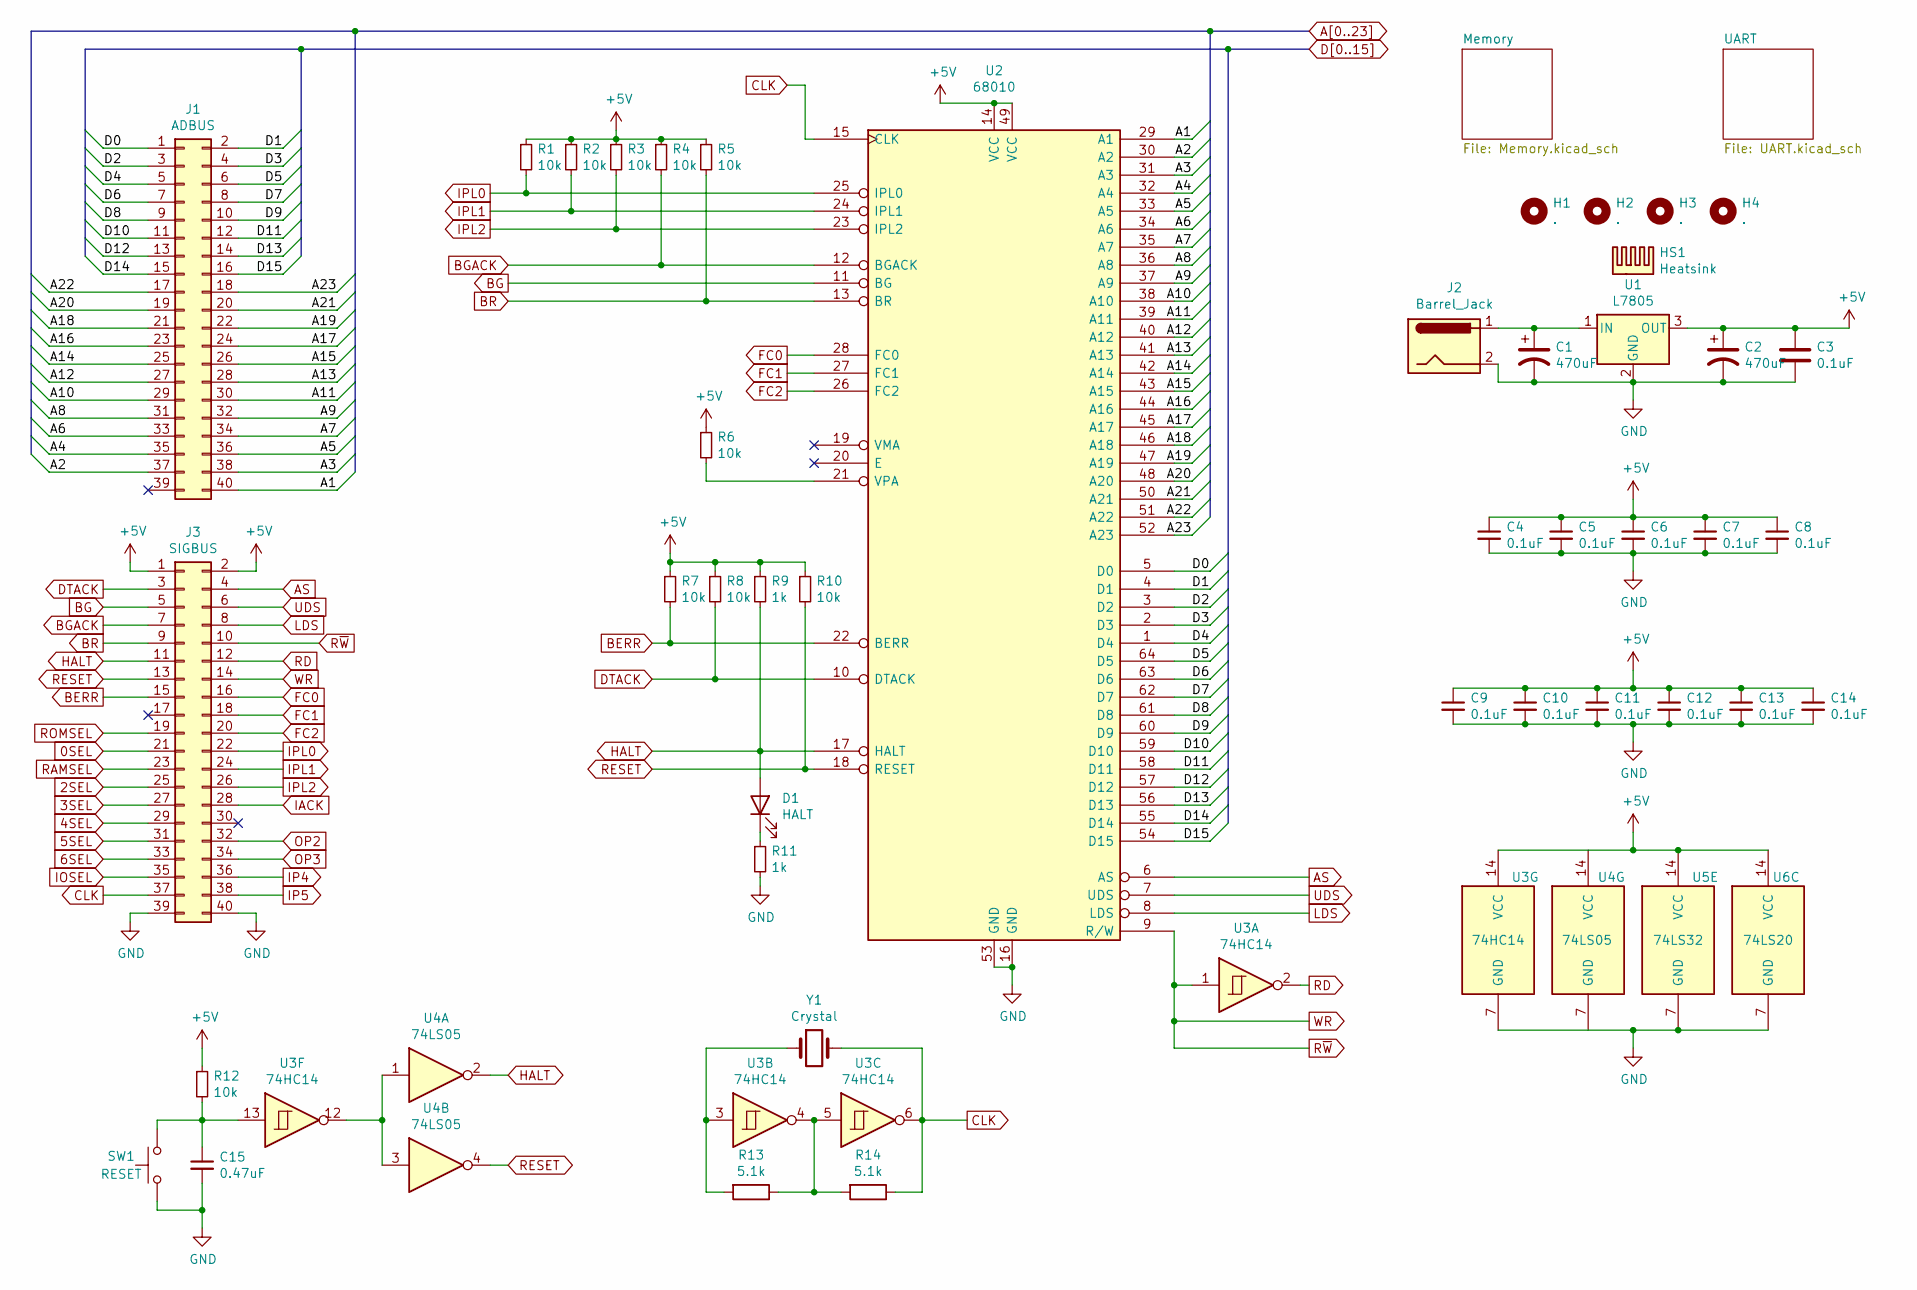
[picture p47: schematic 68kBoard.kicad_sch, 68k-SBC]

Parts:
C1, C2: 470uF; CP_Radial_D10.0mm_P5.00mm
C3, C4, C5, C6, C7, C8, C9, C10, C11, C12, C13, C14: 0.1uF; C_Disc_D3.0mm_W2.0mm_P2.50mm
C15: 0.47uF; C_Disc_D3.0mm_W2.0mm_P2.50mm
D1: HALT; LED_D5.0mm
H1, H2, H3, H4: .; MountingHole_2.7mm_Pad_Via
HS1: Heatsink; Heatsink_Fischer_SK104-STC-STIC_35x13mm_2xDrill2.5mm
J1: ADBUS; PinHeader_2x20_P2.54mm_Vertical
J2: Barrel_Jack; BarrelJack_Horizontal
J3: SIGBUS; PinHeader_2x20_P2.54mm_Vertical
R1, R2, R3, R4, R5, R6, R7, R8, R10, R12: 10k; R_Axial_DIN0207_L6.3mm_D2.5mm_P7.62mm_Horizontal
R9, R11: 1k; R_Axial_DIN0207_L6.3mm_D2.5mm_P7.62mm_Horizontal
R13, R14: 5.1k; R_Axial_DIN0207_L6.3mm_D2.5mm_P7.62mm_Horizontal
SW1: RESET; SW_PUSH_6mm
U1: L7805; TO-220-3_Vertical
U2: 68010; DIP-64_W22.86mm_Socket_LongPads
U3: 74HC14; DIP-14_W7.62mm_LongPads
U4: 74LS05; DIP-14_W7.62mm_LongPads
U5: 74LS32; DIP-14_W7.62mm_LongPads
U6: 74LS20; DIP-14_W7.62mm_LongPads
Y1: Crystal; Crystal_HC49-4H_Vertical

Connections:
0SEL: J3.21; also elsewhere on the board
2SEL: J3.25; also elsewhere on the board
3SEL: J3.27; also elsewhere on the board
4SEL: J3.29; also elsewhere on the board
5SEL: J3.31; also elsewhere on the board
6SEL: J3.33; also elsewhere on the board
+5V: C2.1, C3.1, C4.1, C5.1, C6.1, C7.1, C8.1, C9.1, C10.1, C11.1, C12.1, C13.1, C14.1, J3.1, J3.2, R1.1, R2.1, R3.1, R4.1, R5.1, R6.1, R7.1, R8.1, R9.1, R10.1, R12.1, U1.3 (OUT), U2.14 (VCC), U2.49 (VCC), U3.14 (VCC), U4.14 (VCC), U5.14 (VCC), U6.14 (VCC); also elsewhere on the board
A1: J1.40, U2.29 (A1); also elsewhere on the board
A2: J1.37, U2.30 (A2); also elsewhere on the board
A3: J1.38, U2.31 (A3); also elsewhere on the board
A4: J1.35, U2.32 (A4); also elsewhere on the board
A5: J1.36, U2.33 (A5); also elsewhere on the board
A6: J1.33, U2.34 (A6); also elsewhere on the board
A7: J1.34, U2.35 (A7); also elsewhere on the board
A8: J1.31, U2.36 (A8); also elsewhere on the board
A9: J1.32, U2.37 (A9); also elsewhere on the board
A10: J1.29, U2.38 (A10); also elsewhere on the board
A11: J1.30, U2.39 (A11); also elsewhere on the board
A12: J1.27, U2.40 (A12); also elsewhere on the board
A13: J1.28, U2.41 (A13); also elsewhere on the board
A14: J1.25, U2.42 (A14); also elsewhere on the board
A15: J1.26, U2.43 (A15); also elsewhere on the board
A16: J1.23, U2.44 (A16); also elsewhere on the board
A17: J1.24, U2.45 (A17); also elsewhere on the board
A18: J1.21, U2.46 (A18); also elsewhere on the board
A19: J1.22, U2.47 (A19); also elsewhere on the board
A20: J1.19, U2.48 (A20); also elsewhere on the board
A21: J1.20, U2.50 (A21); also elsewhere on the board
A22: J1.17, U2.51 (A22); also elsewhere on the board
A23: J1.18, U2.52 (A23); also elsewhere on the board
AS: J3.4, U2.6 (AS); also elsewhere on the board
BERR: J3.15, R7.2, U2.22 (BERR)
BG: J3.5, U2.11 (BG)
BGACK: J3.7, R4.2, U2.12 (BGACK)
BR: J3.9, R5.2, U2.13 (BR)
CLK: J3.37, R14.1, U2.15 (CLK), U3.6, Y1.2
D0: J1.1, U2.5 (D0); also elsewhere on the board
D1: J1.2, U2.4 (D1); also elsewhere on the board
D2: J1.3, U2.3 (D2); also elsewhere on the board
D3: J1.4, U2.2 (D3); also elsewhere on the board
D4: J1.5, U2.1 (D4); also elsewhere on the board
D5: J1.6, U2.64 (D5); also elsewhere on the board
D6: J1.7, U2.63 (D6); also elsewhere on the board
D7: J1.8, U2.62 (D7); also elsewhere on the board
D8: J1.9, U2.61 (D8); also elsewhere on the board
D9: J1.10, U2.60 (D9); also elsewhere on the board
D10: J1.11, U2.59 (D10); also elsewhere on the board
D11: J1.12, U2.58 (D11); also elsewhere on the board
D12: J1.13, U2.57 (D12); also elsewhere on the board
D13: J1.14, U2.56 (D13); also elsewhere on the board
D14: J1.15, U2.55 (D14); also elsewhere on the board
D15: J1.16, U2.54 (D15); also elsewhere on the board
DTACK: J3.3, R8.2, U2.10 (DTACK); also elsewhere on the board
FC0: J3.16, U2.28 (FC0); also elsewhere on the board
FC1: J3.18, U2.27 (FC1); also elsewhere on the board
FC2: J3.20, U2.26 (FC2); also elsewhere on the board
GND: C1.2, C2.2, C3.2, C4.2, C5.2, C6.2, C7.2, C8.2, C9.2, C10.2, C11.2, C12.2, C13.2, C14.2, C15.2, J2.2, J3.39, J3.40, R11.2, SW1.1, U1.2 (GND), U2.16 (GND), U2.53 (GND), U3.7 (GND), U4.7 (GND), U5.7 (GND), U6.7 (GND); also elsewhere on the board
HALT: D1.2 (A), J3.11, R9.2, U2.17 (HALT), U4.2
IACK: J3.28; also elsewhere on the board
IOSEL: J3.35; also elsewhere on the board
IP4: J3.36; also elsewhere on the board
IP5: J3.38; also elsewhere on the board
IPL0: J3.22, R1.2, U2.25 (IPL0)
IPL1: J3.24, R2.2, U2.24 (IPL1); also elsewhere on the board
IPL2: J3.26, R3.2, U2.23 (IPL2)
LDS: J3.8, U2.8 (LDS); also elsewhere on the board
unnamed: C1.1, J2.1, U1.1 (IN)
unnamed: C15.1, R12.2, SW1.2, U3.13
unnamed: D1.1 (K), R11.1
unnamed: R6.2, U2.21 (VPA)
unnamed: R13.1, R14.2, U3.4, U3.5
unnamed: R13.2, U3.3, Y1.1
unnamed: U3.12, U4.1, U4.3
OP2: J3.32; also elsewhere on the board
OP3: J3.34; also elsewhere on the board
RAMSEL: J3.23; also elsewhere on the board
RD: J3.12, U3.2; also elsewhere on the board
RESET: J3.13, R10.2, U2.18 (RESET), U4.4; also elsewhere on the board
ROMSEL: J3.19; also elsewhere on the board
R~W: J3.10, J3.14, U2.9 (R/W), U3.1; also elsewhere on the board
UDS: J3.6, U2.7 (UDS); also elsewhere on the board

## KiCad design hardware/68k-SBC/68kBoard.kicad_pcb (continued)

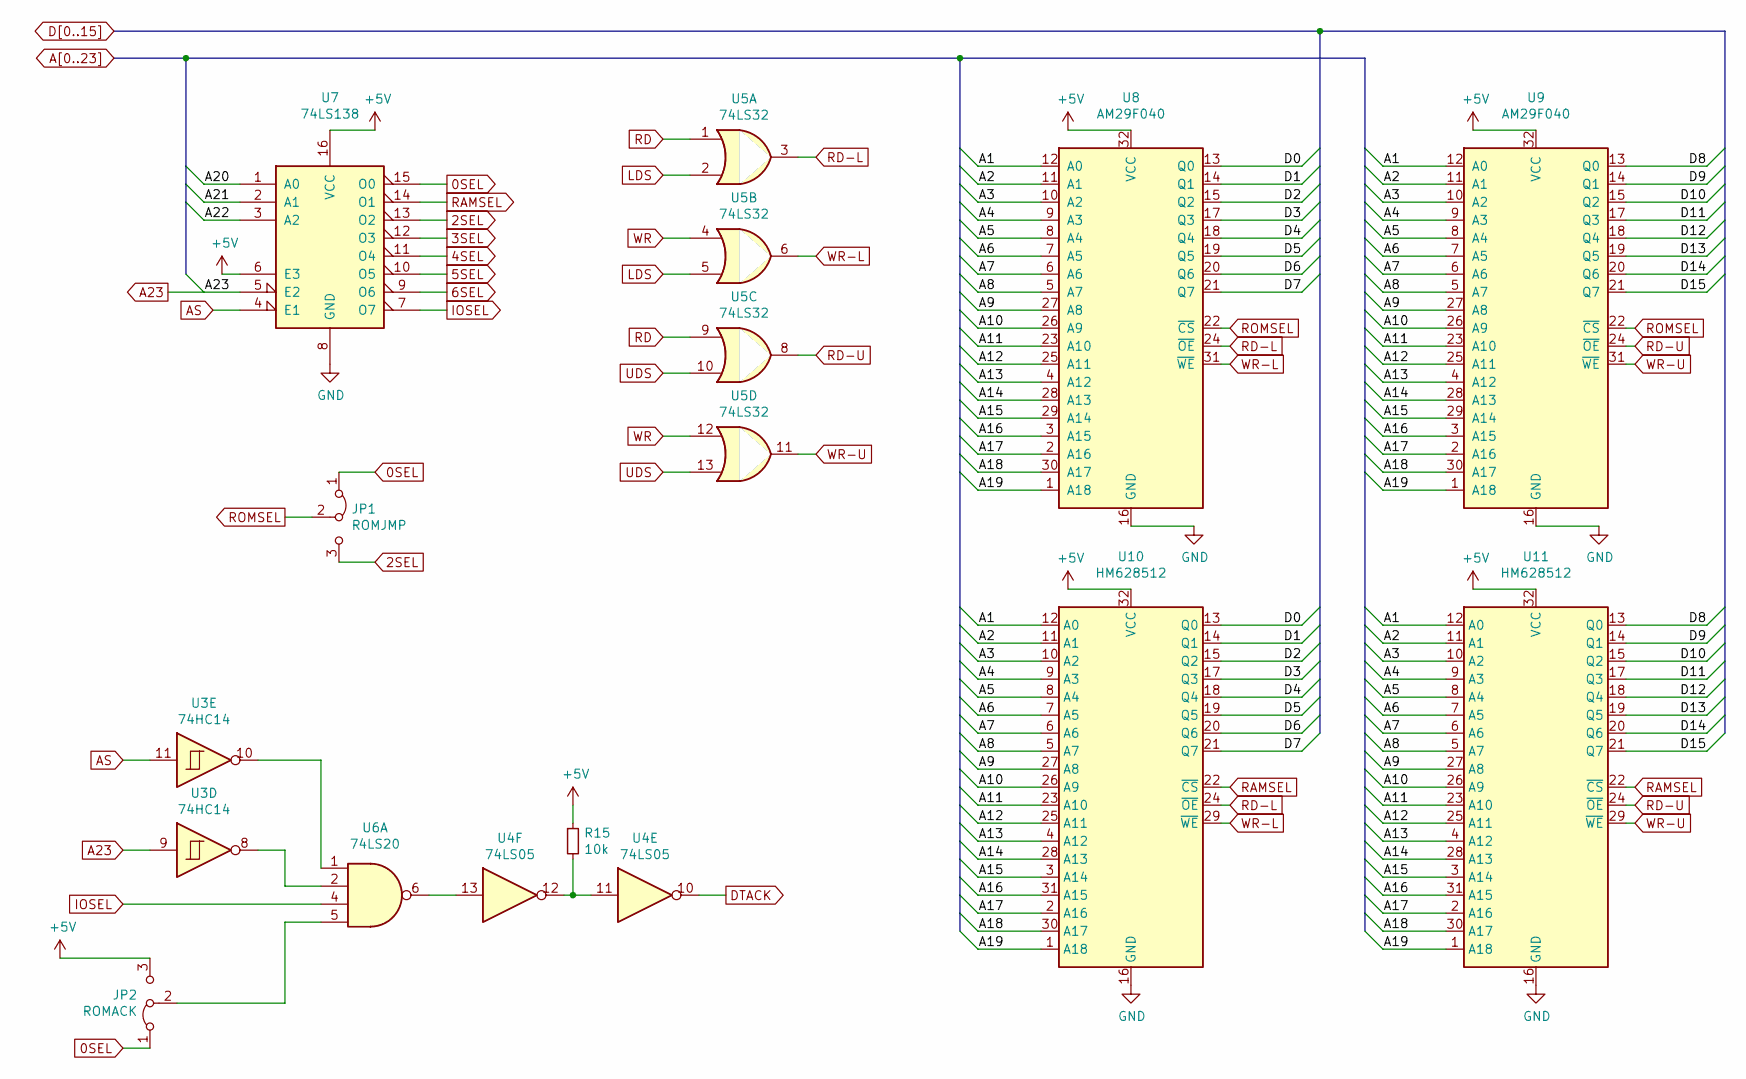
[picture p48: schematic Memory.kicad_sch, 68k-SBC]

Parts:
JP1: ROMJMP; PinHeader_1x03_P2.54mm_Vertical
JP2: ROMACK; PinHeader_1x03_P2.54mm_Vertical
R15: 10k; R_Axial_DIN0207_L6.3mm_D2.5mm_P7.62mm_Horizontal
U3: 74HC14; DIP-14_W7.62mm_LongPads
U4: 74LS05; DIP-14_W7.62mm_LongPads
U5: 74LS32; DIP-14_W7.62mm_LongPads
U6: 74LS20; DIP-14_W7.62mm_LongPads
U7: 74LS138; DIP-16_W7.62mm_LongPads
U8, U9: AM29F040; DIP-32_W15.24mm_Socket_LongPads
U10, U11: HM628512; DIP-32_W15.24mm_Socket_LongPads

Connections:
0SEL: JP1.1 (A), JP2.1 (A), U7.15 (O0); also elsewhere on the board
2SEL: JP1.3 (B), U7.13 (O2); also elsewhere on the board
3SEL: U7.12 (O3); also elsewhere on the board
4SEL: U7.11 (O4); also elsewhere on the board
5SEL: U7.10 (O5); also elsewhere on the board
6SEL: U7.9 (O6); also elsewhere on the board
+5V: JP2.3 (B), R15.1, U7.6 (E3), U7.16 (VCC), U8.32 (VCC), U9.32 (VCC), U10.32 (VCC), U11.32 (VCC); also elsewhere on the board
A1: U8.12 (A0), U9.12 (A0), U10.12 (A0), U11.12 (A0); also elsewhere on the board
A2: U8.11 (A1), U9.11 (A1), U10.11 (A1), U11.11 (A1); also elsewhere on the board
A3: U8.10 (A2), U9.10 (A2), U10.10 (A2), U11.10 (A2); also elsewhere on the board
A4: U8.9 (A3), U9.9 (A3), U10.9 (A3), U11.9 (A3); also elsewhere on the board
A5: U8.8 (A4), U9.8 (A4), U10.8 (A4), U11.8 (A4); also elsewhere on the board
A6: U8.7 (A5), U9.7 (A5), U10.7 (A5), U11.7 (A5); also elsewhere on the board
A7: U8.6 (A6), U9.6 (A6), U10.6 (A6), U11.6 (A6); also elsewhere on the board
A8: U8.5 (A7), U9.5 (A7), U10.5 (A7), U11.5 (A7); also elsewhere on the board
A9: U8.27 (A8), U9.27 (A8), U10.27 (A8), U11.27 (A8); also elsewhere on the board
A10: U8.26 (A9), U9.26 (A9), U10.26 (A9), U11.26 (A9); also elsewhere on the board
A11: U8.23 (A10), U9.23 (A10), U10.23 (A10), U11.23 (A10); also elsewhere on the board
A12: U8.25 (A11), U9.25 (A11), U10.25 (A11), U11.25 (A11); also elsewhere on the board
A13: U8.4 (A12), U9.4 (A12), U10.4 (A12), U11.4 (A12); also elsewhere on the board
A14: U8.28 (A13), U9.28 (A13), U10.28 (A13), U11.28 (A13); also elsewhere on the board
A15: U8.29 (A14), U9.29 (A14), U10.3 (A14), U11.3 (A14); also elsewhere on the board
A16: U8.3 (A15), U9.3 (A15), U10.31 (A15), U11.31 (A15); also elsewhere on the board
A17: U8.2 (A16), U9.2 (A16), U10.2 (A16), U11.2 (A16); also elsewhere on the board
A18: U8.30 (A17), U9.30 (A17), U10.30 (A17), U11.30 (A17); also elsewhere on the board
A19: U8.1 (A18), U9.1 (A18), U10.1 (A18), U11.1 (A18); also elsewhere on the board
A20: U7.1 (A0); also elsewhere on the board
A21: U7.2 (A1); also elsewhere on the board
A22: U7.3 (A2); also elsewhere on the board
A23: U3.9, U7.5 (E2); also elsewhere on the board
AS: U3.11, U7.4 (E1); also elsewhere on the board
D0: U8.13 (Q0), U10.13 (Q0); also elsewhere on the board
D1: U8.14 (Q1), U10.14 (Q1); also elsewhere on the board
D2: U8.15 (Q2), U10.15 (Q2); also elsewhere on the board
D3: U8.17 (Q3), U10.17 (Q3); also elsewhere on the board
D4: U8.18 (Q4), U10.18 (Q4); also elsewhere on the board
D5: U8.19 (Q5), U10.19 (Q5); also elsewhere on the board
D6: U8.20 (Q6), U10.20 (Q6); also elsewhere on the board
D7: U8.21 (Q7), U10.21 (Q7); also elsewhere on the board
D8: U9.13 (Q0), U11.13 (Q0); also elsewhere on the board
D9: U9.14 (Q1), U11.14 (Q1); also elsewhere on the board
D10: U9.15 (Q2), U11.15 (Q2); also elsewhere on the board
D11: U9.17 (Q3), U11.17 (Q3); also elsewhere on the board
D12: U9.18 (Q4), U11.18 (Q4); also elsewhere on the board
D13: U9.19 (Q5), U11.19 (Q5); also elsewhere on the board
D14: U9.20 (Q6), U11.20 (Q6); also elsewhere on the board
D15: U9.21 (Q7), U11.21 (Q7); also elsewhere on the board
DTACK: U4.10; also elsewhere on the board
GND: U7.8 (GND), U8.16 (GND), U9.16 (GND), U10.16 (GND), U11.16 (GND); also elsewhere on the board
IOSEL: U6.4, U7.7 (O7); also elsewhere on the board
LDS: U5.2, U5.5; also elsewhere on the board
unnamed: JP2.2 (C), U6.5
unnamed: R15.2, U4.11, U4.12
unnamed: U3.8, U6.2
unnamed: U3.10, U6.1
unnamed: U4.13, U6.6
RAMSEL: U7.14 (O1), U10.22 (~CS), U11.22 (~CS); also elsewhere on the board
RD: U5.1, U5.9; also elsewhere on the board
RD-L: U5.3, U8.24 (~OE), U10.24 (~OE)
RD-U: U5.8, U9.24 (~OE), U11.24 (~OE)
ROMSEL: JP1.2 (C), U8.22 (~CS), U9.22 (~CS); also elsewhere on the board
R~W: U5.4, U5.12; also elsewhere on the board
UDS: U5.10, U5.13; also elsewhere on the board
WR-L: U5.6, U8.31 (~WE), U10.29 (~WE)
WR-U: U5.11, U9.31 (~WE), U11.29 (~WE)

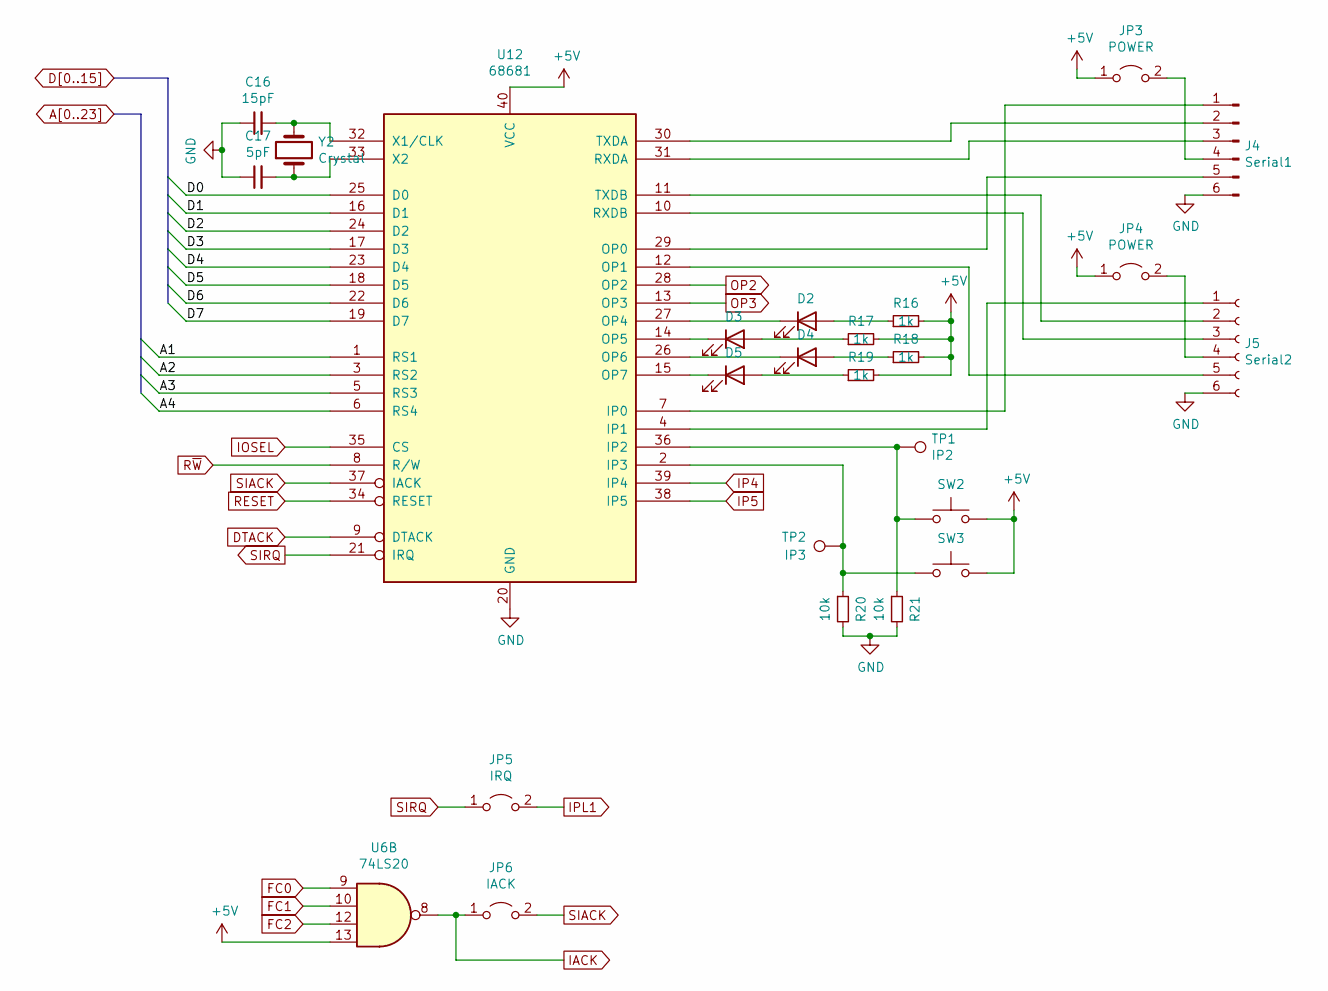
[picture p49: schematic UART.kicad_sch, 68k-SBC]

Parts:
C16: 15pF; C_Disc_D3.0mm_W2.0mm_P2.50mm
C17: 5pF; C_Disc_D3.0mm_W2.0mm_P2.50mm
D2: OP4; LED_D5.0mm
D3: OP5; LED_D5.0mm
D4: OP6; LED_D5.0mm
D5: OP7; LED_D5.0mm
J4: Serial1; PinHeader_1x06_P2.54mm_Horizontal
J5: Serial2; PinHeader_1x06_P2.54mm_Horizontal
JP3, JP4: POWER; PinHeader_1x02_P2.54mm_Vertical
JP5: IRQ; PinHeader_1x02_P2.54mm_Vertical
JP6: IACK; PinHeader_1x02_P2.54mm_Vertical
R16, R17, R18, R19: 1k; R_Axial_DIN0207_L6.3mm_D2.5mm_P7.62mm_Horizontal
R20, R21: 10k; R_Axial_DIN0207_L6.3mm_D2.5mm_P7.62mm_Horizontal
SW2: IP2; SW_PUSH_6mm
SW3: IP3; SW_PUSH_6mm
TP1: IP2; TestPoint_THTPad_2.0x2.0mm_Drill1.0mm
TP2: IP3; TestPoint_THTPad_2.0x2.0mm_Drill1.0mm
U6: 74LS20; DIP-14_W7.62mm_LongPads
U12: 68681; DIP-40_W15.24mm_Socket_LongPads
Y2: Crystal; Crystal_HC49-4H_Vertical

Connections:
+5V: JP3.1 (A), JP4.1 (A), R16.2, R17.2, R18.2, R19.2, SW2.2, SW3.2, U6.13, U12.40 (VCC); also elsewhere on the board
A1: U12.1 (RS1); also elsewhere on the board
A2: U12.3 (RS2); also elsewhere on the board
A3: U12.5 (RS3); also elsewhere on the board
A4: U12.6 (RS4); also elsewhere on the board
D0: U12.25 (D0); also elsewhere on the board
D1: U12.16 (D1); also elsewhere on the board
D2: U12.24 (D2); also elsewhere on the board
D3: U12.17 (D3); also elsewhere on the board
D4: U12.23 (D4); also elsewhere on the board
D5: U12.18 (D5); also elsewhere on the board
D6: U12.22 (D6); also elsewhere on the board
D7: U12.19 (D7); also elsewhere on the board
DTACK: U12.9 (DTACK); also elsewhere on the board
FC0: U6.9; also elsewhere on the board
FC1: U6.10; also elsewhere on the board
FC2: U6.12; also elsewhere on the board
GND: C16.1, C17.1, J4.6, J5.6, R20.2, R21.2, U12.20 (GND); also elsewhere on the board
IACK: JP6.1 (A), U6.8; also elsewhere on the board
IOSEL: U12.35 (CS); also elsewhere on the board
IP4: U12.39 (IP4); also elsewhere on the board
IP5: U12.38 (IP5); also elsewhere on the board
IPL1: JP5.2 (B); also elsewhere on the board
unnamed: C16.2, U12.32 (X1/CLK), Y2.2
unnamed: C17.2, U12.33 (X2), Y2.1
unnamed: D2.1 (K), U12.27 (OP4)
unnamed: D2.2 (A), R16.1
unnamed: D3.1 (K), U12.14 (OP5)
unnamed: D3.2 (A), R17.1
unnamed: D4.1 (K), U12.26 (OP6)
unnamed: D4.2 (A), R18.1
unnamed: D5.1 (K), U12.15 (OP7)
unnamed: D5.2 (A), R19.1
unnamed: J4.1, U12.7 (IP0)
unnamed: J4.2, U12.30 (TXDA)
unnamed: J4.3, U12.31 (RXDA)
unnamed: J4.4, JP3.2 (B)
unnamed: J4.5, U12.29 (OP0)
unnamed: J5.1, U12.4 (IP1)
unnamed: J5.2, U12.11 (TXDB)
unnamed: J5.3, U12.10 (RXDB)
unnamed: J5.4, JP4.2 (B)
unnamed: J5.5, U12.12 (OP1)
unnamed: R20.1, SW3.1, TP2.1, U12.2 (IP3)
unnamed: R21.1, SW2.1, TP1.1, U12.36 (IP2)
OP2: U12.28 (OP2); also elsewhere on the board
OP3: U12.13 (OP3); also elsewhere on the board
RESET: U12.34 (RESET); also elsewhere on the board
R~W: U12.8 (R/W); also elsewhere on the board
SIACK: JP6.2 (B), U12.37 (IACK)
SIRQ: JP5.1 (A), U12.21 (IRQ)

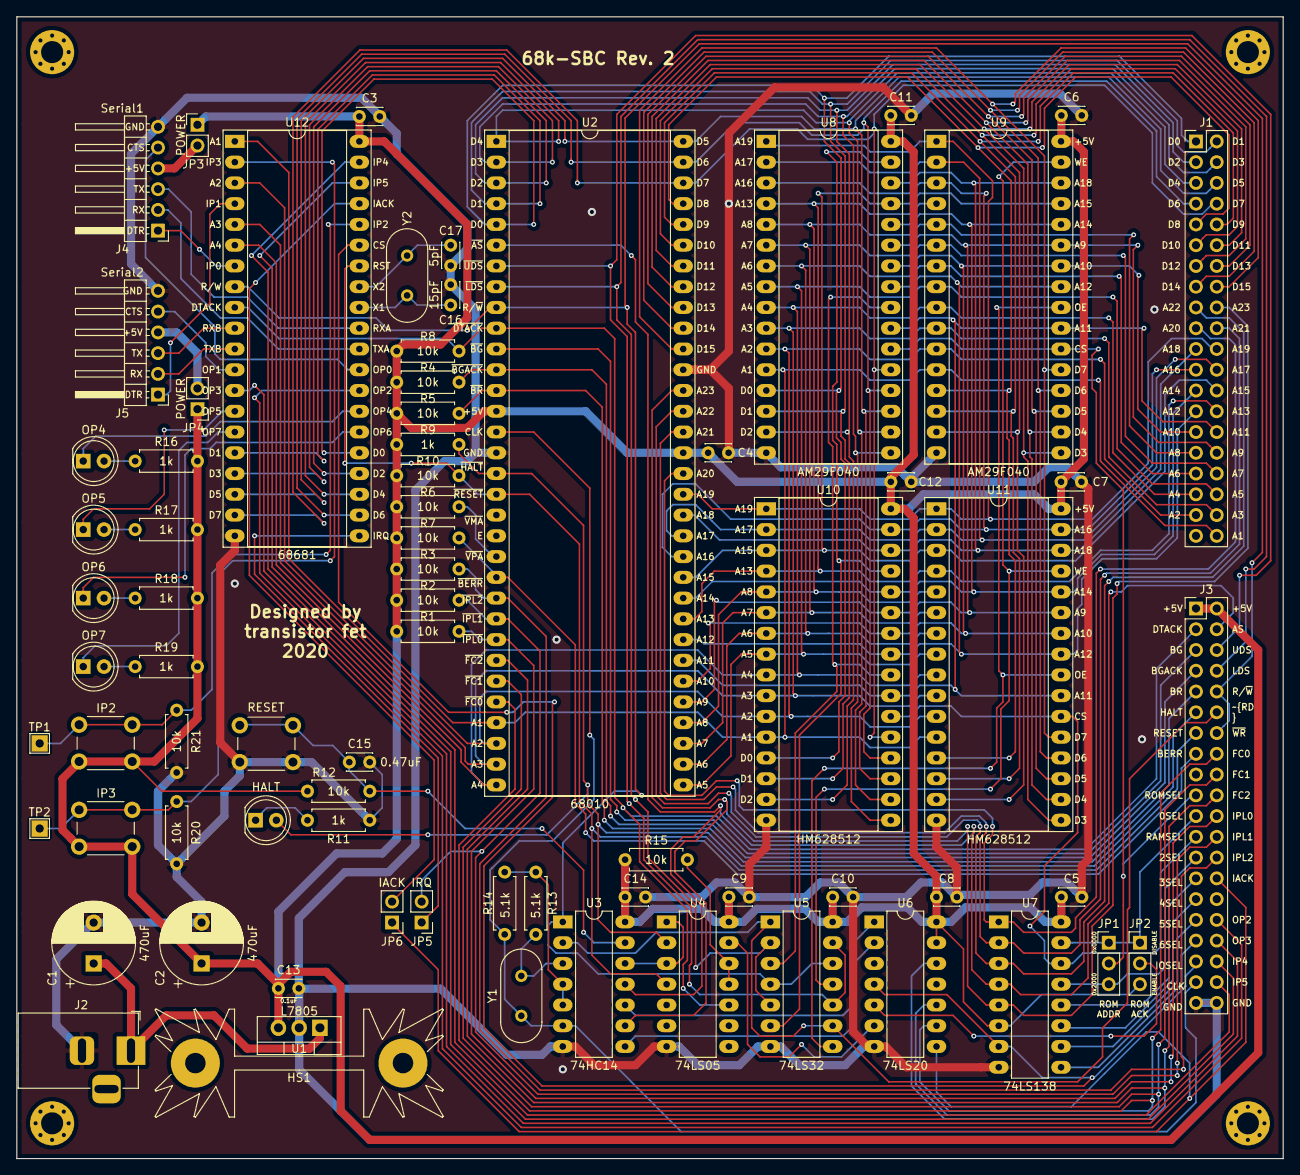
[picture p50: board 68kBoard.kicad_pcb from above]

Board: 2 copper layers, 154.9 x 139.7 mm, 78 parts (0 on the bottom side), 114 nets.

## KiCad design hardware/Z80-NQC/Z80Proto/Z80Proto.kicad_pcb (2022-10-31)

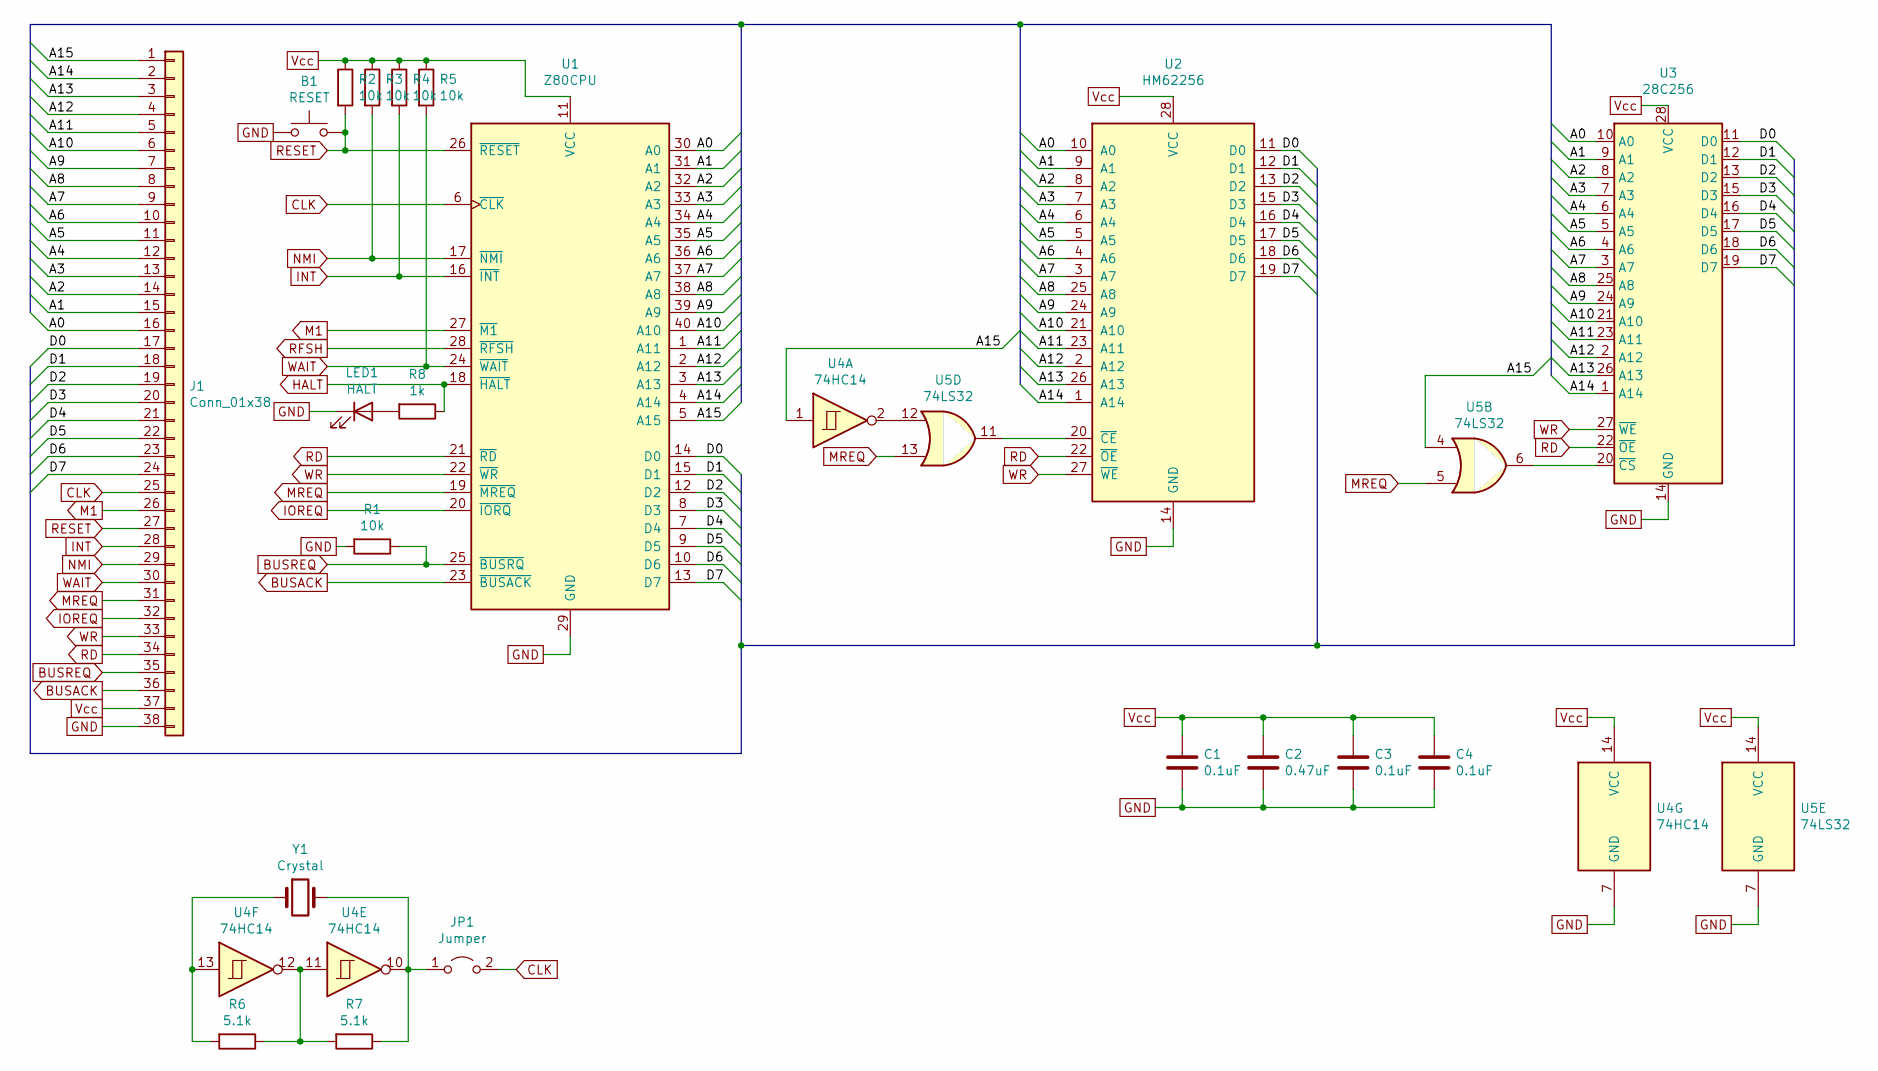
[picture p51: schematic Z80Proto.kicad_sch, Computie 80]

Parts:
B1: RESET; SW_PUSH_6mm
C1, C3, C4: 0.1uF; C_Disc_D3.0mm_W2.0mm_P2.50mm
C2: 0.47uF; C_Disc_D3.0mm_W2.0mm_P2.50mm
J1: Conn_01x38; PinHeader_1x38_P2.54mm_Vertical
JP1: Jumper; PinHeader_1x02_P2.54mm_Vertical
LED1: HALT; LED_D5.0mm
R1, R2, R3, R4, R5: 10k; R_Axial_DIN0207_L6.3mm_D2.5mm_P7.62mm_Horizontal
R6, R7: 5.1k; R_Axial_DIN0207_L6.3mm_D2.5mm_P7.62mm_Horizontal
R8: 1k; R_Axial_DIN0207_L6.3mm_D2.5mm_P7.62mm_Horizontal
U1: Z80CPU; DIP-40_W15.24mm
U2: HM62256; DIP-28_W15.24mm_Socket
U3: 28C256; DIP-28_W15.24mm_Socket
U4: 74HC14; DIP-14_W7.62mm
U5: 74LS32; DIP-14_W7.62mm
Y1: Crystal; Crystal_HC49-4H_Vertical

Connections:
/A0: J1.16, U1.30 (A0), U2.10 (A0), U3.10 (A0); also elsewhere on the board
/A1: J1.15, U1.31 (A1), U2.9 (A1), U3.9 (A1); also elsewhere on the board
/A2: J1.14, U1.32 (A2), U2.8 (A2), U3.8 (A2); also elsewhere on the board
/A3: J1.13, U1.33 (A3), U2.7 (A3), U3.7 (A3); also elsewhere on the board
/A4: J1.12, U1.34 (A4), U2.6 (A4), U3.6 (A4); also elsewhere on the board
/A5: J1.11, U1.35 (A5), U2.5 (A5), U3.5 (A5); also elsewhere on the board
/A6: J1.10, U1.36 (A6), U2.4 (A6), U3.4 (A6); also elsewhere on the board
/A7: J1.9, U1.37 (A7), U2.3 (A7), U3.3 (A7); also elsewhere on the board
/A8: J1.8, U1.38 (A8), U2.25 (A8), U3.25 (A8); also elsewhere on the board
/A9: J1.7, U1.39 (A9), U2.24 (A9), U3.24 (A9); also elsewhere on the board
/A10: J1.6, U1.40 (A10), U2.21 (A10), U3.21 (A10); also elsewhere on the board
/A11: J1.5, U1.1 (A11), U2.23 (A11), U3.23 (A11); also elsewhere on the board
/A12: J1.4, U1.2 (A12), U2.2 (A12), U3.2 (A12); also elsewhere on the board
/A13: J1.3, U1.3 (A13), U2.26 (A13), U3.26 (A13); also elsewhere on the board
/A14: J1.2, U1.4 (A14), U2.1 (A14), U3.1 (A14); also elsewhere on the board
/A15: J1.1, U1.5 (A15), U4.1, U5.4; also elsewhere on the board
/D0: J1.17, U1.14 (D0), U2.11 (D0), U3.11 (D0); also elsewhere on the board
/D1: J1.18, U1.15 (D1), U2.12 (D1), U3.12 (D1); also elsewhere on the board
/D2: J1.19, U1.12 (D2), U2.13 (D2), U3.13 (D2); also elsewhere on the board
/D3: J1.20, U1.8 (D3), U2.15 (D3), U3.15 (D3); also elsewhere on the board
/D4: J1.21, U1.7 (D4), U2.16 (D4), U3.16 (D4); also elsewhere on the board
/D5: J1.22, U1.9 (D5), U2.17 (D5), U3.17 (D5); also elsewhere on the board
/D6: J1.23, U1.10 (D6), U2.18 (D6), U3.18 (D6); also elsewhere on the board
/D7: J1.24, U1.13 (D7), U2.19 (D7), U3.19 (D7); also elsewhere on the board
BUSACK: J1.36, U1.23 (~BUSACK); also elsewhere on the board
BUSREQ: J1.35, R1.1, U1.25 (~BUSRQ); also elsewhere on the board
CLK: J1.25, JP1.2 (B), U1.6 (~CLK); also elsewhere on the board
GND: B1.1, C1.2, C2.2, C3.2, C4.2, J1.38, LED1.1 (K), R1.2, U1.29 (GND), U2.14 (GND), U3.14 (GND), U4.7 (GND), U5.7 (GND); also elsewhere on the board
HALT: R8.1, U1.18 (~HALT)
INT: J1.28, R4.2, U1.16 (~INT); also elsewhere on the board
IOREQ: J1.32, U1.20 (~IORQ); also elsewhere on the board
M1: J1.26, U1.27 (~M1); also elsewhere on the board
MREQ: J1.31, U1.19 (~MREQ), U5.5, U5.13; also elsewhere on the board
NMI: J1.29, R3.2, U1.17 (~NMI); also elsewhere on the board
unnamed: JP1.1 (A), R7.1, U4.10, Y1.2
unnamed: LED1.2 (A), R8.2
unnamed: R6.1, R7.2, U4.11, U4.12
unnamed: R6.2, U4.13, Y1.1
unnamed: U2.20 (~CE), U5.11
unnamed: U3.20 (~CS), U5.6
unnamed: U4.2, U5.12
RD: J1.34, U1.21 (~RD), U2.22 (~OE), U3.22 (~OE); also elsewhere on the board
RESET: B1.2, J1.27, R2.2, U1.26 (~RESET); also elsewhere on the board
RFSH: U1.28 (~RFSH)
Vcc: C1.1, C2.1, C3.1, C4.1, J1.37, R2.1, R3.1, R4.1, R5.1, U1.11 (VCC), U2.28 (VCC), U3.28 (VCC), U4.14 (VCC), U5.14 (VCC); also elsewhere on the board
WAIT: J1.30, R5.2, U1.24 (~WAIT); also elsewhere on the board
WR: J1.33, U1.22 (~WR), U2.27 (~WE), U3.27 (~WE); also elsewhere on the board

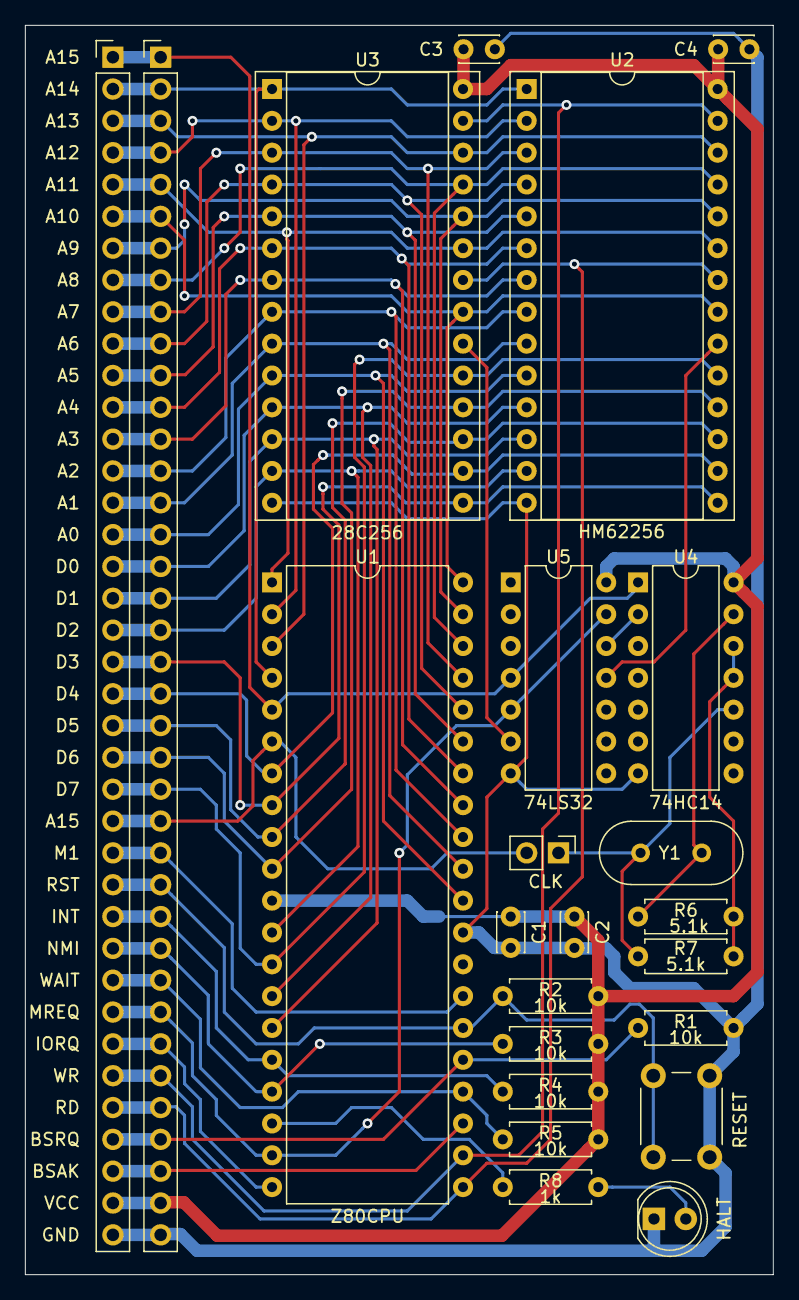
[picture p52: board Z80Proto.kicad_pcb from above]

Board: 2 copper layers, 59.7 x 99.7 mm, 23 parts (0 on the bottom side), 46 nets.

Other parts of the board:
J1#2: Conn_01x38; PinHeader_1x38_P2.54mm_Vertical

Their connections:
/A0: J1#2.16; also elsewhere on the board
/A1: J1#2.15; also elsewhere on the board
/A2: J1#2.14; also elsewhere on the board
/A3: J1#2.13; also elsewhere on the board
/A4: J1#2.12; also elsewhere on the board
/A5: J1#2.11; also elsewhere on the board
/A6: J1#2.10; also elsewhere on the board
/A7: J1#2.9; also elsewhere on the board
/A8: J1#2.8; also elsewhere on the board
/A9: J1#2.7; also elsewhere on the board
/A10: J1#2.6; also elsewhere on the board
/A11: J1#2.5; also elsewhere on the board
/A12: J1#2.4; also elsewhere on the board
/A13: J1#2.3; also elsewhere on the board
/A14: J1#2.2; also elsewhere on the board
/A15: J1#2.1; also elsewhere on the board
/D0: J1#2.17; also elsewhere on the board
/D1: J1#2.18; also elsewhere on the board
/D2: J1#2.19; also elsewhere on the board
/D3: J1#2.20; also elsewhere on the board
/D4: J1#2.21; also elsewhere on the board
/D5: J1#2.22; also elsewhere on the board
/D6: J1#2.23; also elsewhere on the board
/D7: J1#2.24; also elsewhere on the board
BUSACK: J1#2.36; also elsewhere on the board
BUSREQ: J1#2.35; also elsewhere on the board
CLK: J1#2.25; also elsewhere on the board
GND: J1#2.38; also elsewhere on the board
INT: J1#2.28; also elsewhere on the board
IOREQ: J1#2.32; also elsewhere on the board
M1: J1#2.26; also elsewhere on the board
MREQ: J1#2.31; also elsewhere on the board
NMI: J1#2.29; also elsewhere on the board
RD: J1#2.34; also elsewhere on the board
RESET: J1#2.27; also elsewhere on the board
Vcc: J1#2.37; also elsewhere on the board
WAIT: J1#2.30; also elsewhere on the board
WR: J1#2.33; also elsewhere on the board

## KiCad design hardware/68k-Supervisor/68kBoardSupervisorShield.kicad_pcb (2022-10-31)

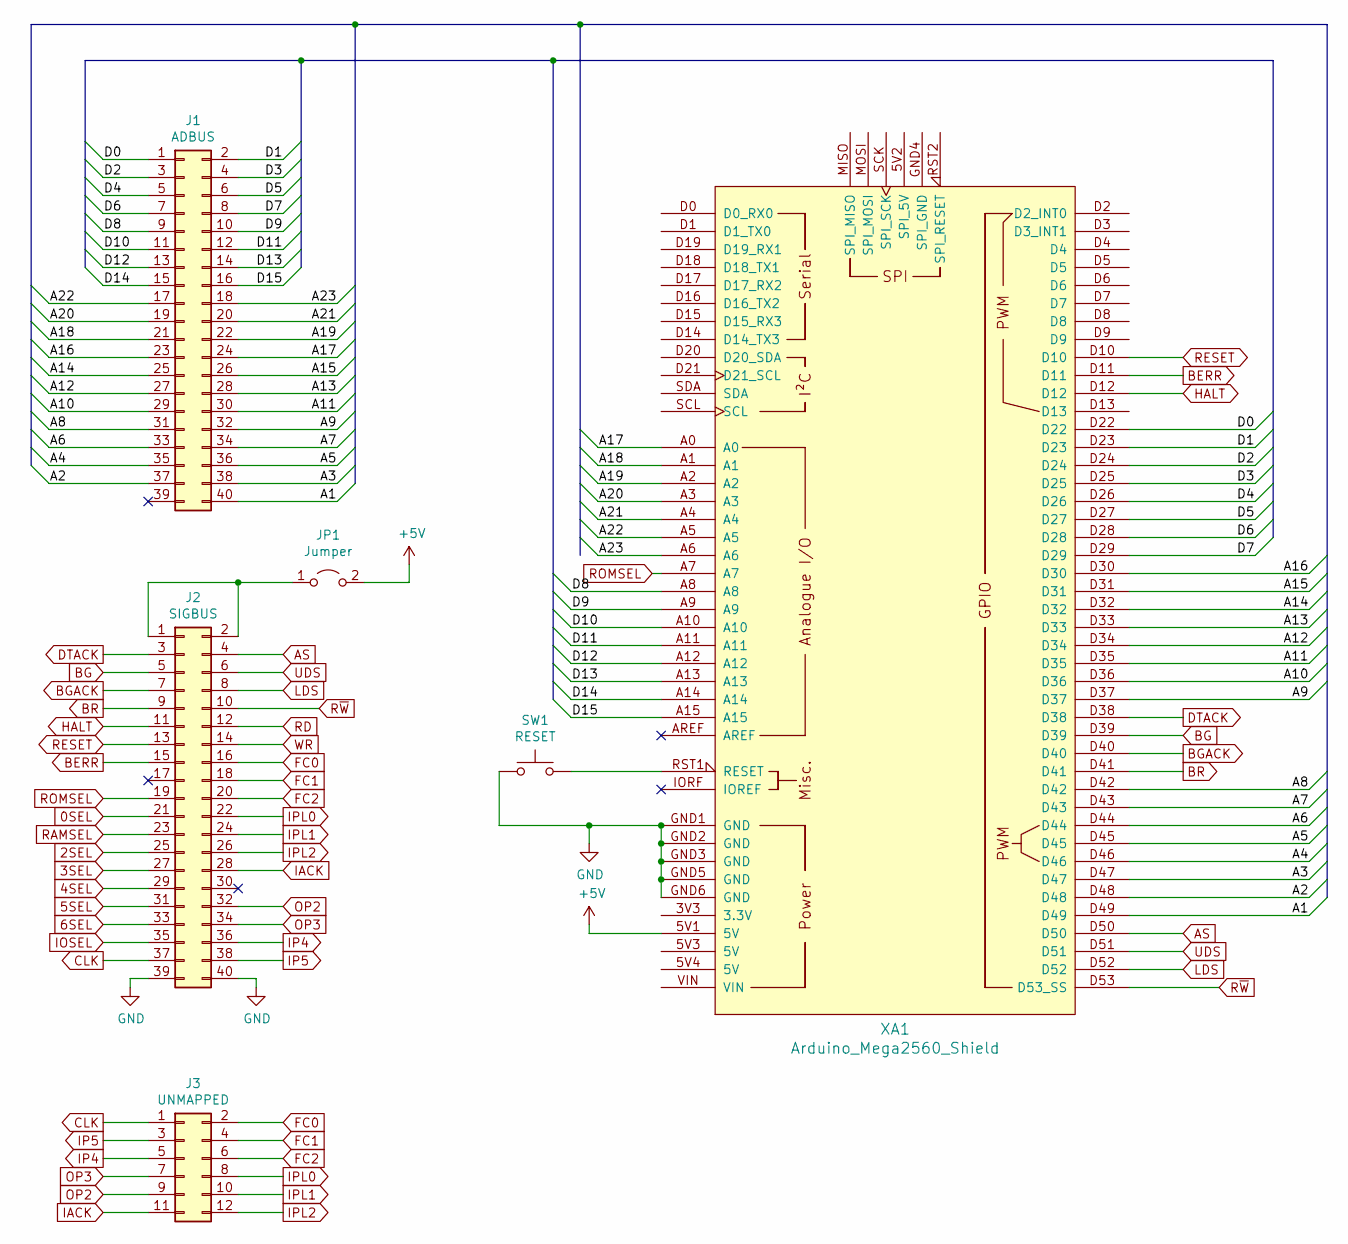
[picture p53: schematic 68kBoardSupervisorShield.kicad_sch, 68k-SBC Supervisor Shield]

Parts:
J1: ADBUS; PinHeader_2x20_P2.54mm_Vertical
J2: SIGBUS; PinHeader_2x20_P2.54mm_Vertical
J3: UNMAPPED; PinHeader_2x06_P2.54mm_Vertical
JP1: Jumper; PinHeader_1x02_P2.54mm_Vertical
SW1: RESET; SW_PUSH_6mm
XA1: Arduino_Mega2560_Shield

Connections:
0SEL: J2.21
2SEL: J2.25
3SEL: J2.27
4SEL: J2.29
5SEL: J2.31
6SEL: J2.33
+5V: JP1.2 (B), XA1.5V1 (5V)
/A1: J1.40, XA1.D49
/A2: J1.37, XA1.D48
/A3: J1.38, XA1.D47
/A4: J1.35, XA1.D46
/A5: J1.36, XA1.D45
/A6: J1.33, XA1.D44
/A7: J1.34, XA1.D43
/A8: J1.31, XA1.D42
/A9: J1.32, XA1.D37
/A10: J1.29, XA1.D36
/A11: J1.30, XA1.D35
/A12: J1.27, XA1.D34
/A13: J1.28, XA1.D33
/A14: J1.25, XA1.D32
/A15: J1.26, XA1.D31
/A16: J1.23, XA1.D30
/A17: J1.24, XA1.A0
/A18: J1.21, XA1.A1
/A19: J1.22, XA1.A2
/A20: J1.19, XA1.A3
/A21: J1.20, XA1.A4
/A22: J1.17, XA1.A5
/A23: J1.18, XA1.A6
/D0: J1.1, XA1.D22
/D1: J1.2, XA1.D23
/D2: J1.3, XA1.D24
/D3: J1.4, XA1.D25
/D4: J1.5, XA1.D26
/D5: J1.6, XA1.D27
/D6: J1.7, XA1.D28
/D7: J1.8, XA1.D29
/D8: J1.9, XA1.A8
/D9: J1.10, XA1.A9
/D10: J1.11, XA1.A10
/D11: J1.12, XA1.A11
/D12: J1.13, XA1.A12
/D13: J1.14, XA1.A13
/D14: J1.15, XA1.A14
/D15: J1.16, XA1.A15
AS: J2.4, XA1.D50
BERR: J2.15, XA1.D11
BG: J2.5, XA1.D39
BGACK: J2.7, XA1.D40
BR: J2.9, XA1.D41
CLK: J2.37, J3.1
DTACK: J2.3, XA1.D38
FC0: J2.16, J3.2
FC1: J2.18, J3.4
FC2: J2.20, J3.6
GND: J2.39, J2.40, SW1.1, XA1.GND1 (GND), XA1.GND2 (GND), XA1.GND3 (GND), XA1.GND5 (GND), XA1.GND6 (GND)
HALT: J2.11, XA1.D12
IACK: J2.28, J3.11
IOSEL: J2.35
IP4: J2.36, J3.5
IP5: J2.38, J3.3
IPL0: J2.22, J3.8
IPL1: J2.24, J3.10
IPL2: J2.26, J3.12
LDS: J2.8, XA1.D52
unnamed: J2.1, J2.2, JP1.1 (A)
unnamed: SW1.2, XA1.RST1 (RESET)
OP2: J2.32, J3.9
OP3: J2.34, J3.7
RAMSEL: J2.23
RD: J2.12
RESET: J2.13, XA1.D10
ROMSEL: J2.19, XA1.A7
R~W: J2.10, XA1.D53 (D53_SS)
UDS: J2.6, XA1.D51
WR: J2.14


Board: 2 copper layers, 89.9 x 53.3 mm, 6 parts (0 on the bottom side), 67 nets.

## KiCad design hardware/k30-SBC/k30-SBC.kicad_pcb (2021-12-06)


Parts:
C1: 0.47uF; C_Disc_D3.0mm_W2.0mm_P2.50mm
D1: RUN; LED_D5.0mm
R1, R2: 1k; R_Axial_DIN0204_L3.6mm_D1.6mm_P5.08mm_Horizontal
R3: 10k; R_Axial_DIN0204_L3.6mm_D1.6mm_P5.08mm_Horizontal
R4, R5: 5.1k; R_Axial_DIN0204_L3.6mm_D1.6mm_P5.08mm_Horizontal
RN1, RN2: 10k; R_Array_SIP9
SW1: RESET; SW_PUSH_6mm
TP1: IPEND; TestPoint_THTPad_2.0x2.0mm_Drill1.0mm
TP2: REFILL; TestPoint_THTPad_2.0x2.0mm_Drill1.0mm
TP3: STATUS; TestPoint_THTPad_2.0x2.0mm_Drill1.0mm
TP7: RMC; TestPoint_THTPad_2.0x2.0mm_Drill1.0mm
U1: MC68030FE; PQFP-132_24x24mm_P0.635mm
U2: 74HC14; TSSOP-14_4.4x5mm_P0.65mm
U3: 74HC05; TSSOP-14_4.4x5mm_P0.65mm
Y1: Crystal; Crystal_HC49-4H_Vertical

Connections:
+5V: R1.2, R3.1, RN1.1 (common), RN2.1 (common), U1.1 (VCC), U1.13 (VCC), U1.32 (VCC), U1.46 (VCC), U1.55 (VCC), U1.68 (VCC), U1.88 (VCC), U1.98 (VCC), U1.99 (VCC), U1.111 (VCC), U1.119 (VCC), U1.123 (VCC); also elsewhere on the board
A0: U1.4 (A0); also elsewhere on the board
A1: U1.5 (A1); also elsewhere on the board
A2: U1.42 (A2); also elsewhere on the board
A3: U1.41 (A3); also elsewhere on the board
A4: U1.39 (A4); also elsewhere on the board
A5: U1.38 (A5); also elsewhere on the board
A6: U1.37 (A6); also elsewhere on the board
A7: U1.36 (A7); also elsewhere on the board
A8: U1.35 (A8); also elsewhere on the board
A9: U1.34 (A9); also elsewhere on the board
A10: U1.31 (A10); also elsewhere on the board
A11: U1.30 (A11); also elsewhere on the board
A12: U1.29 (A12); also elsewhere on the board
A13: U1.28 (A13); also elsewhere on the board
A14: U1.26 (A14); also elsewhere on the board
A15: U1.25 (A15); also elsewhere on the board
A16: U1.24 (A16); also elsewhere on the board
A17: U1.23 (A17); also elsewhere on the board
A18: U1.22 (A18); also elsewhere on the board
A19: U1.21 (A19); also elsewhere on the board
A20: U1.20 (A20); also elsewhere on the board
A21: U1.19 (A21); also elsewhere on the board
A22: U1.17 (A22); also elsewhere on the board
A23: U1.16 (A23); also elsewhere on the board
A24: U1.15 (A24); also elsewhere on the board
A25: U1.14 (A25); also elsewhere on the board
A26: U1.12 (A26); also elsewhere on the board
A27: U1.11 (A27); also elsewhere on the board
A28: U1.10 (A28); also elsewhere on the board
A29: U1.9 (A29); also elsewhere on the board
A30: U1.7 (A30); also elsewhere on the board
A31: U1.6 (A31); also elsewhere on the board
AS: U1.108 (AS); also elsewhere on the board
AVEC: RN1.6 (R5), U1.122 (AVEC); also elsewhere on the board
BERR: RN1.7 (R6), U1.113 (BERR); also elsewhere on the board
BG: U1.131 (BG); also elsewhere on the board
BGACK: RN1.2 (R1), U1.132 (BGACK); also elsewhere on the board
BR: RN1.3 (R2), U1.3 (BR); also elsewhere on the board
CDIS: RN1.9 (R8), U1.54 (CDIS); also elsewhere on the board
CLK: R5.1, U1.121 (CLK), U2.6, Y1.2; also elsewhere on the board
D0: U1.58 (D0); also elsewhere on the board
D1: U1.59 (D1); also elsewhere on the board
D2: U1.61 (D2); also elsewhere on the board
D3: U1.62 (D3); also elsewhere on the board
D4: U1.63 (D4); also elsewhere on the board
D5: U1.64 (D5); also elsewhere on the board
D6: U1.65 (D6); also elsewhere on the board
D7: U1.66 (D7); also elsewhere on the board
D8: U1.69 (D8); also elsewhere on the board
D9: U1.70 (D9); also elsewhere on the board
D10: U1.71 (D10); also elsewhere on the board
D11: U1.72 (D11); also elsewhere on the board
D12: U1.74 (D12); also elsewhere on the board
D13: U1.75 (D13); also elsewhere on the board
D14: U1.76 (D14); also elsewhere on the board
D15: U1.77 (D15); also elsewhere on the board
D16: U1.79 (D16); also elsewhere on the board
D17: U1.80 (D17); also elsewhere on the board
D18: U1.81 (D18); also elsewhere on the board
D19: U1.82 (D19); also elsewhere on the board
D20: U1.84 (D20); also elsewhere on the board
D21: U1.85 (D21); also elsewhere on the board
D22: U1.86 (D22); also elsewhere on the board
D23: U1.87 (D23); also elsewhere on the board
D24: U1.89 (D24); also elsewhere on the board
D25: U1.90 (D25); also elsewhere on the board
D26: U1.91 (D26); also elsewhere on the board
D27: U1.92 (D27); also elsewhere on the board
D28: U1.94 (D28); also elsewhere on the board
D29: U1.95 (D29); also elsewhere on the board
D30: U1.96 (D30); also elsewhere on the board
D31: U1.97 (D31); also elsewhere on the board
DS: U1.107 (DS); also elsewhere on the board
DSACK0: RN2.5 (R4), U1.118 (DSACK0); also elsewhere on the board
DSACK1: RN2.6 (R5), U1.115 (DSACK1); also elsewhere on the board
DSACK-EXT: RN1.4 (R3); also elsewhere on the board
FC0: U1.127 (FC0); also elsewhere on the board
FC1: U1.125 (FC1); also elsewhere on the board
FC2: U1.124 (FC2); also elsewhere on the board
GND: C1.2, R2.1, SW1.1, U1.2 (GND), U1.8 (GND), U1.18 (GND), U1.27 (GND), U1.40 (GND), U1.43 (GND), U1.49 (GND), U1.50 (GND), U1.60 (GND), U1.73 (GND), U1.78 (GND), U1.83 (GND), U1.93 (GND), U1.106 (GND), U1.116 (GND), U1.117 (GND), U1.120 (GND), U1.126 (GND); also elsewhere on the board
HALT: D1.2 (A), R1.1, U1.112 (HALT), U3.2; also elsewhere on the board
IPL0: RN2.2 (R1), U1.53 (IPL0); also elsewhere on the board
IPL1: RN2.3 (R2), U1.52 (IPL1); also elsewhere on the board
IPL2: RN2.4 (R3), U1.51 (IPL2); also elsewhere on the board
MMUDIS: RN1.8 (R7), U1.48 (MMUDIS); also elsewhere on the board
unnamed: C1.1, R3.2, SW1.2, U2.13
unnamed: D1.1 (K), R2.2
unnamed: R4.1, R5.2, U2.4, U2.5
unnamed: R4.2, U2.3, Y1.1
unnamed: RN2.7 (R6), U1.114 (STERM)
unnamed: RN2.8 (R7), U1.110 (CBACK)
unnamed: RN2.9 (R8), U1.105 (CIIN)
unnamed: TP1.1, U1.45 (IPEND)
unnamed: TP2.1, U1.56 (REFILL)
unnamed: TP3.1, U1.57 (STATUS)
unnamed: TP7.1, U1.128 (RMC)
unnamed: U2.12, U3.1, U3.3
RD: U2.2; also elsewhere on the board
SIZ0: U1.103 (SIZ0); also elsewhere on the board
SIZ1: U1.102 (SIZ1); also elsewhere on the board
WR: U1.100 (R/W), U2.1; also elsewhere on the board


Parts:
JP1: ROMJMP; PinHeader_1x03_P2.54mm_Vertical
JP6: ENABLE; SolderJumper-2_P1.3mm_Open_RoundedPad1.0x1.5mm
JP7: PULLUP; SolderJumper-2_P1.3mm_Bridged_RoundedPad1.0x1.5mm
R12: 10k; R_Axial_DIN0204_L3.6mm_D1.6mm_P5.08mm_Horizontal
SW2: SW_DIP_x06; DIP-12_W7.62mm_LongPads
TP4: DSACK-EXT; TestPoint_THTPad_2.0x2.0mm_Drill1.0mm
TP8: DSACK-SEL; TestPoint_THTPad_2.0x2.0mm_Drill1.0mm
U2: 74HC14; TSSOP-14_4.4x5mm_P0.65mm
U3: 74HC05; TSSOP-14_4.4x5mm_P0.65mm
U4: 74HC139; TSSOP-16_4.4x5mm_P0.65mm
U5: 4072; TSSOP-14_4.4x5mm_P0.65mm
U6: 74HC20; TSSOP-14_4.4x5mm_P0.65mm
U7: 74HC32; TSSOP-14_4.4x5mm_P0.65mm
U8: 74HC08; TSSOP-14_4.4x5mm_P0.65mm
U9, U10: 74HC253; SSOP-16_5.3x6.2mm_P0.65mm
U11: 74HC138; TSSOP-16_4.4x5mm_P0.65mm
U12: 74HC393; TSSOP-14_4.4x5mm_P0.65mm
U17: 74LVC1G32; SOT-353_SC-70-5_Handsoldering

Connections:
0SEL: JP1.3 (B), U11.15 (O0); also elsewhere on the board
3SEL: JP1.1 (A), U11.12 (O3); also elsewhere on the board
4SEL: U11.11 (O4); also elsewhere on the board
5SEL: U11.10 (O5); also elsewhere on the board
6SEL: TP8.1, U11.9 (O6), U12.2 (MR), U17.2; also elsewhere on the board
+5V: R12.1, U9.3 (I3a), U9.4 (I2a), U9.5 (I1a), U9.12 (I2b), U9.13 (I3b), U9.16 (VCC), U10.3 (I3a), U10.16 (VCC), U11.6 (E3), U11.16 (VCC), U17.5 (VCC); also elsewhere on the board
A0: U9.14 (A0), U10.14 (A0); also elsewhere on the board
A1: U9.2 (A1), U10.2 (A1); also elsewhere on the board
A16: U6.13; also elsewhere on the board
A20: U11.1 (A0); also elsewhere on the board
A21: U11.2 (A1); also elsewhere on the board
A22: U11.3 (A2); also elsewhere on the board
A23: U7.5; also elsewhere on the board
A24: U5.12; also elsewhere on the board
A25: U5.11; also elsewhere on the board
A26: U5.10; also elsewhere on the board
A27: U5.9; also elsewhere on the board
A28: U5.5; also elsewhere on the board
A29: U5.4; also elsewhere on the board
A30: U5.3; also elsewhere on the board
A31: U5.2; also elsewhere on the board
AS: U11.4 (E1), U12.12 (MR); also elsewhere on the board
BERR: SW2.9; also elsewhere on the board
CDIS: SW2.5; also elsewhere on the board
CLK: U12.1 (CP), U12.13 (CP); also elsewhere on the board
DS: U4.1 (E); also elsewhere on the board
DSACK0: U3.8; also elsewhere on the board
DSACK1: U3.10; also elsewhere on the board
DSACK-EXT: JP6.2 (B), JP7.1 (A), TP4.1, U6.5; also elsewhere on the board
FC0: U6.9; also elsewhere on the board
FC1: U6.10; also elsewhere on the board
FC2: U6.12; also elsewhere on the board
GND: SW2.7, SW2.8, U9.1 (OEa), U9.8 (GND), U9.15 (OEb), U10.1 (OEa), U10.8 (GND), U10.15 (OEb), U11.8 (GND), U17.3 (GND); also elsewhere on the board
IACK: U6.8; also elsewhere on the board
IOSEL: U11.7 (O7); also elsewhere on the board
MMUDIS: SW2.6; also elsewhere on the board
unnamed: JP6.1 (A), U3.12
unnamed: JP7.2 (B), R12.2
unnamed: SW2.1, U12.4 (Q1)
unnamed: SW2.2, U12.5 (Q2)
unnamed: SW2.3, U12.6 (Q3)
unnamed: SW2.4, U3.6
unnamed: U2.8, U3.11
unnamed: U3.9, U6.6
unnamed: U4.5 (O1), U8.1
unnamed: U4.6 (O2), U8.4
unnamed: U4.7 (O3), U8.9
unnamed: U5.1, U7.1
unnamed: U5.13, U7.2
unnamed: U7.3, U7.4
unnamed: U4.4 (O0), U8.10, U10.10 (I0b)
unnamed: U8.5, U8.8, U10.6 (I0a), U10.11 (I1b)
unnamed: U8.2, U8.6, U9.10 (I0b), U10.5 (I1a), U10.12 (I2b)
unnamed: U8.3, U9.6 (I0a), U9.11 (I1b), U10.4 (I2a), U10.13 (I3b)
unnamed: U7.6, U11.5 (E2)
unnamed: U8.13, U11.13 (O2)
unnamed: U8.12, U11.14 (O1)
unnamed: U3.5, U12.8 (Q3)
unnamed: U2.10, U17.1
RAMSEL: U2.9, U6.1, U8.11; also elsewhere on the board
ROMSEL: JP1.2 (C), U6.2; also elsewhere on the board
SIZ0: U4.2 (A0); also elsewhere on the board
SIZ1: U4.3 (A1); also elsewhere on the board
~DS0: U10.9 (Zb); also elsewhere on the board
~DS1: U10.7 (Za); also elsewhere on the board
~DS2: U9.9 (Zb); also elsewhere on the board
~DS3: U9.7 (Za); also elsewhere on the board

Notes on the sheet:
DSACK ASSERTION LOGIC
DSACK GENERATOR FOR EXTERNAL IO
BERR GENERATOR
COMPACT FLASH DSACK GENERATOR LOGIC
ROM ADDRESS SELECTION


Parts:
C2: 15pF; C_Disc_D3.0mm_W2.0mm_P2.50mm
C3: 5pF; C_Disc_D3.0mm_W2.0mm_P2.50mm
D2: OP5; LED_D5.0mm
D3: OP7; LED_D5.0mm
D4: OP4; LED_D5.0mm
D5: OP6; LED_D5.0mm
J1: CompactFlash; CF-Card_3M_N7E50-Q516RB-40
J2: Serial1; PinHeader_1x06_P2.54mm_Vertical
J3: Serial2; PinHeader_1x06_P2.54mm_Vertical
JP2: IRQ; PinHeader_1x02_P2.54mm_Vertical
JP3: IACK; PinHeader_1x02_P2.54mm_Vertical
JP4, JP5: POWER; PinHeader_1x02_P2.54mm_Vertical
R6, R9: 10k; R_Axial_DIN0204_L3.6mm_D1.6mm_P5.08mm_Horizontal
R7, R8, R10, R11: 1k; R_Axial_DIN0204_L3.6mm_D1.6mm_P5.08mm_Horizontal
SW3: IP2; SW_PUSH_6mm
SW4: IP3; SW_PUSH_6mm
TP5: IP3; TestPoint_THTPad_2.0x2.0mm_Drill1.0mm
TP6: IP2; TestPoint_THTPad_2.0x2.0mm_Drill1.0mm
U7: 74HC32; TSSOP-14_4.4x5mm_P0.65mm
U13: MC68681; PLCC-44_THT-Socket
Y2: Crystal; Crystal_HC49-4H_Vertical

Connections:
6SEL: U7.9, U7.12; also elsewhere on the board
+5V: J1.13, J1.36, J1.38, J1.44, JP4.1 (A), JP5.1 (A), R7.2, R8.2, R10.2, R11.2, SW3.2, SW4.2, U13.44 (VCC); also elsewhere on the board
A1: J1.20, U13.2 (RS1); also elsewhere on the board
A2: J1.19, U13.4 (RS2); also elsewhere on the board
A3: J1.18, U13.6 (RS3); also elsewhere on the board
A4: J1.7, U13.7 (RS4); also elsewhere on the board
A5: J1.32; also elsewhere on the board
D24: J1.21, U13.28 (D0); also elsewhere on the board
D25: J1.22, U13.18 (D1); also elsewhere on the board
D26: J1.23, U13.27 (D2); also elsewhere on the board
D27: J1.2, U13.19 (D3); also elsewhere on the board
D28: J1.3, U13.26 (D4); also elsewhere on the board
D29: J1.4, U13.20 (D5); also elsewhere on the board
D30: J1.5, U13.25 (D6); also elsewhere on the board
D31: J1.6, U13.21 (D7); also elsewhere on the board
DSACK0: U13.10 (DTACK); also elsewhere on the board
GND: C2.1, C3.1, J1.1, J1.8, J1.9, J1.10, J1.11, J1.12, J1.14, J1.15, J1.16, J1.17, J1.39, J1.50, J2.6, J3.6, R6.2, R9.2, U13.22 (GND); also elsewhere on the board
IACK: JP3.1 (A); also elsewhere on the board
IORD: J1.34, U7.8
IOSEL: U13.39 (CS); also elsewhere on the board
IOWR: J1.35, U7.11
IP4: U13.43 (IP4); also elsewhere on the board
IP5: U13.42 (IP5); also elsewhere on the board
IPL1: JP2.1 (A); also elsewhere on the board
unnamed: C2.2, U13.36 (X1/CLK), Y2.2
unnamed: C3.2, U13.37 (X2), Y2.1
unnamed: D2.1 (K), U13.16 (OP5)
unnamed: D2.2 (A), R7.1
unnamed: D3.1 (K), U13.17 (OP7)
unnamed: D3.2 (A), R8.1
unnamed: D4.1 (K), U13.30 (OP4)
unnamed: D4.2 (A), R10.1
unnamed: D5.1 (K), U13.29 (OP6)
unnamed: D5.2 (A), R11.1
unnamed: J2.1, U13.8 (IP0)
unnamed: J2.2, U13.33 (TXDA)
unnamed: J2.3, U13.35 (RXDA)
unnamed: J2.4, JP4.2 (B)
unnamed: J2.5, U13.32 (OP0)
unnamed: J3.1, U13.5 (IP1)
unnamed: J3.2, U13.13 (TXDB)
unnamed: J3.3, U13.11 (RXDB)
unnamed: J3.4, JP5.2 (B)
unnamed: J3.5, U13.14 (OP1)
unnamed: R6.1, SW4.1, TP5.1, U13.3 (IP3)
unnamed: R9.1, SW3.1, TP6.1, U13.40 (IP2)
OP2: U13.31 (OP2); also elsewhere on the board
OP3: U13.15 (OP3); also elsewhere on the board
RD: U7.10; also elsewhere on the board
SIACK: JP3.2 (B), U13.41 (IACK)
SIRQ: JP2.2 (B), U13.24 (IRQ)
WR: U7.13, U13.9 (R/W); also elsewhere on the board


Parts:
U14, U15: AS6C8016; TSOP-II-44_10.16x18.41mm_P0.8mm
U16: AM29F040; PLCC-32_THT-Socket

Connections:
+5V: U14.11 (VCC), U14.33 (VCC), U15.11 (VCC), U15.33 (VCC), U16.32 (VCC); also elsewhere on the board
A0: U16.12 (A0); also elsewhere on the board
A1: U16.11 (A1); also elsewhere on the board
A2: U14.5 (A0), U15.5 (A0), U16.10 (A2); also elsewhere on the board
A3: U14.4 (A1), U15.4 (A1), U16.9 (A3); also elsewhere on the board
A4: U14.3 (A2), U15.3 (A2), U16.8 (A4); also elsewhere on the board
A5: U14.2 (A3), U15.2 (A3), U16.7 (A5); also elsewhere on the board
A6: U14.1 (A4), U15.1 (A4), U16.6 (A6); also elsewhere on the board
A7: U14.44 (A5), U15.44 (A5), U16.5 (A7); also elsewhere on the board
A8: U14.43 (A6), U15.43 (A6), U16.27 (A8); also elsewhere on the board
A9: U14.42 (A7), U15.42 (A7), U16.26 (A9); also elsewhere on the board
A10: U14.28 (A8), U15.28 (A8), U16.23 (A10); also elsewhere on the board
A11: U14.27 (A9), U15.27 (A9), U16.25 (A11); also elsewhere on the board
A12: U14.26 (A10), U15.26 (A10), U16.4 (A12); also elsewhere on the board
A13: U14.25 (A11), U15.25 (A11), U16.28 (A13); also elsewhere on the board
A14: U14.24 (A12), U15.24 (A12), U16.29 (A14); also elsewhere on the board
A15: U14.23 (A13), U15.23 (A13), U16.3 (A15); also elsewhere on the board
A16: U14.22 (A14), U15.22 (A14), U16.2 (A16); also elsewhere on the board
A17: U14.21 (A15), U15.21 (A15), U16.30 (A17); also elsewhere on the board
A18: U14.20 (A16), U15.20 (A16), U16.1 (A18); also elsewhere on the board
A19: U14.19 (A17), U15.19 (A17); also elsewhere on the board
A20: U14.18 (A18), U15.18 (A18); also elsewhere on the board
D0: U15.7 (Q0); also elsewhere on the board
D1: U15.8 (Q1); also elsewhere on the board
D2: U15.9 (Q2); also elsewhere on the board
D3: U15.10 (Q3); also elsewhere on the board
D4: U15.13 (Q4); also elsewhere on the board
D5: U15.14 (Q5); also elsewhere on the board
D6: U15.15 (Q6); also elsewhere on the board
D7: U15.16 (Q7); also elsewhere on the board
D8: U15.29 (Q8); also elsewhere on the board
D9: U15.30 (Q9); also elsewhere on the board
D10: U15.31 (Q10); also elsewhere on the board
D11: U15.32 (Q11); also elsewhere on the board
D12: U15.35 (Q12); also elsewhere on the board
D13: U15.36 (Q13); also elsewhere on the board
D14: U15.37 (Q14); also elsewhere on the board
D15: U15.38 (Q15); also elsewhere on the board
D16: U14.7 (Q0); also elsewhere on the board
D17: U14.8 (Q1); also elsewhere on the board
D18: U14.9 (Q2); also elsewhere on the board
D19: U14.10 (Q3); also elsewhere on the board
D20: U14.13 (Q4); also elsewhere on the board
D21: U14.14 (Q5); also elsewhere on the board
D22: U14.15 (Q6); also elsewhere on the board
D23: U14.16 (Q7); also elsewhere on the board
D24: U14.29 (Q8), U16.13 (Q0); also elsewhere on the board
D25: U14.30 (Q9), U16.14 (Q1); also elsewhere on the board
D26: U14.31 (Q10), U16.15 (Q2); also elsewhere on the board
D27: U14.32 (Q11), U16.17 (Q3); also elsewhere on the board
D28: U14.35 (Q12), U16.18 (Q4); also elsewhere on the board
D29: U14.36 (Q13), U16.19 (Q5); also elsewhere on the board
D30: U14.37 (Q14), U16.20 (Q6); also elsewhere on the board
D31: U14.38 (Q15), U16.21 (Q7); also elsewhere on the board
GND: U14.12 (VSS), U14.34 (VSS), U15.12 (VSS), U15.34 (VSS), U16.16 (GND); also elsewhere on the board
RAMSEL: U14.6 (~CE), U15.6 (~CE); also elsewhere on the board
RD: U14.41 (~OE), U15.41 (~OE), U16.24 (~OE); also elsewhere on the board
ROMSEL: U16.22 (~CS); also elsewhere on the board
WR: U14.17 (~WE), U15.17 (~WE), U16.31 (~WE); also elsewhere on the board
~DS0: U15.39 (~LB); also elsewhere on the board
~DS1: U15.40 (~UB); also elsewhere on the board
~DS2: U14.39 (~LB); also elsewhere on the board
~DS3: U14.40 (~UB); also elsewhere on the board

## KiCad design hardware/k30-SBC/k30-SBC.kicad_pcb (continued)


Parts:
C4, C5, C6, C7, C9, C10, C11, C12, C13, C14, C15, C16, C17, C18, C19, C20: 0.1uF; C_Disc_D3.0mm_W2.0mm_P2.50mm
C8: 470uF; CP_Radial_D8.0mm_P5.00mm
J4: ADBUS-EXP; PinHeader_2x15_P2.54mm_Vertical
J5: ADBUS; PinHeader_2x20_P2.54mm_Vertical
J6: SIGBUS; PinHeader_2x20_P2.54mm_Vertical
J7, J8, J9: POWER; PinHeader_1x02_P2.54mm_Vertical
U2: 74HC14; TSSOP-14_4.4x5mm_P0.65mm
U3: 74HC05; TSSOP-14_4.4x5mm_P0.65mm
U4: 74HC139; TSSOP-16_4.4x5mm_P0.65mm
U5: 4072; TSSOP-14_4.4x5mm_P0.65mm
U6: 74HC20; TSSOP-14_4.4x5mm_P0.65mm
U7: 74HC32; TSSOP-14_4.4x5mm_P0.65mm
U8: 74HC08; TSSOP-14_4.4x5mm_P0.65mm
U12: 74HC393; TSSOP-14_4.4x5mm_P0.65mm

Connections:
0SEL: J6.21; also elsewhere on the board
3SEL: J6.27; also elsewhere on the board
4SEL: J6.29; also elsewhere on the board
5SEL: J6.31; also elsewhere on the board
6SEL: J6.33; also elsewhere on the board
+5V: C4.1, C5.1, C6.1, C7.1, C8.1, C9.1, C10.1, C11.1, C12.1, C13.1, C14.1, C15.1, C16.1, C17.1, C18.1, C19.1, C20.1, J6.1, J6.2, J7.1, J8.1, J9.1, U2.14 (VCC), U3.14 (VCC), U4.16 (VCC), U5.14 (VDD), U6.14 (VCC), U7.14 (VCC), U8.14 (VCC), U12.14 (VCC); also elsewhere on the board
A0: J5.39; also elsewhere on the board
A1: J5.40; also elsewhere on the board
A2: J5.37; also elsewhere on the board
A3: J5.38; also elsewhere on the board
A4: J5.35; also elsewhere on the board
A5: J5.36; also elsewhere on the board
A6: J5.33; also elsewhere on the board
A7: J5.34; also elsewhere on the board
A8: J5.31; also elsewhere on the board
A9: J5.32; also elsewhere on the board
A10: J5.29; also elsewhere on the board
A11: J5.30; also elsewhere on the board
A12: J5.27; also elsewhere on the board
A13: J5.28; also elsewhere on the board
A14: J5.25; also elsewhere on the board
A15: J5.26; also elsewhere on the board
A16: J5.23; also elsewhere on the board
A17: J5.24; also elsewhere on the board
A18: J5.21; also elsewhere on the board
A19: J5.22; also elsewhere on the board
A20: J5.19; also elsewhere on the board
A21: J5.20; also elsewhere on the board
A22: J5.17; also elsewhere on the board
A23: J5.18; also elsewhere on the board
A24: J4.24; also elsewhere on the board
A25: J4.23; also elsewhere on the board
A26: J4.22; also elsewhere on the board
A27: J4.21; also elsewhere on the board
A28: J4.20; also elsewhere on the board
A29: J4.19; also elsewhere on the board
A30: J4.18; also elsewhere on the board
A31: J4.17; also elsewhere on the board
AS: J6.4; also elsewhere on the board
AVEC: J6.30; also elsewhere on the board
BERR: J6.15; also elsewhere on the board
BG: J6.5; also elsewhere on the board
BGACK: J6.7; also elsewhere on the board
BR: J6.9; also elsewhere on the board
CLK: J6.37; also elsewhere on the board
D0: J4.1; also elsewhere on the board
D1: J4.2; also elsewhere on the board
D2: J4.3; also elsewhere on the board
D3: J4.4; also elsewhere on the board
D4: J4.5; also elsewhere on the board
D5: J4.6; also elsewhere on the board
D6: J4.7; also elsewhere on the board
D7: J4.8; also elsewhere on the board
D8: J4.9; also elsewhere on the board
D9: J4.10; also elsewhere on the board
D10: J4.11; also elsewhere on the board
D11: J4.12; also elsewhere on the board
D12: J4.13; also elsewhere on the board
D13: J4.14; also elsewhere on the board
D14: J4.15; also elsewhere on the board
D15: J4.16; also elsewhere on the board
D16: J5.1; also elsewhere on the board
D17: J5.2; also elsewhere on the board
D18: J5.3; also elsewhere on the board
D19: J5.4; also elsewhere on the board
D20: J5.5; also elsewhere on the board
D21: J5.6; also elsewhere on the board
D22: J5.7; also elsewhere on the board
D23: J5.8; also elsewhere on the board
D24: J5.9; also elsewhere on the board
D25: J5.10; also elsewhere on the board
D26: J5.11; also elsewhere on the board
D27: J5.12; also elsewhere on the board
D28: J5.13; also elsewhere on the board
D29: J5.14; also elsewhere on the board
D30: J5.15; also elsewhere on the board
D31: J5.16; also elsewhere on the board
DS: J6.14; also elsewhere on the board
DSACK0: J6.3; also elsewhere on the board
DSACK1: J6.17; also elsewhere on the board
FC0: J6.16; also elsewhere on the board
FC1: J6.18; also elsewhere on the board
FC2: J6.20; also elsewhere on the board
GND: C4.2, C5.2, C6.2, C7.2, C8.2, C9.2, C10.2, C11.2, C12.2, C13.2, C14.2, C15.2, C16.2, C17.2, C18.2, C19.2, C20.2, J6.39, J6.40, J7.2, J8.2, J9.2, U2.7 (GND), U3.7 (GND), U4.8 (GND), U5.7 (VSS), U6.7 (GND), U7.7 (GND), U8.7 (GND), U12.7 (GND); also elsewhere on the board
HALT: J6.11; also elsewhere on the board
IACK: J6.28; also elsewhere on the board
IOSEL: J6.35; also elsewhere on the board
IP4: J6.36; also elsewhere on the board
IP5: J6.38; also elsewhere on the board
IPL0: J6.22; also elsewhere on the board
IPL1: J6.24; also elsewhere on the board
IPL2: J6.26; also elsewhere on the board
OP2: J6.32; also elsewhere on the board
OP3: J6.34; also elsewhere on the board
RAMSEL: J6.23; also elsewhere on the board
RD: J6.12; also elsewhere on the board
ROMSEL: J6.19; also elsewhere on the board
SIZ0: J6.6; also elsewhere on the board
SIZ1: J6.8; also elsewhere on the board
WR: J6.10; also elsewhere on the board
~DS0: J4.25; also elsewhere on the board
~DS1: J4.26; also elsewhere on the board
~DS2: J4.27; also elsewhere on the board
~DS3: J4.28; also elsewhere on the board

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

Board: 4 copper layers, 160.0 x 100.0 mm, 81 parts (0 on the bottom side), 167 nets.

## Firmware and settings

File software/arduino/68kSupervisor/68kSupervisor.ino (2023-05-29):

#define SERIAL_SPEED	115200

#define MEM_ADDR	0x000000
#define MEM_SIZE	4096

#define FLASH_ADDR	0x000000
#define SECTOR_SIZE	0x020000

#define M68_XADDR_PORT	PORTF
#define M68_XADDR_PIN	PINF
#define M68_XADDR_DDR	DDRF

#define M68_HADDR_PORT	PORTC
#define M68_HADDR_PIN	PINC
#define M68_HADDR_DDR	DDRC

#define M68_LADDR_PORT	PORTL
#define M68_LADDR_PIN	PINL
#define M68_LADDR_DDR	DDRL

#define M68_LDATA_PORT	PORTA
#define M68_LDATA_PIN	PINA
#define M68_LDATA_DDR	DDRA

#define M68_HDATA_PORT	PORTK
#define M68_HDATA_PIN	PINK
#define M68_HDATA_DDR	DDRK

#define M68_DTACK	38 // PD7
#define M68_BG		39 // PG2
#define M68_BGACK	40 // PG1
#define M68_BR		41 // PG0

#define M68_AS		50 // PB3
#define M68_UDS		51 // PB2
#define M68_LDS		52 // PB1
#define M68_RW		53 // PB0

#define M68_RESET	10 // PB4
#define M68_BERR	11 // PB5

#define M68_IS_AS()	(!(PINB & 0x08))
#define M68_IS_UDS()	(!(PINB & 0x04))
#define M68_IS_LDS()	(!(PINB & 0x02))
#define M68_IS_WRITE()	(!(PINB & 0x01))
#define M68_IS_READ()	(PINB & 0x01)

#define M68_INIT_DTACK()	{ digitalWrite(M68_DTACK, 0); pinMode(M68_DTACK, INPUT); }
#define M68_ASSERT_DTACK()	(DDRD |= 0x80)
#define M68_UNASSERT_DTACK()	(DDRD &= ~(0x80))

#define M68_INIT_RESET()	{ digitalWrite(M68_RESET, 0); pinMode(M68_RESET, INPUT); }
#define M68_ASSERT_RESET()	(pinMode(M68_RESET, OUTPUT))
#define M68_UNASSERT_RESET()	(pinMode(M68_RESET, INPUT))



#undef INLINE_NOP
#define INLINE_NOP		__asm__("nop\n\t");

#define BUS_DEVICE	0
#define BUS_CONTROLLER	1

byte bus_request = 0;
byte bus_mode = BUS_DEVICE;

#define TTY_COMMAND	0
#define TTY_PASS	1

byte tty_mode = TTY_COMMAND;

void cpu_stop();

void pciSetup(byte pin)
{
	*digitalPinToPCMSK(pin) |= bit (digitalPinToPCMSKbit(pin));  // enable pin
	PCIFR |= bit (digitalPinToPCICRbit(pin)); // clear any outstanding interrupt
	PCICR |= bit (digitalPinToPCICRbit(pin)); // enable interrupt for the group
}

void pciDisable(byte pin)
{
	PCICR &= ~(bit (digitalPinToPCICRbit(pin))); // disable interrupt for the group
}

void take_bus()
{
	digitalWrite(M68_BR, 0);
	while (digitalRead(M68_BG) && !digitalRead(M68_AS)) { }
	digitalWrite(M68_BGACK, 0);
}

void release_bus()
{
	digitalWrite(M68_BR, 1);
	digitalWrite(M68_BGACK, 1);
}

void set_bus_mode_controller()
{
	pciDisable(M68_AS);

	take_bus();

	// Controls
	pinMode(M68_AS, OUTPUT);
	pinMode(M68_UDS, OUTPUT);
	pinMode(M68_LDS, OUTPUT);
	pinMode(M68_RW, OUTPUT);
	pinMode(M68_DTACK, INPUT);
	digitalWrite(M68_AS, 1);
	digitalWrite(M68_UDS, 1);
	digitalWrite(M68_LDS, 1);
	digitalWrite(M68_RW, 1);

	// Address Bus
	M68_XADDR_PORT = 0x00;	// A17 - A23
	M68_XADDR_DDR = 0x7F;
	M68_HADDR_PORT = 0x00;	// A9 - A16
	M68_HADDR_DDR = 0xFF;
	M68_LADDR_PORT = 0x00;	// A1 - A8
	M68_LADDR_DDR = 0xFF;

	// Data Bus
	M68_LDATA_PORT = 0x00;	// D0 - D7
	M68_LDATA_DDR = 0x00;
	M68_HDATA_PORT = 0x00;	// D8 - D15
	M68_HDATA_DDR = 0x00;

	tty_mode = TTY_COMMAND;
	bus_mode = BUS_CONTROLLER;
}

void set_bus_mode_device()
{
	// Controls
	pinMode(M68_AS, INPUT);
	pinMode(M68_UDS, INPUT);
	pinMode(M68_LDS, INPUT);
	pinMode(M68_RW, INPUT);

	M68_INIT_DTACK();

	//pinMode(M68_RESET, OUTPUT);
	//digitalWrite(M68_RESET, 1);

	// Address Bus
	M68_XADDR_PORT = 0x00;	// A17 - A23
	M68_XADDR_DDR = 0x00;
	M68_HADDR_PORT = 0x00;	// A9 - A16
	M68_HADDR_DDR = 0x00;
	M68_LADDR_PORT = 0x00;	// A1 - A8
	M68_LADDR_DDR = 0x00;

	// Data Bus
	M68_LDATA_PORT = 0x00;	// D0 - D7
	M68_LDATA_DDR = 0x00;
	M68_HDATA_PORT = 0x00;	// D8 - D15
	M68_HDATA_DDR = 0x00;

	pciSetup(M68_AS);
	bus_mode = BUS_DEVICE;
}

/******************************
 * Serial Communications Code *
 ******************************/

#define SERIAL_SIZE	64

char serial_read_tail = 0;
char serial_read_head = 0;
char serial_avail = 0;
char serial_rb[SERIAL_SIZE];
char serial_write_head = 0;
char serial_write_tail = 0;
char serial_wb[SERIAL_SIZE];

byte read_serial()
{
	register char b;

	b = Serial.read();
	if (b == -1)
		return 0;

	if (tty_mode == TTY_PASS) {
		if (b == '`') {
			cpu_stop();
			set_bus_mode_controller();
			clear_read_buffer();
			return 0;
		}

		noInterrupts();
		//if (serial_read_head == serial_read_tail) {
		//	serial_read_head = 0;
		//	serial_read_tail = 0;	
		//}

		serial_rb[serial_read_tail++] = b;
		if (serial_read_tail >= SERIAL_SIZE)
			serial_read_tail = 0;
		interrupts();
		//Serial.write(serial_get_byte());
		return 0;
	}
	else if (tty_mode == TTY_COMMAND) {
		noInterrupts();
		serial_rb[serial_read_tail] = b;
		if (b == '\n' || b == '\r') {
			serial_rb[serial_read_tail] = '\0';
			serial_avail = 1;
		}
		if (serial_read_tail < SERIAL_SIZE)
			serial_read_tail++;
		interrupts();
		return serial_avail;
	}
}

inline byte serial_get_byte()
{
	register byte value;

	noInterrupts();
	if (serial_read_head == serial_read_tail) {
		//clear_read_buffer();
		value = -1;
	} else {
		value = serial_rb[serial_read_head++];
		if (serial_read_head >= SERIAL_SIZE)
			serial_read_head = 0;
	}
	interrupts();
	return value;
}

inline byte serial_add_byte(byte data)
{
	noInterrupts();
	serial_wb[serial_write_tail++] = data;
	interrupts();
}

void clear_read_buffer()
{
	noInterrupts();
	serial_avail = 0;
	serial_read_head = 0;
	serial_read_tail = 0;
	interrupts();
}

void flush_write_buffer()
{
	if (serial_write_tail > 0) {
		byte is_running = digitalRead(M68_BR);
		take_bus();
		noInterrupts();
		for (byte i = 0; i < serial_write_tail; i++) {
			Serial.write(serial_wb[i]);
		}
		serial_write_head = 0;
		serial_write_tail = 0;
		interrupts();
		if (is_running)
			release_bus();
	}
}


/*************************
 * Bus Cycle Interrupter *
 *************************/

word send_size = 768;
byte send_mem[] = {

};

#define ROM_SIZE	0x1800
#define ROM_MEM_SIZE	0x1800
word mem_size = ROM_MEM_SIZE;
byte mem[ROM_MEM_SIZE] = {

// Nop + Halt
//0x00, 0x00, 0x10, 0x00, 0x00, 0x00, 0x00, 0x08, 0x4e, 0x71, 0x4e, 0x72, 0x00, 0x00,

// Welcome Message
//0x00, 0x00, 0x10, 0x00, 0x00, 0x00, 0x00, 0x20, 0x00, 0x00, 0x00, 0x00, 0x00, 0x00, 0x00, 0x00, 0x00, 0x00, 0x00, 0x00, 0x00, 0x00, 0x00, 0x00, 0x00, 0x00, 0x00, 0x00, 0x00, 0x00, 0x00, 0x00, 0x12, 0x3c, 0x00, 0x01, 0x43, 0xf8, 0x02, 0xff, 0x12, 0x81, 0x43, 0xf8, 0x00, 0x50, 0x45, 0xf8, 0x02, 0xf1, 0x14, 0x19, 0x14, 0x82, 0x0c, 0x02, 0x00, 0x00, 0x66, 0x00, 0xff, 0xf6, 0x4e, 0x72, 0x27, 0x00, 0x00, 0x00, 0x00, 0x00, 0x00, 0x00, 0x00, 0x00, 0x00, 0x00, 0x00, 0x00, 0x00, 0x00, 0x57, 0x65, 0x6c, 0x63, 0x6f, 0x6d, 0x65, 0x20, 0x74, 0x6f, 0x20, 0x42, 0x72, 0x65, 0x61, 0x64, 0x36, 0x38, 0x6b, 0x21, 0x0a, 0x0a, 0x00,

//0x00, 0x00, 0x10, 0x00, 0x00, 0x00, 0x00, 0x20, 0x00, 0x00, 0x00, 0x00, 0x00, 0x00, 0x00, 0x00, 0x00, 0x00, 0x00, 0x00, 0x00, 0x00, 0x00, 0x00, 0x00, 0x00, 0x00, 0x00, 0x00, 0x00, 0x00, 0x00, 0x12, 0x3c, 0x00, 0x01, 0x43, 0xf8, 0x02, 0xff, 0x12, 0x81, 0x60, 0x04, 0x4e, 0x72, 0x27, 0x00, 0x4e, 0x56, 0x00, 0x00, 0x20, 0x79, 0x00, 0x00, 0x10, 0x00, 0x10, 0xbc, 0x00, 0x01, 0x70, 0x00, 0x4e, 0x5e, 0x4e, 0x75, 0x00, 0x00, 0x00, 0x00, 0x00, 0x00, 0x00, 0x00, 0x00, 0x00, 0x00, 0x00, 0x00, 0x00, 0x00, 0x00, 0x00, 0x00, 0x00, 0x00, 0x00, 0x00, 0x00, 0x00, 0x00, 0x00, 0x00, 0x00, 0x00, 0x00, 0x00, 0x00, 0x00, 0x00, 0x00, 0x00, 0x00, 0x00, 0x00, 0x00, 0x00, 0x00, 0x00, 0x00, 0x00, 0x00, 0x00, 0x00, 0x00, 0x00, 0x00, 0x00, 0x00, 0x00, 0x00, 0x00, 0x00, 0x00, 0x00, 0x00, 0x00, 0x00, 0x00, 0x00, 0x00, 0x00, 0x00, 0x00, 0x00, 0x00, 0x00, 0x00, 0x00, 0x00, 0x00, 0x00, 0x00, 0x00, 0x00, 0x00, 0x00, 0x00, 0x00, 0x00, 0x00, 0x00, 0x00, 0x00, 0x00, 0x00, 0x00, 0x00, 0x00, 0x00, 0x00, 0x00, 0x00, 0x00, 0x00, 0x00, 0x00, 0x00, 0x00, 0x00, 0x00, 0x00, 0x00, 0x00, 0x00, 0x00, 0x00, 0x00, 0x00, 0x00, 0x00, 0x00, 0x00, 0x00, 0x00, 0x00, 0x00, 0x00, 0x00, 0x00, 0x00, 0x00, 0x00, 0x00, 0x00, 0x00, 0x00, 0x00, 0x00, 0x00, 0x00, 0x00, 0x00, 0x00, 0x00, 0x00, 0x00, 0x00, 0x00, 0x00, 0x00, 0x00, 0x00, 0x00, 0x00, 0x00, 0x00, 0x00, 0x00, 0x00, 0x00, 0x00, 0x00, 0x00, 0x00, 0x00, 0x00, 0x00, 0x00, 0x00, 0x00, 0x00, 0x00, 0x00, 0x00, 0x00, 0x00, 0x00, 0x00, 0x00, 0x00, 0x00, 0x00, 0x00, 0x00, 0x00, 0x00, 0x00, 0x00, 0x00, 0x00, 0x00, 0x00, 0x00, 0x00, 0x00, 0x00, 0x00, 0x00, 0x00, 0x00, 0x00, 0x00, 0x00, 0x00, 0x00, 0x00, 0x00, 0x00, 0x00, 0x00, 0x00, 0x00, 0x00, 0x00, 0x00, 0x00, 0x00, 0x00, 0x00, 0x00, 0x00, 0x00, 0x00, 0x00, 0x00, 0x00, 0x00, 0x00, 0x00, 0x00, 0x00, 0x00, 0x00, 0x00, 0x00, 0x00, 0x00, 0x00, 0x00, 0x00, 0x00, 0x00, 0x00, 0x00, 0x00, 0x00, 0x00, 0x00, 0x00, 0x00, 0x00, 0x00, 0x00, 0x00, 0x00, 0x00, 0x00, 0x00, 0x00, 0x00, 0x00, 0x00, 0x00, 0x00, 0x00, 0x00, 0x00, 0x00, 0x00, 0x00, 0x00, 0x00, 0x00, 0x00, 0x00, 0x00, 0x00, 0x00, 0x00, 0x00, 0x00, 0x00, 0x00, 0x00, 0x00, 0x00, 0x00, 0x00, 0x00, 0x00, 0x00, 0x00, 0x00, 0x00, 0x00, 0x00, 0x00, 0x00, 0x00, 0x00, 0x00, 0x00, 0x00, 0x00, 0x00, 0x00, 0x00, 0x00, 0x00, 0x00, 0x00, 0x00, 0x00, 0x00, 0x00, 0x00, 0x00, 0x00, 0x00, 0x00, 0x00, 0x00, 0x00, 0x00, 0x00, 0x00, 0x00, 0x00, 0x00, 0x00, 0x00, 0x00, 0x00, 0x00, 0x00, 0x00, 0x00, 0x00, 0x00, 0x00, 0x00, 0x00, 0x00, 0x00, 0x00, 0x00, 0x00, 0x00, 0x00, 0x00, 0x00, 0x00, 0x00, 0x00, 0x00, 0x00, 0x00, 0x00, 0x00, 0x00, 0x00, 0x00, 0x00, 0x00, 0x00, 0x00, 0x00, 0x00, 0x00, 0x00, 0x00, 0x00, 0x00, 0x00, 0x00, 0x00, 0x00, 0x00, 0x00, 0x00, 0x00, 0x00, 0x00, 0x00, 0x00, 0x00, 0x00, 0x00, 0x00, 0x00, 0x00, 0x00, 0x00, 0x00, 0x00, 0x00, 0x00, 0x00, 0x00, 0x00, 0x00, 0x00, 0x00, 0x00, 0x00, 0x00, 0x00, 0x00, 0x00, 0x00, 0x00, 0x00, 0x00, 0x00, 0x00, 0x00, 0x00, 0x00, 0x00, 0x00, 0x00, 0x00, 0x00, 0x00, 0x00, 0x00, 0x00, 0x00, 0x00, 0x00, 0x00, 0x00, 0x00, 0x00, 0x00, 0x00, 0x00, 0x00, 0x00, 0x00, 0x00, 0x00, 0x00, 0x00, 0x00, 0x00, 0x00, 0x00, 0x00, 0x00, 0x00, 0x00, 0x00, 0x00, 0x00, 0x00, 0x00, 0x00, 0x00, 0x00, 0x00, 0x00, 0x00, 0x00, 0x00, 0x00, 0x00, 0x00, 0x00, 0x00, 0x00, 0x00, 0x00, 0x00, 0x00, 0x00, 0x00, 0x00, 0x00, 0x00, 0x00, 0x00, 0x00, 0x00, 0x00, 0x00, 0x00, 0x00, 0x00, 0x00, 0x00, 0x00, 0x00, 0x00, 0x00, 0x00, 0x00, 0x00, 0x00, 0x00, 0x00, 0x00, 0x00, 0x00, 0x00, 0x00, 0x00, 0x00, 0x00, 0x00, 0x00, 0x00, 0x00, 0x00, 0x00, 0x00, 0x00, 0x00, 0x00, 0x00, 0x00, 0x00, 0x00, 0x00, 0x00, 0x00, 0x00, 0x00, 0x00, 0x00, 0x00, 0x00, 0x00, 0x00, 0x00, 0x00, 0x00, 0x00, 0x00, 0x00, 0x00, 0x00, 0x00, 0x00, 0x00, 0x00, 0x00, 0x00, 0x00, 0x00, 0x00, 0x00, 0x00, 0x00, 0x00, 0x00, 0x00, 0x00, 0x00, 0x00, 0x00, 0x00, 0x00, 0x00, 0x00, 0x00, 0x00, 0x00, 0x00, 0x00, 0x00, 0x00, 0x00, 0x00, 0x00, 0x00, 0x00, 0x00, 0x00, 0x00, 0x00, 0x00, 0x00, 0x00, 0x00, 0x00, 0x00, 0x00, 0x00, 0x00, 0x00, 0x00, 0x00, 0x00, 0x00, 0x00, 0x00, 0x00, 0x00, 0x00, 0x00, 0x00, 0x00, 0x00, 0x00, 0x00, 0x00, 0x00, 0x00, 0x00, 0x00, 0x00, 0x00, 0x00, 0x00, 0x00, 0x00, 0x00, 0x00, 0x00, 0x00, 0x00, 0x00, 0x00, 0x00, 0x00, 0x00, 0x00, 0x00, 0x00, 0x00, 0x00, 0x00, 0x00, 0x00, 0x00, 0x00, 0x00, 0x00, 0x00, 0x00, 0x00, 0x00, 0x00, 0x00, 0x00, 0x00, 0x00, 0x00, 0x00, 0x00, 0x00, 0x00, 0x00, 0x00, 0x00, 0x00, 0x00, 0x00, 0x00, 0x00, 0x00, 0x00, 0x00, 0x00, 0x00, 0x00, 0x00, 0x00, 0x00, 0x00, 0x00, 0x00, 0x00, 0x00, 0x00, 0x00, 0x00, 0x00, 0x00, 0x00, 0x00, 0x00, 0x00, 0x00, 0x00, 0x00, 0x00, 0x00, 0x00, 0x00, 0x00, 0x00, 0x00, 0x00, 0x00, 0x00, 0x00, 0x00, 0x00, 0x00, 0x00, 0x00, 0x00, 0x00, 0x00, 0x00, 0x00, 0x00, 0x00, 0x00, 0x00, 0x00, 0x00, 0x00, 0x00, 0x00, 0x00, 0x00, 0x00, 0x00, 0x00, 0x00, 0x00, 0x00, 0x00, 0x00, 0x00, 0x00, 0x00, 0x00, 0x00, 0x00, 0x00, 0x00, 0x00, 0x00, 0x00, 0x00, 0x00, 0x00, 0x00, 0x00, 0x00, 0x00, 0x00, 0x00, 0x00, 0x00, 0x00, 0x00, 0x00, 0x00, 0x00, 0x00, 0x00, 0x00, 0x00, 0x00, 0x00, 0x00, 0x00, 0x00, 0x00, 0x00, 0x00, 0x00, 0x00, 0x00, 0x00, 0x00, 0x00, 0x00, 0x00, 0x00, 0x00, 0x00, 0x00, 0x00, 0x00, 0x00, 0x00, 0x00, 0x00, 0x00, 0x00, 0x00, 0x00, 0x00, 0x00, 0x00, 0x00, 0x00, 0x00, 0x00, 0x00, 0x00, 0x00, 0x00, 0x00, 0x00, 0x00, 0x00, 0x00, 0x00, 0x00, 0x00, 0x00, 0x00, 0x00, 0x00, 0x00, 0x00, 0x00, 0x00, 0x00, 0x00, 0x00, 0x00, 0x00, 0x00, 0x00, 0x00, 0x00, 0x00, 0x00, 0x00, 0x00, 0x00, 0x00, 0x00, 0x00, 0x00, 0x00, 0x00, 0x00, 0x00, 0x00, 0x00, 0x00, 0x00, 0x00, 0x00, 0x00, 0x00, 0x00, 0x00, 0x00, 0x00, 0x00, 0x00, 0x00, 0x00, 0x00, 0x00, 0x00, 0x00, 0x00, 0x00, 0x00, 0x00, 0x00, 0x00, 0x00, 0x00, 0x00, 0x00, 0x00, 0x00, 0x00, 0x00, 0x00, 0x00, 0x00, 0x00, 0x00, 0x00, 0x00, 0x00, 0x00, 0x00, 0x00, 0x00, 0x00, 0x00, 0x00, 0x00, 0x00, 0x00, 0x00, 0x00, 0x00, 0x00, 0x00, 0x00, 0x00, 0x00, 0x00, 0x00, 0x00, 0x00, 0x00, 0x00, 0x00, 0x00, 0x00, 0x00, 0x00, 0x00, 0x00, 0x00, 0x00, 0x00, 0x00, 0x00, 0x00, 0x00, 0x00, 0x00, 0x00, 0x00, 0x00, 0x00, 0x00, 0x00, 0x00, 0x00, 0x00, 0x00, 0x00, 0x00, 0x00, 0x00, 0x00, 0x00, 0x00, 0x00, 0x00, 0x00, 0x00, 0x00, 0x00, 0x00, 0x00, 0x00, 0x00, 0x00, 0x00, 0x00, 0x00, 0x00, 0x00, 0x00, 0x00, 0x00, 0x00, 0x00, 0x00, 0x00, 0x00, 0x00, 0x00, 0x00, 0x00, 0x00, 0x00, 0x00, 0x00, 0x00, 0x00, 0x00, 0x00, 0x00, 0x00, 0x00, 0x00, 0x00, 0x00, 0x00, 0x00, 0x00, 0x00, 0x00, 0x00, 0x00, 0x00, 0x00, 0x00, 0x00, 0x00, 0x00, 0x00, 0x00, 0x00, 0x00, 0x00, 0x00, 0x00, 0x00, 0x00, 0x00, 0x00, 0x00, 0x00, 0x00, 0x00, 0x00, 0x00, 0x00, 0x00, 0x00, 0x00, 0x00, 0x00, 0x00, 0x00, 0x00, 0x00, 0x00, 0x00, 0x00, 0x00, 0x00, 0x00, 0x00, 0x00, 0x00, 0x00, 0x00, 0x00, 0x00, 0x00, 0x00, 0x00, 0x00, 0x00, 0x00, 0x00, 0x00, 0x00, 0x00, 0x00, 0x00, 0x00, 0x00, 0x00, 0x00, 0x00, 0x00, 0x00, 0x00, 0x00, 0x00, 0x00, 0x00, 0x00, 0x00, 0x00, 0x00, 0x00, 0x00, 0x00, 0x00, 0x00, 0x00, 0x00, 0x00, 0x00, 0x00, 0x00, 0x00, 0x00, 0x00, 0x00, 0x00, 0x00, 0x00, 0x00, 0x00, 0x00, 0x00, 0x00, 0x00, 0x00, 0x00, 0x00, 0x00, 0x00, 0x00, 0x00, 0x00, 0x00, 0x00, 0x00, 0x00, 0x00, 0x00, 0x00, 0x00, 0x00, 0x00, 0x00, 0x00, 0x00, 0x00, 0x00, 0x00, 0x00, 0x00, 0x00, 0x00, 0x00, 0x00, 0x00, 0x00, 0x00, 0x00, 0x00, 0x00, 0x00, 0x00, 0x00, 0x00, 0x00, 0x00, 0x00, 0x00, 0x00, 0x00, 0x00, 0x00, 0x00, 0x00, 0x00, 0x00, 0x00, 0x00, 0x00, 0x00, 0x00, 0x00, 0x00, 0x00, 0x00, 0x00, 0x00, 0x00, 0x00, 0x00, 0x00, 0x00, 0x00, 0x00, 0x00, 0x00, 0x00, 0x00, 0x00, 0x00, 0x00, 0x00, 0x00, 0x00, 0x00, 0x00, 0x00, 0x00, 0x00, 0x00, 0x00, 0x00, 0x00, 0x00, 0x00, 0x00, 0x00, 0x00, 0x00, 0x00, 0x00, 0x00, 0x00, 0x00, 0x00, 0x00, 0x00, 0x00, 0x00, 0x00, 0x00, 0x00, 0x00, 0x00, 0x00, 0x00, 0x00, 0x00, 0x00, 0x00, 0x00, 0x00, 0x00, 0x00, 0x00, 0x00, 0x00, 0x00, 0x00, 0x00, 0x00, 0x00, 0x00, 0x00, 0x00, 0x00, 0x00, 0x00, 0x00, 0x00, 0x00, 0x00, 0x00, 0x00, 0x00, 0x00, 0x00, 0x00, 0x00, 0x00, 0x00, 0x00, 0x00, 0x00, 0x00, 0x00, 0x00, 0x00, 0x00, 0x00, 0x00, 0x00, 0x00, 0x00, 0x00, 0x00, 0x00, 0x00, 0x00, 0x00, 0x00, 0x00, 0x00, 0x00, 0x00, 0x00, 0x00, 0x00, 0x00, 0x00, 0x00, 0x00, 0x00, 0x00, 0x00, 0x00, 0x00, 0x00, 0x00, 0x00, 0x00, 0x00, 0x00, 0x00, 0x00, 0x00, 0x00, 0x00, 0x00, 0x00, 0x00, 0x00, 0x00, 0x00, 0x00, 0x00, 0x00, 0x00, 0x00, 0x00, 0x00, 0x00, 0x00, 0x00, 0x00, 0x00, 0x00, 0x00, 0x00, 0x00, 0x00, 0x00, 0x00, 0x00, 0x00, 0x00, 0x00, 0x00, 0x00, 0x00, 0x00, 0x00, 0x00, 0x00, 0x00, 0x00, 0x00, 0x00, 0x00, 0x00, 0x00, 0x00, 0x00, 0x00, 0x00, 0x00, 0x00, 0x00, 0x00, 0x00, 0x00, 0x00, 0x00, 0x00, 0x00, 0x00, 0x00, 0x00, 0x00, 0x00, 0x00, 0x00, 0x00, 0x00, 0x00, 0x00, 0x00, 0x00, 0x00, 0x00, 0x00, 0x00, 0x00, 0x00, 0x00, 0x00, 0x00, 0x00, 0x00, 0x00, 0x00, 0x00, 0x00, 0x00, 0x00, 0x00, 0x00, 0x00, 0x00, 0x00, 0x00, 0x00, 0x00, 0x00, 0x00, 0x00, 0x00, 0x00, 0x00, 0x00, 0x00, 0x00, 0x00, 0x00, 0x00, 0x00, 0x00, 0x00, 0x00, 0x00, 0x00, 0x00, 0x00, 0x00, 0x00, 0x00, 0x00, 0x00, 0x00, 0x00, 0x00, 0x00, 0x00, 0x00, 0x00, 0x00, 0x00, 0x00, 0x00, 0x00, 0x00, 0x00, 0x00, 0x00, 0x00, 0x00, 0x00, 0x00, 0x00, 0x00, 0x00, 0x00, 0x00, 0x00, 0x00, 0x00, 0x00, 0x00, 0x00, 0x00, 0x00, 0x00, 0x00, 0x00, 0x00, 0x00, 0x00, 0x00, 0x00, 0x00, 0x00, 0x00, 0x00, 0x00, 0x00, 0x00, 0x00, 0x00, 0x00, 0x00, 0x00, 0x00, 0x00, 0x00, 0x00, 0x00, 0x00, 0x00, 0x00, 0x00, 0x00, 0x00, 0x00, 0x00, 0x00, 0x00, 0x00, 0x00, 0x00, 0x00, 0x00, 0x00, 0x00, 0x00, 0x00, 0x00, 0x00, 0x00, 0x00, 0x00, 0x00, 0x00, 0x00, 0x00, 0x00, 0x00, 0x00, 0x00, 0x00, 0x00, 0x00, 0x00, 0x00, 0x00, 0x00, 0x00, 0x00, 0x00, 0x00, 0x00, 0x00, 0x00, 0x00, 0x00, 0x00, 0x00, 0x00, 0x00, 0x00, 0x00, 0x00, 0x00, 0x00, 0x00, 0x00, 0x00, 0x00, 0x00, 0x00, 0x00, 0x00, 0x00, 0x00, 0x00, 0x00, 0x00, 0x00, 0x00, 0x00, 0x00, 0x00, 0x00, 0x00, 0x00, 0x00, 0x00, 0x00, 0x00, 0x00, 0x00, 0x00, 0x00, 0x00, 0x00, 0x00, 0x00, 0x00, 0x00, 0x00, 0x00, 0x00, 0x00, 0x00, 0x00, 0x00, 0x00, 0x00, 0x00, 0x00, 0x00, 0x00, 0x00, 0x00, 0x00, 0x00, 0x00, 0x00, 0x00, 0x00, 0x00, 0x00, 0x00, 0x00, 0x00, 0x00, 0x00, 0x00, 0x00, 0x00, 0x00, 0x00, 0x00, 0x00, 0x00, 0x00, 0x00, 0x00, 0x00, 0x00, 0x00, 0x00, 0x00, 0x00, 0x00, 0x00, 0x00, 0x00, 0x00, 0x00, 0x00, 0x00, 0x00, 0x00, 0x00, 0x00, 0x00, 0x00, 0x00, 0x00, 0x00, 0x00, 0x00, 0x00, 0x00, 0x00, 0x00, 0x00, 0x00, 0x00, 0x00, 0x00, 0x00, 0x00, 0x00, 0x00, 0x00, 0x00, 0x00, 0x00, 0x00, 0x00, 0x00, 0x00, 0x00, 0x00, 0x00, 0x00, 0x00, 0x00, 0x00, 0x00, 0x00, 0x00, 0x00, 0x00, 0x00, 0x00, 0x00, 0x00, 0x00, 0x00, 0x00, 0x00, 0x00, 0x00, 0x00, 0x00, 0x00, 0x00, 0x00, 0x00, 0x00, 0x00, 0x00, 0x00, 0x00, 0x00, 0x00, 0x00, 0x00, 0x00, 0x00, 0x00, 0x00, 0x00, 0x00, 0x00, 0x00, 0x00, 0x00, 0x00, 0x00, 0x00, 0x00, 0x00, 0x00, 0x00, 0x00, 0x00, 0x00, 0x00, 0x00, 0x00, 0x00, 0x00, 0x00, 0x00, 0x00, 0x00, 0x00, 0x00, 0x00, 0x00, 0x00, 0x00, 0x00, 0x00, 0x00, 0x00, 0x00, 0x00, 0x00, 0x00, 0x00, 0x00, 0x00, 0x00, 0x00, 0x00, 0x00, 0x00, 0x00, 0x00, 0x00, 0x00, 0x00, 0x00, 0x00, 0x00, 0x00, 0x00, 0x00, 0x00, 0x00, 0x00, 0x00, 0x00, 0x00, 0x00, 0x00, 0x00, 0x00, 0x00, 0x00, 0x00, 0x00, 0x00, 0x00, 0x00, 0x00, 0x00, 0x00, 0x00, 0x00, 0x00, 0x00, 0x00, 0x00, 0x00, 0x00, 0x00, 0x00, 0x00, 0x00, 0x00, 0x00, 0x00, 0x00, 0x00, 0x00, 0x00, 0x00, 0x00, 0x00, 0x00, 0x00, 0x00, 0x00, 0x00, 0x00, 0x00, 0x00, 0x00, 0x00, 0x00, 0x00, 0x00, 0x00, 0x00, 0x00, 0x00, 0x00, 0x00, 0x00, 0x00, 0x00, 0x00, 0x00, 0x00, 0x00, 0x00, 0x00, 0x00, 0x00, 0x00, 0x00, 0x00, 0x00, 0x00, 0x00, 0x00, 0x00, 0x00, 0x00, 0x00, 0x00, 0x00, 0x00, 0x00, 0x00, 0x00, 0x00, 0x00, 0x00, 0x00, 0x00, 0x00, 0x00, 0x00, 0x00, 0x00, 0x00, 0x00, 0x00, 0x00, 0x00, 0x00, 0x00, 0x00, 0x00, 0x00, 0x00, 0x00, 0x00, 0x00, 0x00, 0x00, 0x00, 0x00, 0x00, 0x00, 0x00, 0x00, 0x00, 0x00, 0x00, 0x00, 0x00, 0x00, 0x00, 0x00, 0x00, 0x00, 0x00, 0x00, 0x00, 0x00, 0x00, 0x00, 0x00, 0x00, 0x00, 0x00, 0x00, 0x00, 0x00, 0x00, 0x00, 0x00, 0x00, 0x00, 0x00, 0x00, 0x00, 0x00, 0x00, 0x00, 0x00, 0x00, 0x00, 0x00, 0x00, 0x00, 0x00, 0x00, 0x00, 0x00, 0x00, 0x00, 0x00, 0x00, 0x00, 0x00, 0x00, 0x00, 0x00, 0x00, 0x00, 0x00, 0x00, 0x00, 0x00, 0x00, 0x00, 0x00, 0x00, 0x00, 0x00, 0x00, 0x00, 0x00, 0x00, 0x00, 0x00, 0x00, 0x00, 0x00, 0x00, 0x00, 0x00, 0x00, 0x00, 0x00, 0x00, 0x00, 0x00, 0x00, 0x00, 0x00, 0x00, 0x00, 0x00, 0x00, 0x00, 0x00, 0x00, 0x00, 0x00, 0x00, 0x00, 0x00, 0x00, 0x00, 0x00, 0x00, 0x00, 0x00, 0x00, 0x00, 0x00, 0x00, 0x00, 0x00, 0x00, 0x00, 0x00, 0x00, 0x00, 0x00, 0x00, 0x00, 0x00, 0x00, 0x00, 0x00, 0x00, 0x00, 0x00, 0x00, 0x00, 0x00, 0x00, 0x00, 0x00, 0x00, 0x00, 0x00, 0x00, 0x00, 0x00, 0x00, 0x00, 0x00, 0x00, 0x00, 0x00, 0x00, 0x00, 0x00, 0x00, 0x00, 0x00, 0x00, 0x00, 0x00, 0x00, 0x00, 0x00, 0x00, 0x00, 0x00, 0x00, 0x00, 0x00, 0x00, 0x00, 0x00, 0x00, 0x00, 0x00, 0x00, 0x00, 0x00, 0x00, 0x00, 0x00, 0x00, 0x00, 0x00, 0x00, 0x00, 0x00, 0x00, 0x00, 0x00, 0x00, 0x00, 0x00, 0x00, 0x00, 0x00, 0x00, 0x00, 0x00, 0x00, 0x00, 0x00, 0x00, 0x00, 0x00, 0x00, 0x00, 0x00, 0x00, 0x00, 0x00, 0x00, 0x00, 0x00, 0x00, 0x00, 0x00, 0x00, 0x00, 0x00, 0x00, 0x00, 0x00, 0x00, 0x00, 0x00, 0x00, 0x00, 0x00, 0x00, 0x00, 0x00, 0x00, 0x00, 0x00, 0x00, 0x00, 0x00, 0x00, 0x00, 0x00, 0x00, 0x00, 0x00, 0x00, 0x00, 0x00, 0x00, 0x00, 0x00, 0x00, 0x00, 0x00, 0x00, 0x00, 0x00, 0x00, 0x00, 0x00, 0x00, 0x00, 0x00, 0x00, 0x00, 0x00, 0x00, 0x00, 0x00, 0x00, 0x00, 0x00, 0x00, 0x00, 0x00, 0x00, 0x00, 0x00, 0x00, 0x00, 0x00, 0x00, 0x00, 0x00, 0x00, 0x00, 0x00, 0x00, 0x00, 0x00, 0x00, 0x00, 0x00, 0x00, 0x00, 0x00, 0x00, 0x00, 0x00, 0x00, 0x00, 0x00, 0x00, 0x00, 0x00, 0x00, 0x00, 0x00, 0x00, 0x00, 0x00, 0x00, 0x00, 0x00, 0x00, 0x00, 0x00, 0x00, 0x00, 0x00, 0x00, 0x00, 0x00, 0x00, 0x00, 0x00, 0x00, 0x00, 0x00, 0x00, 0x00, 0x00, 0x00, 0x00, 0x00, 0x00, 0x00, 0x00, 0x00, 0x00, 0x00, 0x00, 0x00, 0x00, 0x00, 0x00, 0x00, 0x00, 0x00, 0x00, 0x00, 0x00, 0x00, 0x00, 0x00, 0x00, 0x00, 0x00, 0x00, 0x00, 0x00, 0x00, 0x00, 0x00, 0x00, 0x00, 0x00, 0x00, 0x00, 0x00, 0x00, 0x00, 0x00, 0x00, 0x00, 0x00, 0x00, 0x00, 0x00, 0x00, 0x00, 0x00, 0x00, 0x00, 0x00, 0x00, 0x00, 0x00, 0x00, 0x00, 0x00, 0x00, 0x00, 0x00, 0x00, 0x00, 0x00, 0x00, 0x00, 0x00, 0x00, 0x00, 0x00, 0x00, 0x00, 0x00, 0x00, 0x00, 0x00, 0x00, 0x00, 0x00, 0x00, 0x00, 0x00, 0x00, 0x00, 0x00, 0x00, 0x00, 0x00, 0x00, 0x00, 0x00, 0x00, 0x00, 0x00, 0x00, 0x00, 0x00, 0x00, 0x00, 0x00, 0x00, 0x00, 0x00, 0x00, 0x00, 0x00, 0x00, 0x00, 0x00, 0x00, 0x00, 0x00, 0x00, 0x00, 0x00, 0x00, 0x00, 0x00, 0x00, 0x00, 0x00, 0x00, 0x00, 0x00, 0x00, 0x00, 0x00, 0x00, 0x00, 0x00, 0x00, 0x00, 0x00, 0x00, 0x00, 0x00, 0x00, 0x00, 0x00, 0x00, 0x00, 0x00, 0x00, 0x00, 0x00, 0x00, 0x00, 0x00, 0x00, 0x00, 0x00, 0x00, 0x00, 0x00, 0x00, 0x00, 0x00, 0x00, 0x00, 0x00, 0x00, 0x00, 0x00, 0x00, 0x00, 0x00, 0x00, 0x00, 0x00, 0x00, 0x00, 0x00, 0x00, 0x00, 0x00, 0x00, 0x00, 0x00, 0x00, 0x00, 0x00, 0x00, 0x00, 0x00, 0x00, 0x00, 0x00, 0x00, 0x00, 0x00, 0x00, 0x00, 0x00, 0x00, 0x00, 0x00, 0x00, 0x00, 0x00, 0x00, 0x00, 0x00, 0x00, 0x00, 0x00, 0x00, 0x00, 0x00, 0x00, 0x00, 0x00, 0x00, 0x00, 0x00, 0x00, 0x00, 0x00, 0x00, 0x00, 0x00, 0x00, 0x00, 0x00, 0x00, 0x00, 0x00, 0x00, 0x00, 0x00, 0x00, 0x00, 0x00, 0x00, 0x00, 0x00, 0x00, 0x00, 0x00, 0x00, 0x00, 0x00, 0x00, 0x00, 0x00, 0x00, 0x00, 0x00, 0x00, 0x00, 0x00, 0x00, 0x00, 0x00, 0x00, 0x00, 0x00, 0x00, 0x00, 0x00, 0x00, 0x00, 0x00, 0x00, 0x00, 0x00, 0x00, 0x00, 0x00, 0x00, 0x00, 0x00, 0x00, 0x00, 0x00, 0x00, 0x00, 0x00, 0x00, 0x00, 0x00, 0x00, 0x00, 0x00, 0x00, 0x00,
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
void loop()
{
	if (read_serial() && tty_mode == TTY_COMMAND) {
		int argc;
		char *argv[MAX_ARGS];

		Serial.print(serial_rb);
		Serial.print("\n");
		argc = parse_serial_command(argv);
		do_command(argc, argv);
		clear_read_buffer();

		if (tty_mode == TTY_COMMAND)
			Serial.print("\n> ");
	}

	check_bus_cycle();
	//snoop_bus_cycle();
}

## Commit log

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2019-12-20 Move parts library and added svg of Z80 schematic
    [Z80Proto.sch]
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2019-12-24 Added partially complete 68k board design and system monitor
    [68kBoard.sch, Memory.sch, UART.sch]
2020-01-04 Fixed some minor issues, moved some funcs to stdlib, and added strtol
    [main.c]
2020-03-01 Added 68kBoard PCB Design
    [68kBoard.kicad_pcb, 68kBoard.sch, Memory.sch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]
2020-03-05 Mostly done 68k board design
    [68kBoard.kicad_pcb, 68kBoard.sch, Memory.sch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]
2020-03-24 Fixed some issues after testing with the 68681 chips
    [68kBoard.kicad_pcb, 68kBoard.sch, UART.sch]
2020-03-27 Reordered address and data buses for easier connection to arduino
    [68kBoard.kicad_pcb, 68kBoard.sch]
2020-03-27 Added 68k Supervisor Shield PCB
    [68kBoardSupervisorShield.kicad_pcb, 68kBoardSupervisorShield.sch]
2020-03-28 Finalized 68kBoard and 68kBoardSupervisorShield
    [68kBoard.kicad_pcb, 68kBoardSupervisorShield.kicad_pcb, 68kBoardSupervisorShield.sch]
2020-04-17 Some code changes related to the rev.0 board
2020-05-23 Various tests for the hardware
    [68kBoard.sch, Memory.sch]
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2020-05-26 FIxed the mul/div/mod functions (sort of)
    [main.c]
2020-06-07 Split into a monitor and kernel, and set up serial loading
    [68kBoard.kicad_pcb, 68kBoard.sch, Memory.sch]
2020-06-11 Fixed issue preventing optimizated output from running correctly
    [load.py, main.c]
2020-06-13 Separated hardware and software files
    [68kBoard.kicad_pcb, 68kBoard.sch, 68kBoardSupervisorShield.kicad_pcb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]
2020-06-17 Added 68681 timer interrupt and fixed exception error printing
    [main.c]
2020-06-18 Fixed timer triggered task
    [main.c]
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2020-06-27 Added the exit syscall, and insert it after main returns
2020-06-28 Moved inode to fs/vnode and fix some compiler warnings
    [main.c]
2020-07-02 Modified monitor fatal errors interrupt
    [68kSupervisor.ino]
2020-07-06 Added mallocfs (simple malloc-backed fs with a fixed block size)
    [main.c]
2020-07-08 Fixed issue with filedescs not being freed correctly
    [load.py, main.c]
2020-07-10 Fixed tty buffer issues, added some flow control (but not perfect yet), and started implementing unlink
    [load.py, main.c]
2020-07-13 Added missing buffer definition file
    [load.py]
2020-07-15 Added printk so that libc-68k-os can be linked to the kernel binary
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2020-07-19 Added tty safe mode when monitor boots to avoid a lockup
    [main.c]
2020-07-23 Reorganized to separate hardware and software at the top level
    [68kBoard.kicad_pcb, 68kBoard.sch, 68kBoardSupervisorShield.kicad_pcb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]
2020-07-23 Fixed some path references
    [68kSupervisor.ino]
2020-08-14 Revision 2 of 68k-SBC
    [68kBoard.kicad_pcb, 68kBoard.sch, 68kBoardSupervisorShield.kicad_pcb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]
2020-08-17 Final version of rev 2
    [68kBoard.kicad_pcb, 68kBoardSupervisorShield.kicad_pcb]
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2020-08-30 Added rev2 images, and fixed supervisor to work with rev2
    [68kSupervisor.ino]
2020-09-03 Added mode arg to open() and fixed a scheduling bug
    [main.c]
2020-09-05 Added current working directory to process struct, and chdir()
2020-09-12 Partially added command redirecting, added dup2() syscall, and fixed issue where printf was using direct output
    [main.c]
2020-09-13 Fixed issue with invalid paths
    [main.c]
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2020-09-20 Added preinit for serial console such that the buffer is saved and printed when interrupts are enabled
2020-09-24 Modified minixfs to write device numbers to inodes of special device files
2020-09-24 Added mem driver, and modified bufcache to use drivers with a given offset
2020-09-25 Added direct printk function, and fixed a bug in the pipe implementation
2020-09-26 Added rdev value to vnode and moved driver vfs related code into main
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2020-10-09 Separated processes and scheduler and fixed signal handling
    [main.c]
2020-10-15 Refactored to use vfile ops for device access for device special files
2020-10-15 Added argument to new_proc to specify an exact pid to use, or 0 for the next one
2020-10-15 Added missing device file ops files
2020-10-18 Reorganized kicad files
    [68kBoard.kicad_pcb, 68kBoard.sch, 68kBoardSupervisorShield.kicad_pcb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]
2020-10-22 Removed the use of current_proc_stack by directly using current_proc
2020-10-26 Added kernel re-entry, and the locking required for the serial interrupt
    Hardware interrupts are now enabled when handling syscalls, which allows
    the serial interrupt to be handled during a syscall. Rescheduling of
    processes is skipped when a syscall is in progress, but in future it will
    only be delayed until the end of the current syscall. The only things
    that need to be locked, as a result of this, are things that are also
    manipulated by the serial interrupt, namely the serial buffer operations
    and the resuming of suspended processes due to available serial data.
2020-11-05 Added procfs and fixed a refcount bug with mounted filesystems
    [main.c]
2020-11-07 Fixed issue with zombie procs by making orphans be children of init (pid 1)
    Init is always waiting for processes and will thus cleanup when they exit,
    whereas the parent's parent proc might not be waiting for procs, thus the
    zombie will stick around
2020-11-27 Added 68k-SMT board, which is similar to 68k-SBC, but with PLCC/SMT components and a CompactFlash card slot
    [68k-SMT.kicad_pcb, 68k-SMT.sch, CompactFlash.sch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]
2020-11-30 Removed IDE header which doesn't easily fit, and cleaned up the PCB design a bit
    [68k-SMT.kicad_pcb, CompactFlash.sch]
2020-12-01 Fixed alignment error in allocs and a timing issue in the ata driver
2020-12-01 Finalized 68k-SMT board and sent off to print
    [68k-SMT.kicad_pcb, 68k-SMT.sch]
2020-12-01 Added hackish partition table reader to ATA driver (should be elsewhere)
2020-12-14 Modified the timing in ATA driver a bit
2020-12-14 Removed debug prints and fixed flat binary execution as a fallback
2020-12-16 Fixed some compiler warnings
    [main.c]
2020-12-17 Moved the schedule() call to restore_context, and added a bottom-half interrupt mechanism
2020-12-19 Fixed the procfs data for the cmdline file
    [68kSupervisor.ino]
2020-12-23 Fixed flow control in the interrupt-driven serial driver, and optimized a bit
2020-12-28 Fixed echoing in monitor, and added help and erase commands
    It's now possible to use the load command to load the latest copy of
    the monitor rom into ram over serial, and then eraserom and writerom
    to burn the new copy of the monitor into flash
    [68kSupervisor.ino]
2020-12-29 Added mount/umount commands and fixed bug with unmounting
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2021-01-09 Fixed bug with missing chars from tty input
    During the send command, after the command starts, the first bytes
    read in should be the size of the subsequent bytes to read in, but
    a character was getting lost when switching the terminal from
    cannonical mode to raw mode. Using a lock when setting the termios
    data seems to have fixed this.
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2021-01-12 Modified mount() args and implemented fstype lookup in the syscall
2021-01-12 Reset tty input buffer on ^C and added some delays to fix garbled output
    [main.c]
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2021-01-13 Modified procfs to have root-level files, and added /proc/mounts
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2021-02-02 Added initial networking module
    This is the initial commit of the networking subsystem that I've been
    working on for the past two weeks. It supports very simple UDP messages
    without checksum calculations or address processing, and is able to
    receive UDP messages sent from the host computer. Sending shows the
    packets in wireshark, but receiving on the host is not quite working.
    I wanted to get the partial work committed before making changes to
    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
2021-02-03 Fixed issue where an unbound socket wasn't creating an ephemeral port
    Ephemeral port numbering is still not working, apart from a fixed
    port number being used
2021-02-04 Fixed bug in procfs where extra files not listed
    Only the process directories were being returned by readdir() and
    not the /proc/mounts file. There is now a different way of using
    file->position to represent the position of either the process_iter
    or the current static root file slot
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2021-02-04 Added getopt() function and used in mount command
2021-02-07 Fixed issues with mounted fs in lookup and reverse lookup
2021-02-11 Added socket passthroughs for most of the remaining socket syscalls
2021-02-13 Added simple TCP implementation
    There are no timers, retries, or reordering of packets, but it can
    connect and transmit data in either direction
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2021-02-18 Added some string functions and options to printf
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2021-02-24 Added select() syscall
    This required modifying the wait checking to allow custom wait functions
    and adding a vfs file operation, poll, which can return whether a file
    or device or endpoint is ready for reading/writing.
2021-09-02 Fixed terminology in Supervisors
    [68kSupervisor.ino, Z80Supervisor.ino]
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2021-10-29 Finished schematic design for k30-SBC board
    [Bus.sch, IO.sch, Logic.sch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]
2021-11-28 Almost completed k30-SBC board design
    [Bus.sch, IO.sch, Logic.sch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]
2021-12-01 Fixed CF footprint and the wrong data pins going for CF
    [IO.sch, k30-SBC.kicad_pcb]
2021-12-05 Last minute changes: swapped WR/DS pins, added testpoint
    [Bus.sch, k30-SBC.kicad_pcb, k30-SBC.sch]
2021-12-06 Final fixes to remove narrow traces
    [k30-SBC.kicad_pcb]
2022-02-06 Modified makefile and monitor for k30-SBC
    In particular, I added a flag that's set if compiling for the k30
    board, which the monitor can use to compile the appropriate flash
    programming/erasing code, given that the k30 only uses on 8-bit
    flash chip instead of two chips that must be programmed at once
2022-02-11 Updated errata for k30
    [k30FlashWriter.ino]
2022-10-31 Revision 2 for k30-SBC minus a few fixes
    [Bus.kicad_sch, Bus.sch, IO.kicad_sch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]
2022-10-31 Upgraded project formats to kicad 6.0
    [68k-SMT.kicad_pcb, 68k-SMT.kicad_sch, 68k-SMT.sch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]
2022-11-14 Revision 2 of k30-SBC
    [Bus.kicad_sch, IO.kicad_sch, Logic.kicad_sch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]
2022-12-02 k30-SBC Revision 2 is complete
    [68k-SMT.kicad_pcb, Bus.kicad_sch, IO.kicad_sch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]
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2023-07-07 Identified issue with pull up resistor size for DSACK
    Also included an improvement of the fatal error message in the monitor
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
